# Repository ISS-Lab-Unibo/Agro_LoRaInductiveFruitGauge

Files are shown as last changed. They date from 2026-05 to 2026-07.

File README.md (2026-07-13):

# Agro_LoRaInductiveFruitGaug

A low-power wireless sensor node designed for high-resolution, non-destructive fruit growth monitoring and LoRa/LoRaWAN data transmission.
immagine

##Overview

The Agro LoRa Inductive Fruit Gauge is an autonomous sensor node developed for continuous and non-destructive fruit growth monitoring directly on the tree.

The system interfaces with up to eight inductive fruit gauges attached to the monitored fruits, periodically acquiring fruit diameter measurements and transmitting the collected data through a LoRa/LoRaWAN wireless communication interface.

The inductive sensing technology adopted by the fruit gauges provides a nominal diameter resolution of up to 71 µm over a 120 mm measurement range. Following the proposed non-linearity calibration procedure, the sensing system achieves a mean absolute diameter error of 111 µm and a maximum absolute diameter error below 247 µm.

The design and metrological characterization of the inductive fruit gauge are presented in:

> L. M. Peppi, A. Gallo, L. Manfrini, and L. De Marchi,
> “Inductive Sensor for Real-Time, Autonomous and Non-Destructive Fruit Size and Growth Monitoring,”
> *2025 IEEE International Workshop on Metrology for Agriculture and Forestry (MetroAgriFor)*, pp. 29–34, 2025.
> [IEEE Xplore](https://ieeexplore.ieee.org/document/11512426) | [DOI: 10.1109/MetroAgriFor66923.2025.11512426](https://doi.org/10.1109/MetroAgriFor66923.2025.11512426)

The high measurement resolution enables the detection of small fruit diameter variations associated with daily shrinkage and swelling cycles, making the system suitable for long-term fruit growth monitoring and plant water-status assessment in Precision Agriculture applications.

The repository contains all the hardware design files, embedded firmware, configuration software, and mechanical models required to reproduce and configure the proposed sensor node.

## Building the Sensor Node

Complete instructions for manufacturing, assembling, programming, and configuring the sensor node are provided in the dedicated building guide:

 **[Sensor Node Building Instructions](building_instructions.md)**

The guide describes the complete procedure required to reproduce the system, from PCB manufacturing and component assembly to firmware programming, fruit gauge assembly, and final node configuration.

## Repository Contents

The repository is organised into the following directories:

### [`3d models`](3d%20models)

Contains the mechanical design files required to manufacture the sensor node enclosure and the mechanical components of the fruit gauges.

The directory includes STL files for 3D printing and the corresponding editable CAD source files.

### [`Configuring software`](Configuring%20software)

Contains the software developed to configure and manage the sensor node.

The configuration software allows the main node parameters, sensor acquisition settings, and LoRa/LoRaWAN communication parameters to be configured before field deployment.

### [`Firmware`](Firmware)

Contains the embedded firmware of the sensor node.

The firmware implements fruit gauge acquisition, analog sensor acquisition, system power management, battery monitoring, and LoRa/LoRaWAN communication.

### [`Schematics and Gerbers`](Schematics%20and%20Gerbers)

Contains the electronic design and PCB manufacturing files.

The directory includes the electrical schematics and Gerber files required to manufacture the sensor node PCB.

### [`Images`](Images)

Contains photographs, diagrams, and graphical resources used throughout the repository documentation.

## Documentation

Each main directory contains dedicated `.md` documentation files describing the purpose of the provided files, their organisation, and the procedures required to use, manufacture, configure, or modify the corresponding system components.

Users are encouraged to refer to the documentation available in each directory before modifying the hardware, firmware, software, or mechanical components.

For the complete sensor node reproduction procedure, refer to the **[Sensor Node Building Instructions](building_instructions.md)**.

## How It Works

The sensor node periodically acquires measurements from the connected inductive fruit gauges. Each gauge estimates the fruit diameter by measuring the angular position between its two arms using a contactless inductive sensing technique.

The acquired SENT digital signals are decoded by the sensor node and converted into calibrated fruit diameter measurements. The collected data are subsequently processed and transmitted through the LoRa/LoRaWAN communication interface.

The low-power architecture of the node is designed to support autonomous and long-term field operation.

## System Composition

The complete system consists of:

* a low-power LoRa/LoRaWAN sensor node;
* up to eight high-resolution inductive fruit gauges;
* interfaces for additional analog sensors;
* an energy harvesting and battery power supply system;
* dedicated embedded firmware;
* sensor node configuration software;
* custom mechanical components and enclosures.

Detailed information about each subsystem is available in the corresponding repository directory.

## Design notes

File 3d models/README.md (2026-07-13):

# PLIERS PRODUCTION OVERVIEW and REQUIRED MATERIALS

This repository contains the design files, manufacturing files, and assembly references required for the gripper system and its integration with the pliers assembly.

## Folder Structure

### 1. `Grubber`
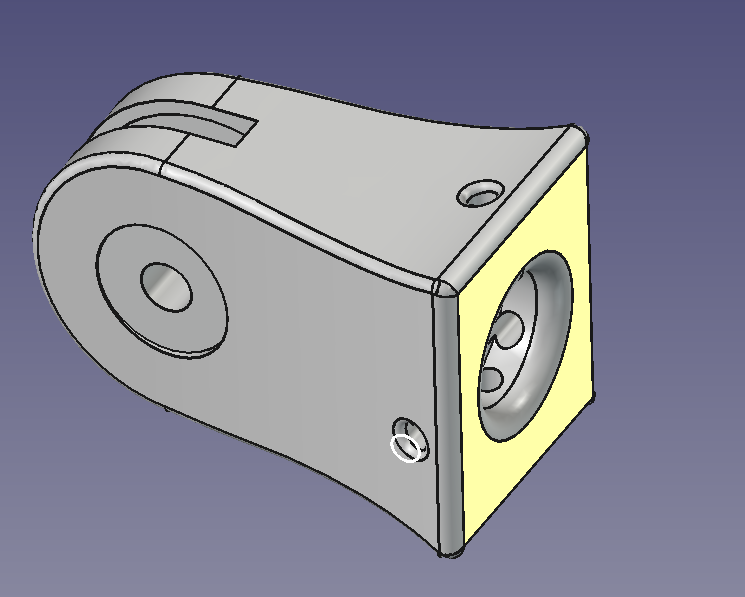
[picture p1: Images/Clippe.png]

This folder contains:

* FreeCAD CAD files of the grubbers that must be attached to the pliers.
* Printable `.stl` files corresponding to the grubber components.

These files are intended for manufacturing and assembly of the gripping elements.

---

### 2. `Pliers cad files and renderings`

This folder is provided **for reference purposes only**.

It contains:

* STEP files of the various pliers subassemblies and components.
* A complete rendering of the assembled pliers.
* The full pliers assembly in both STEP and FreeCAD formats.

These files are supplied to facilitate understanding of the overall assembly and integration of the grubbers.

---

### 3. `Teflon Disks`

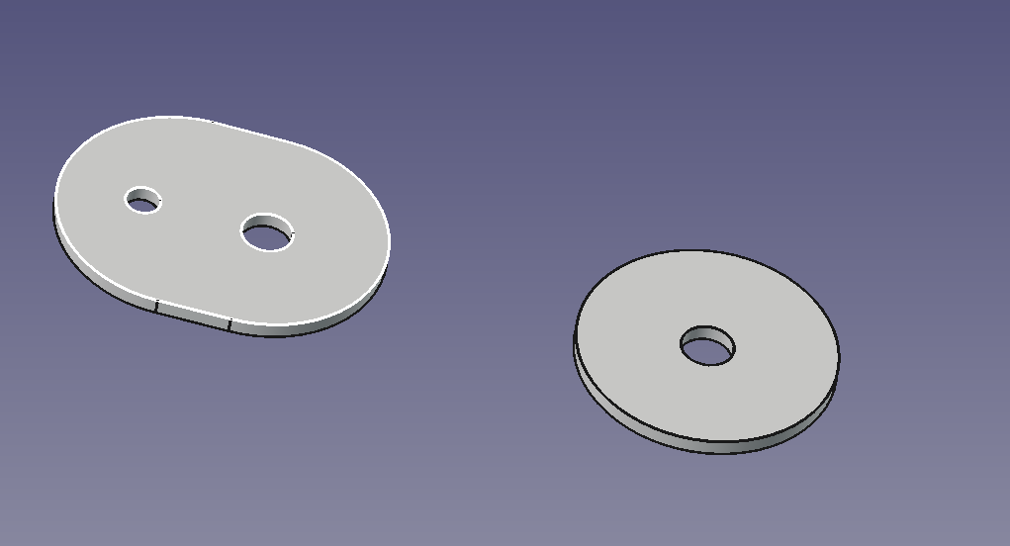
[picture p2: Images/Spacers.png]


This folder contains:

* `.stl` files of the spacers/disks that must be manufactured in PTFE (Teflon).

These components are required during the assembly of the pliers.

---

# Manufactured Parts List 

| Item | Part Name | Manufacturing Process (3D Printing / Machining) | Material | Quantity | File name|
| ---- | --- | --- | --- | --- | ----- |
|  1 | Grubbers 	| 3D printing | PETG | 2 |  clippa acciaio armonico-Body_v.02 |
|  2 |  Teflon spacer 1 | Machining |  Teflon 1mm thicknes | 2 |  Spessore_braccio.stl |
|  3 |  Teflon spacer 2 | Machining | Teflon 1mm thicknes |  2 |  Spessore_centrale.stl |

---

# Mechanical Hardware Bill of Materials (To Be Completed)

| Item | Description | Specification | Quantity | RS Code |
| ---- | --- | --- | --- | ----- |
|  1 | M2 bold | 1) To connect the grubbers to the plier's structure 2) to fix one arm of the plier |  3 |  560-271 |
| 2 | M2 screw 8mm |  To connect the grubbers to the plier's structure | 2 | 908-7637 |
| 3 |  RS 751-770, 0.63 mm Diam., ext Diam. 7mm, length 35mm, maximum length 101.5mm, k = 0.16N/mm, initial force = 12.2N | |  2 | |
| 4 |  M3 locknut | | 2 | |
| 5 |  M5 screw | | 2 | |
| 6 |  Self-tapping screw | | 2 | |
---

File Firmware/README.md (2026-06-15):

# Firmware

## STM32CubeIde_Project
this folder contains the STM32CubeIde Project, if you want to look at the source code.

Are you lazy? Do you want ony to flash the microcontrolloer? No problem: look at the..

## RAK3172_Ver_*<version>_<buil date>.hex file
Use it with STM32CubeProgrammer to flash the MCU. No building required.

## Chirpstack_decoder.js
If you use Chirpstack as LoRa server, use this Javascript to decode the received LoRa payload.

## lx3302a_config
File to be written into the LX3302A IC, with the MIcrochip LXM9518 Gen2 Programmer

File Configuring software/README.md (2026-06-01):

## Software for sensor node setup

### Python files
Source code of the software

### dist-windows-exe
No desire to mess around with Python code? I understand... that’s why there’s an executable file available (Windows only!) that doesn’t require any kind of runtime. Just download the "dist-windows-exe" folder (with the "ui" folder inside!) and execute the .exe file, and you’re all set.

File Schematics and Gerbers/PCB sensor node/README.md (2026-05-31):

## Design and production files for the pliers

### KiCad project
This folder contains the KiCad project files for the design of the pliers.

### Gerber production files
This folder contains a .ZIP file with all the Gerber files required for the manufacture of the pliers by external suppliers. It also includes the BOM and component placement (CPL) files.

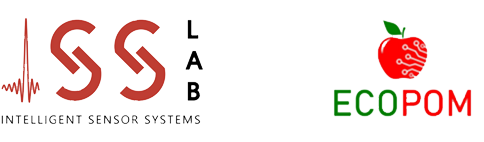
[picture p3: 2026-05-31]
Configuring software/python files/img/ISS-ECOPOM.png

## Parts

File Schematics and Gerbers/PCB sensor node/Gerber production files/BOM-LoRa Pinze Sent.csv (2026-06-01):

Comment | Designator | Footprint | LCSC | Quantity
0.47u | C2 | C_0603_1608Metric_Pad1.08x0.95mm_HandSolder | C1623 | 1
10 | R20,R21,R22,R23 | R_0402_1005Metric | C25077 | 4
100k | R13,R14,R15,R24,R25 | R_0402_1005Metric | C25741 | 5
100n | C1,C10,C11,C15,C20,C21,C22,C3,C34,C35,C36,C41,C42,C5,C7,C87,Cbyp1 | C_0402_1005Metric_Pad0.74x0.62mm_HandSolder | C1525 | 17
100p | C26 | C_0402_1005Metric_Pad0.74x0.62mm_HandSolder | C1546 | 1
10k | R10,R4,R5,R9 | R_0402_1005Metric | C25744 | 4
10n | C30,Cref1 | C_0402_1005Metric_Pad0.74x0.62mm_HandSolder | C15195 | 2
10p | C24,C37,C38,C44,C47,C51,C53,C56,C59,C62,C65,C68,C70,C72 | C_0402_1005Metric_Pad0.74x0.62mm_HandSolder | C32949 | 14
12k | R47,R49,R51,R53,R55,R57,R59,R61,R63,R65,R67,R69,R71,R73,R75,R77 | R_0402_1005Metric | C25752 | 16
1k | R79 | R_0402_1005Metric | C11702 | 1
1u | C12,C13,C23,C39,C4,C40,C43,C45,C46,C48,C49,C50,C52,C54,C55,C57,C58,C60,C61,C63,C64,C66,C67,C69,C71,C73,C8 | C_0402_1005Metric_Pad0.74x0.62mm_HandSolder | C52923 | 27
200k | R18,R19 | R_0402_1005Metric | C25764 | 2
220 | R1,R30 | R_0402_1005Metric_Pad0.72x0.64mm_HandSolder | C25091 | 2
22k | R48,R50,R52,R54,R56,R58,R60,R62,R64,R66,R68,R70,R72,R74,R76,R78 | R_0402_1005Metric | C25768 | 16
22u | C17 | C_0805_2012Metric_Pad1.18x1.45mm_HandSolder | C45783 | 1
2k2 | R6,R7 | R_0402_1005Metric | C25879 | 2
3,9M | Rok3 | R_0402_1005Metric_Pad0.72x0.64mm_HandSolder | C30329 | 1
3.3p | C28,C29 | C_0402_1005Metric_Pad0.74x0.62mm_HandSolder | C1565 | 2
33 | R28,R29 | R_0402_1005Metric | C25105 | 2
4,3M | Roc1 | R_0402_1005Metric_Pad0.72x0.64mm_HandSolder | C327242 | 1
4.7M | Rout2 | R_0402_1005Metric_Pad0.72x0.64mm_HandSolder | C49654986 | 1
4.7u | C16 | C_0402_1005Metric_Pad0.74x0.62mm_HandSolder | C23733 | 1
4u7 | C6,C9 | C_0402_1005Metric_Pad0.74x0.62mm_HandSolder | C23733 | 2
5,62M | Rov2 | R_0402_1005Metric_Pad0.72x0.64mm_HandSolder | C2929925 | 1
53398-0371 | J5,J6,J7,J8 | 533980371 | C17246903 | 4
53398-0471 | J10,J11,J12,J13,J14,J15,J16,J9 | 533980471 | C17617036 | 8
56k | R31,R32 | R_0402_1005Metric | C23206 | 2
6,2M | Roc2 | R_0402_1005Metric_Pad0.72x0.64mm_HandSolder | C159000 | 1
6,8M | Rok2 | R_0402_1005Metric_Pad0.72x0.64mm_HandSolder | C620473 | 1
7,5M | Rov1 | R_0402_1005Metric_Pad0.72x0.64mm_HandSolder | C137839 | 1
744031220 | L4 | WE-TPC_381692 | C5523436 | 1
74479889310 | L5 | INDC2521X120N | C191565 | 1
8,2M | Rout1 | R_0402_1005Metric_Pad0.72x0.64mm_HandSolder | C172186 | 1
910k | Rok1 | R_0402_1005Metric_Pad0.72x0.64mm_HandSolder | C324817 | 1
BAV199 | D1,D2,D21,D22,D23,D24,D25,D26,D27,D28,D29,D3,D30,D31,D32,D33,D34,D35,D36,D4 | SOT95P230X100-3N | C145516 | 20
BLM15HG102SN1D | FB1,FB2,FB3 | NFZ15SG152SN10B | C76889 | 3
BQ25570 | U2 | QFN-20-1EP_3.5x3.5mm_P0.5mm_EP2x2mm | C506250 | 1
C0805C475K9RACTU 4,7u | C31 | C0805 | C1779 | 1
CH340E | U3 | MSOP-10_3x3mm_P0.5mm | C99652 | 1
DFE201612E-2R2M=P2 | L2 | 1286ASH1R0MP2 | C337893 | 1
GT-USB-7055BB | J17 | GTUSB7055BB | C7450621 | 1
JMK212BJ226MG-T 22u | C33 | CAPC2013X135N | C87158 | 1
KT-0603R | LED1,LED2 | LEDC1608X70N | C2286 | 2
LMK212B7475KG-T | C32 | CAPC2012X135N | C92810 | 1
LQW15AN8N2J00D | L3 | LQW15CNR20J00B | C98066 | 1
MLZ2012N150LT000 | L1 | INDC2012X105N | C531290 | 1
NCP115ASN330T2G | IC11 | SOT95P275X110-5N | C603505 | 1
RAK3172-SiP | IC1 | RAK3172SiP | C19818882 | 1
Reset(Black) | B2 | TS046655BK160SMT | C5340119 | 1
SN74HCS151PWR | IC12,IC5 | SOP65P640X120-16N | C2877065 | 2
TCA9534PWR | IC6 | SOP65P640X120-16N | C783615 | 1
TMUX1204DGSR | IC7 | SOP50P490X110-10N | C2840022 | 1
TMUX1219DCKR | IC25,IC8,IC9 | SOT65P210X110-6N | C2867958 | 3
TPS22917DBVR | IC13,IC14,IC15,IC16,IC17,IC18,IC19,IC20,IC21,IC22,IC23,IC24 | SOT95P280X145-6N | C2681320 | 12
TPS613222ADBVR | IC2 | SOT95P280X145-5N | C2071163 | 1
U.FL-R-SMT-1_10_ | J4 | U.FL-R-SMT-1_10_ | C88374 | 1
USBLC6-2SC6 | IC10 | SOT95P280X145-6N | C2827654 | 1

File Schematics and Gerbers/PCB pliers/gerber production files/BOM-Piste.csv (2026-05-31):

Comment | Designator | Footprint | LCSC | Quantity
100n | C2,C6,C7 | C_0402_1005Metric_Pad0.74x0.62mm_HandSolder | C1525 | 3
10k | R4,R5 | R_0402_1005Metric_Pad0.72x0.64mm_HandSolder | C25744 | 2
1n | C1 | C_0402_1005Metric_Pad0.74x0.62mm_HandSolder | C1523 | 1
1u | C3 | C_0402_1005Metric_Pad0.74x0.62mm_HandSolder | C52923 | 1
56k | R6 | R_0402_1005Metric_Pad0.72x0.64mm_HandSolder | C25796 | 1
680p | C4,C5 | C_0402_1005Metric_Pad0.74x0.62mm_HandSolder | C1630 | 2
LX3302AQPW-TR | IC1 | SOP65P640X120-14N | C3237416 | 1
MCP6541T-I_OT | IC2 | SOT95P270X145-5N | C80839 | 1
LMT01DQX | U1 | Texas_DQX002A |  | 1

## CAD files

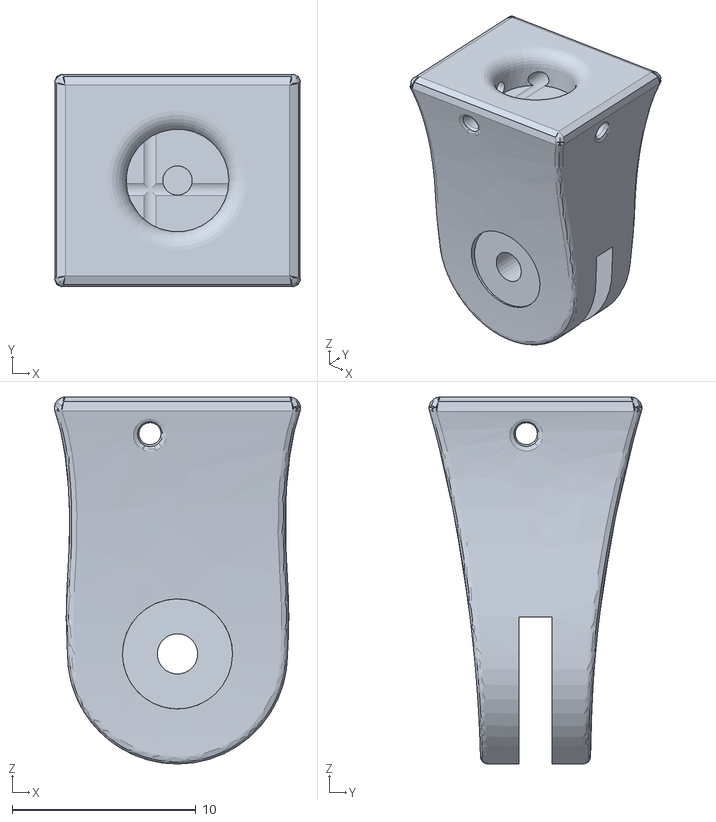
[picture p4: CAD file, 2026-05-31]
3d models/Grubber/clippa acciaio armonico-Body_v.02.stl
13.4 x 11.6 x 20.0

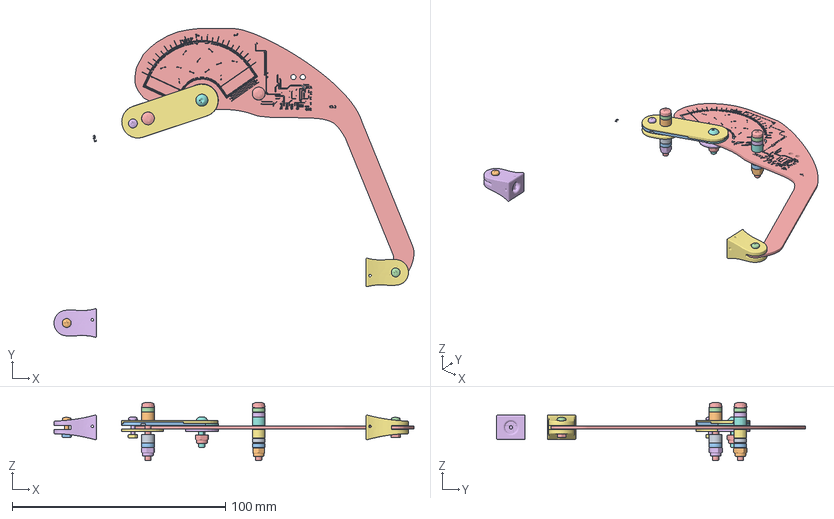
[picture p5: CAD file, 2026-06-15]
3d models/Pliers cad files and renderings/Rendering.FCStd
168.7 x 144.6 x 27.4 mm
TargetGrande_silkscreen
spacerGrande_silkscreen
spacerGrande_PCB
Braccio_silkscreen
AutobloccanteM3
BulloneM2
DadoM2
DadoM310mm
distanziale4mm
distanziale4mm001
distanziale2mm
distanziale2mm001
BN 3334 1538667 cross recessed pan head machine screw M3x25
AutobloccanteM001
SpacerGrande
B0528.1503X12
Piste_copper
Piste_via
Piste_silkscreen
Piste_silkscreen001
Piste_PCB
distanziale2mm002
distanziale4mm002
distanziale4mm003
distanziale2mm003
AutobloccanteM002
distanziale2mm004
distanziale2mm005
BN 3334 1538667 cross recessed pan head machine screw M3x001
Rondellona
SpacerBraccio001
Rondellona2
SpacerBraccio002
BulloneM001
DadoM002
BulloneM002
DadoM003
clippa acciaio armonico-Body
clippa acciaio armonico-Body001

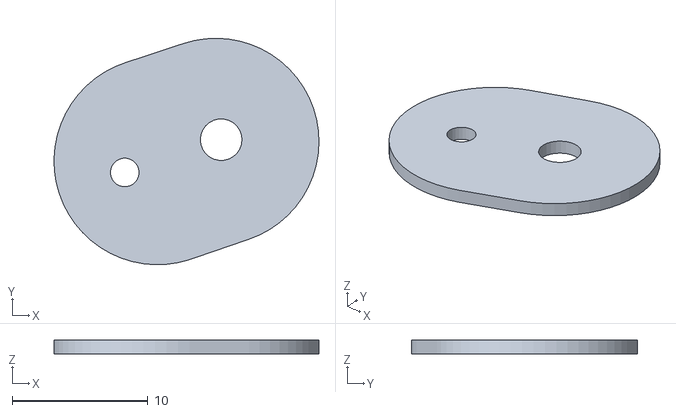
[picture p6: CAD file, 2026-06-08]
3d models/Teflon disks/Spessore_braccio.stl
19.5 x 16.7 x 1.00

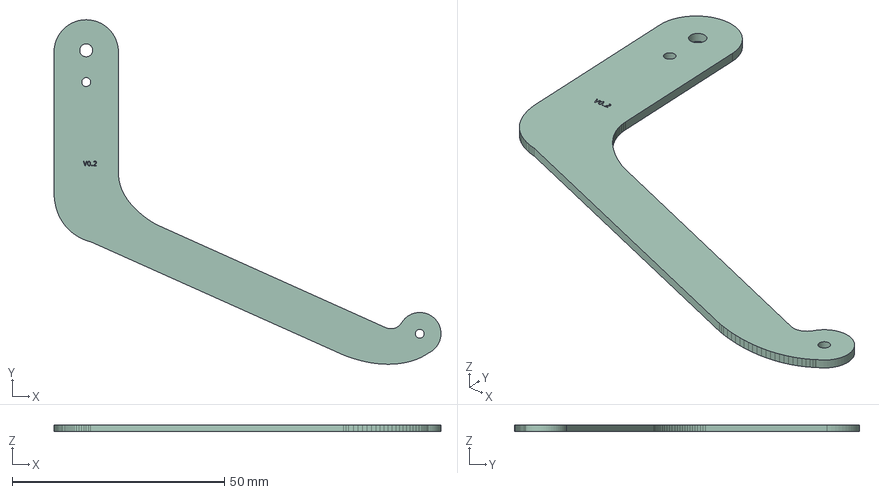
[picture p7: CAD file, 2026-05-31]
3d models/Pliers cad files and renderings/Braccio.step
91.2 x 81.2 x 1.58 mm
Braccio_silkscreen
Braccio_PCB

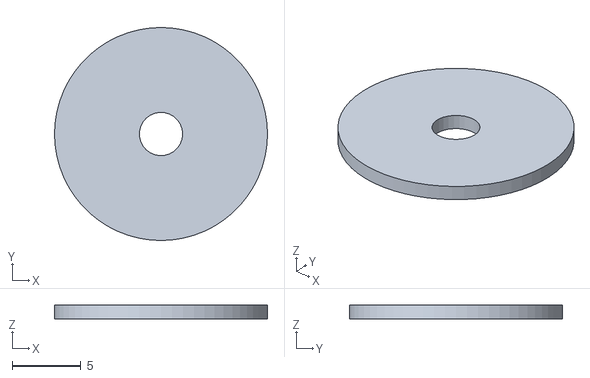
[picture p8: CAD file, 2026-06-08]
3d models/Teflon disks/Spessore_centrale.stl
15.5 x 15.5 x 1

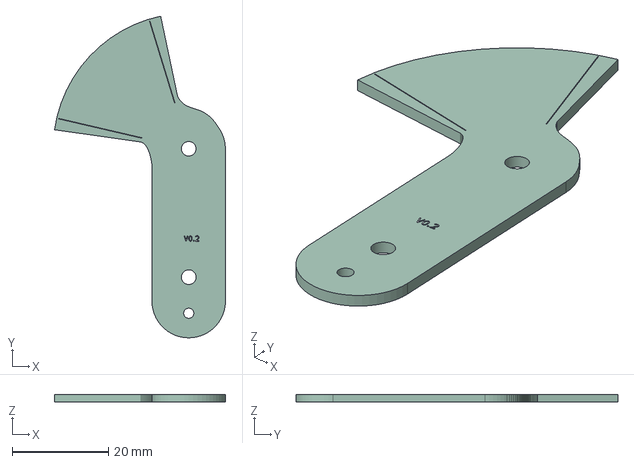
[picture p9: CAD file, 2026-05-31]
3d models/Pliers cad files and renderings/Target.step
35.5 x 66.7 x 1.58 mm
TargetGrande_silkscreen
TargetGrande_PCB

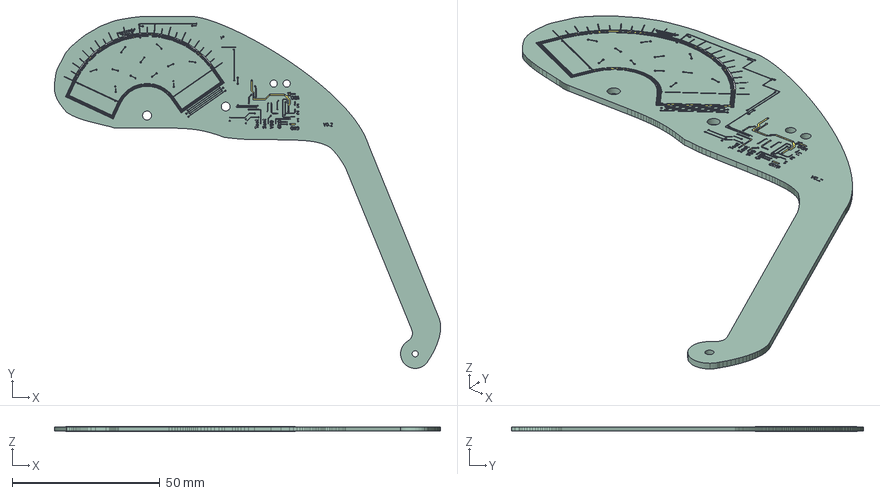
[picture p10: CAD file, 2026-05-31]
3d models/Pliers cad files and renderings/Piste.step
130.8 x 119.2 x 1.66 mm
Piste_copper
Piste_via
Piste_silkscreen x 2
Piste_PCB

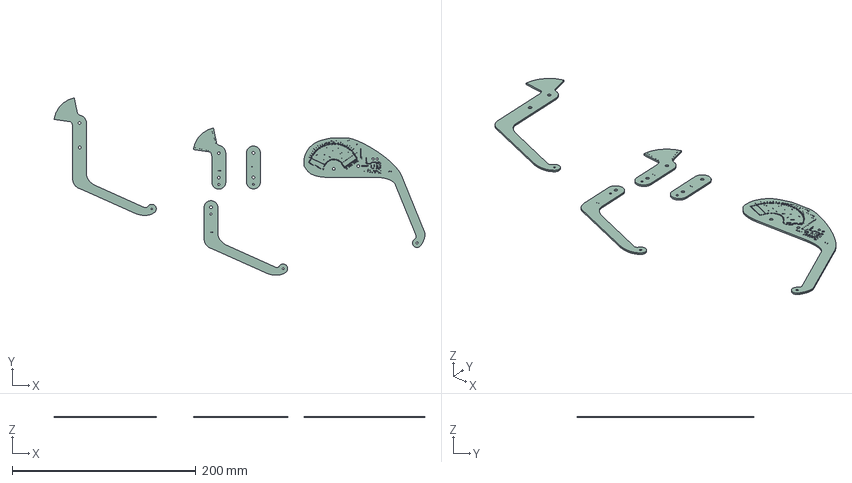
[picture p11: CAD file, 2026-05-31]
3d models/Pliers cad files and renderings/All_outline.step
404.1 x 193.3 x 1.66 mm
BraccioPisteMCU_stampa_copper
BraccioPisteMCU_stampa_via
BraccioPisteMCU_stampa_silkscreen x 2
BraccioPisteMCU_stampa_PCB_1
BraccioPisteMCU_stampa_PCB_2
BraccioPisteMCU_stampa_PCB_3
BraccioPisteMCU_stampa_PCB_4
BraccioPisteMCU_stampa_PCB_5

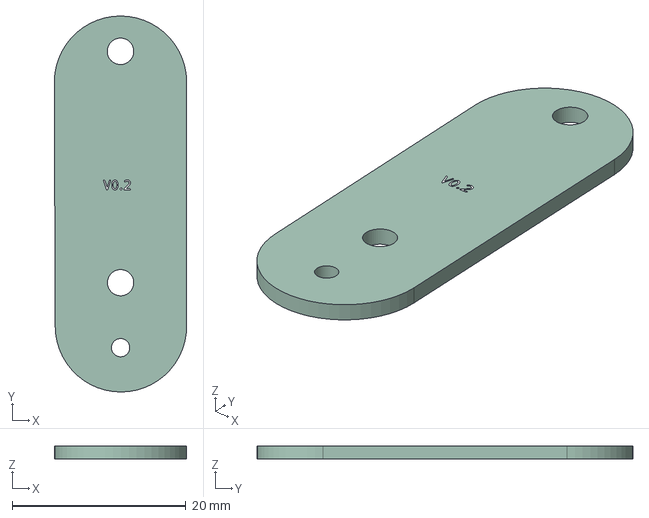
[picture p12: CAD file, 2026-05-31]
3d models/Pliers cad files and renderings/Spacer.step
15.2 x 43.3 x 1.58 mm
spacer_silkscreen
spacer_PCB

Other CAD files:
3d models/Grubber/clippa acciaio armonico_v.02.FCStd

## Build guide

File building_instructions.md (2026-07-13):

# Sensor Node Building Instructions

This document describes the main steps required to manufacture, program, and mechanically assemble the Agro LoRa Inductive Fruit Gauge sensor node and the associated inductive fruit gauges.

The procedure is organised into four main stages:

1. Required materials and tools
2. Sensor node PCB programming
3. Inductive fruit gauge programming
4. Mechanical assembly of the fruit gauges

---

# 1. Required Materials and Tools

Before starting the assembly procedure, all the electronic, mechanical, and programming components listed in the following table should be available.

| Category | Item | Description / Part Number | Quantity |
| --- | --- | --- | --- |
| PCB | Assembled sensor node PCB | PCB manufactured from the Gerber files available in [`Schematics and Gerbers/PCB sensor node`](Schematics%20and%20Gerbers/PCB%20sensor%20node) | 1 |
| PCB | Inductive fruit gauge PCB | PCB manufactured from the Gerber files available in [`Schematics and Gerbers/PCB pliers`](Schematics%20and%20Gerbers/PCB%20pliers). 1X GERBER-Braccio, 1X GERBER-Piste, 1X GERBER-spacer, 1x GERBER-TargetGrande. | 1 set per fruit gauge |
| 3D printed part | Fruit gripping elements | `clippa acciaio armonico-Body_v.02.stl`, available in [`3d models/Grubber`](3d%20models/Grubber) | 2 per fruit gauge |
| Mechanical material | PTFE sheet | 1 mm thick PTFE (Teflon) sheet. The sheet must be machined according to the geometries provided in the [`Teflon disks`](3d%20models/Teflon%20disks) directory | 2 set per fruit gauge |
| Mechanical hardware | M2 nut | M2 nut used for the fruit gauge mechanical assembly. RS Code 908-7637 | 3 per fruit gauge |
| Mechanical hardware | M2 screw | M2 × 8 mm screw used to connect the gripping elements to the fruit gauge structure + . RS code  560-271 | 3 per fruit gauge |
| Mechanical hardware | M3 locknut | M3 locknut used for the fruit gauge mechanical assembly. RS Code 521-917 | 3 per fruit gauge |
| Mechanical hardware | M3 screw | M3 × 25 mm screw. RS code  560-271 | 3 per fruit gauge |
| Mechanical hardware | Self-tapping screw | Required to fix harmonic steel to grippers. RS code  287-4014 | 2 per fruit gauge |
| Mechanical hardware | Spring | RS 751-770, 0.63 mm Diam., ext Diam. 7mm, length 35mm, maximum length 101.5mm, k = 0.16N/mm, initial force = 12.2N | 2 per fruit gauge |
| Mechanical hardware | harmonic steel wire |  Diam harmonic steel wire | 4 per fruit gauge |
| Mechanical hardware | **TO BE COMPLETED** | **Additional central joint hardware / bearing specifications to be added** | **TBD** |
| Enclosure | **ENCLOSURE PART NUMBER TO BE ADDED** | Weather-resistant enclosure for the sensor node electronics | 1 |
| Battery | Battery | | 1 per sensor node |
| Connector | Fruit gauge connector | Connector used to connect each inductive fruit gauge to the sensor node | 1 per fruit gauge |
| Cable | UNITRONIC® LiYY | LAPP 0028304 cable used to connect the inductive fruit gauges to the sensor node | As required |
| Programmer | LXM9518 | Microchip programmer for the LX3302A inductive position sensor interface IC | 1 |
| MCU programmer | ST-LINK or SEGGER programmer | SWD-compatible programmer for programming the sensor node MCU | 1 |
| Software | STM32CubeProgrammer | ST software used to program the sensor node MCU | — |
| Software | IPCE | Microchip Integrated Programming and Calibration Environment used with the LXM9518 programmer | — |

The UNITRONIC® LiYY LAPP 0028304 cable is used for the electrical connection between each fruit gauge and the sensor node. Its PVC-based cable construction is suitable for the proposed outdoor installation and is adopted to improve the robustness of the sensor interconnection against environmental exposure, including sunlight and the associated UV radiation.

> **Note:** The exact sensor node enclosure part number must be added before finalising this document.
---

# 2. PCB Manufacturing

The system requires different PCB designs:

* the main sensor node PCB;
* the inductive fruit gauge PCB.

The corresponding manufacturing files are provided in the [`Schematics and Gerbers`](Schematics%20and%20Gerbers) directory.

## 2.1 Sensor Node PCB

The sensor node PCB manufacturing files are available in:

[`Schematics and Gerbers/PCB sensor node`](Schematics%20and%20Gerbers/PCB%20sensor%20node)

The `Gerber production files` directory contains the files required for PCB manufacturing and assembly

The provided production package includes the Gerber files and the associated BOM and component placement information required by an external PCB assembly service. Remember the assembly for the GERBER-LoRa Pinze Sent PCB. Bill of Materials and placement files are available in the same folder.

## 2.2 Inductive Fruit Gauge PCB

The fruit gauge PCB manufacturing files are available in:

[`Schematics and Gerbers/PCB pliers`](Schematics%20and%20Gerbers/PCB%20pliers): 
1X GERBER-Braccio, 1X GERBER-Piste, 1X GERBER-spacer, 1x GERBER-TargetGrande

The corresponding Gerber production files must be used to manufacture the PCB forming the main structural and sensing elements of the inductive fruit gauge.

The PCB integrates the inductive sensing coils and the LX3302A-based acquisition electronics. Remember the assembly for the GERBER-Piste PCB. Bill of Materials and placement files are available in the same folder.

---

# 3. Sensor Node MCU Programming

The sensor node MCU must be programmed before the final assembly of the system.

The recommended programming procedure uses STM32CubeProgrammer and an SWD-compatible programmer, such as an ST-LINK or a SEGGER programming probe.

## 3.1 Required Software

Download and install STM32CubeProgrammer from the official STMicroelectronics website.

The precompiled firmware binary provided in the [`Firmware`](Firmware) directory is the recommended firmware image for reproducing the sensor node.

The complete firmware source code is also available in the repository. Advanced users may download the source code, configure the development environment, and compile the firmware independently.

However, **building the firmware from source is not recommended for standard sensor node reproduction**, since compiler versions, library dependencies, and project configuration may affect the resulting firmware behaviour.

For this reason, the provided precompiled firmware image should normally be used.

## 3.2 Connecting the Programmer

Connect the ST-LINK or SEGGER programmer to the sensor node programming interface.

The sensor node programming connector pinout is reported in the following table. **Pin 1 is identified on the PCB by a white dot printed next to the connector.**

| Pin | Signal | Description |
| --- | --- | --- |
| 1 | `VDD_TARGET` | Target voltage sensing input. Used by the programming probe to measure the target voltage. This connection is optional and can normally be left disconnected when the sensor node is powered separately. |
| 2 | `SWCLK` | Serial Wire Debug clock line. |
| 3 | `GND` | Ground reference. |
| 4 | `SWDIO` | Serial Wire Debug bidirectional data line. |
| 5 | `NRST` | MCU hardware reset line. |
| 6 | `NC` | Not connected. |

> **Note:** Pin 1 (`VDD_TARGET`) is marked on the sensor node PCB by a **white dot**, which can be used as a reference to determine the programming connector orientation.

### Programming connection

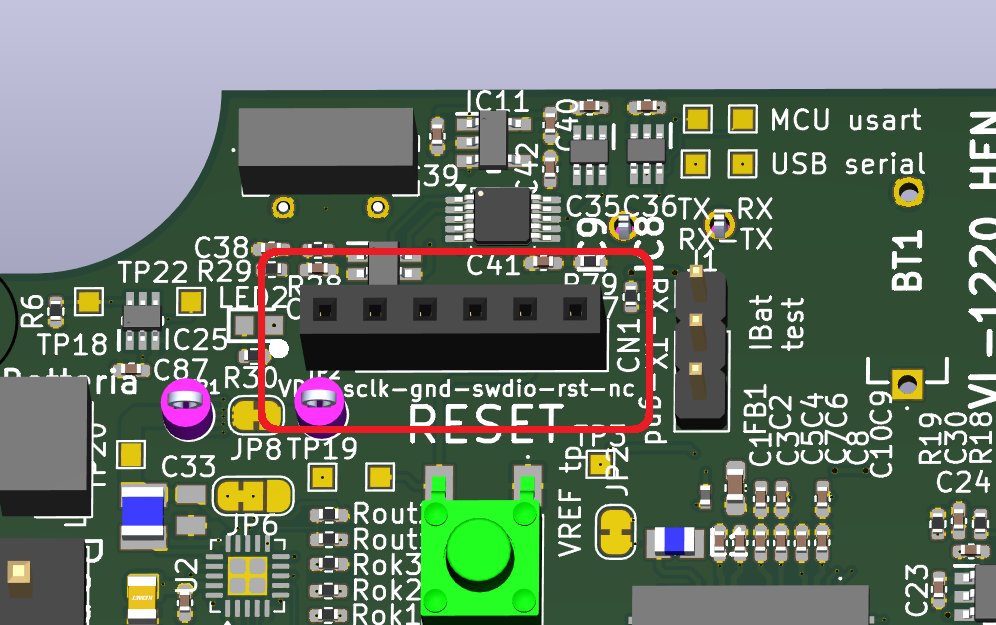
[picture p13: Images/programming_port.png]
Logo di esempio


*Figure X. Connection of the programming probe to the sensor node PCB.*

## 3.3 Programming with STM32CubeProgrammer

The following procedure can be used to program the sensor node:

1. Connect the programming probe to the sensor node PCB.
2. Connect the programmer to the computer.
3. Open STM32CubeProgrammer.
4. Select `ST-LINK` as the programming interface when using an ST-LINK probe.
5. Configure the SWD connection.
6. Press **Connect**.
7. Verify that the target MCU is correctly detected.
8. Open the firmware programming section.
9. Select the precompiled firmware file provided in the repository.
10. Verify the firmware start address according to the supplied firmware image.
11. Start the programming procedure.
12. Wait for the programming and verification process to complete.
13. Disconnect STM32CubeProgrammer.
14. Remove the programming probe from the sensor node.

### STM32CubeProgrammer — Step 1

<!-- INSERT IMAGE: STM32CubeProgrammer connection configuration -->

STM32CubeProgrammer connection

*Figure X. STM32CubeProgrammer connection configuration.*

### STM32CubeProgrammer — Step 2

<!-- INSERT IMAGE: Firmware file selection -->

STM32CubeProgrammer firmware selection

*Figure X. Selection of the precompiled sensor node firmware.*

### STM32CubeProgrammer — Step 3

<!-- INSERT IMAGE: Programming and verification -->

STM32CubeProgrammer programming

*Figure X. Firmware programming and verification.*

After programming, disconnect the programming probe and power-cycle the sensor node.

---

# 4. LX3302A Programming

Each inductive fruit gauge integrates a Microchip LX3302A inductive position sensor interface IC.

Before the fruit gauge can be used, the LX3302A must be programmed with the appropriate sensor configuration.

Programming is performed using the Microchip LXM9518 programmer and the Integrated Programming and Calibration Environment (IPCE).

The LXM9518 programmer is described on the Microchip website:

[LXM9518 Programmer](https://www.microchip.com/en-us/development-tool/lxm9518)

## 4.1 Required Equipment

The following components are required:

* one LXM9518 programmer;
* the Microchip IPCE software;
* the inductive fruit gauge PCB;
* the appropriate programming cable or adapter.

## 4.2 Connecting the Fruit Gauge

During programming, the programming connector must be manually held against the programming contacts available on the fruit gauge PCB.

The connector must remain correctly positioned and in electrical contact with the PCB for the entire programming procedure.

The required connector position is shown in the following figures.

### Programming connector position

<!-- INSERT IMAGE: Programming connector held against the fruit gauge -->

LX3302A programming connector

*Figure X. Programming connector manually held against the fruit gauge programming interface.*

### Detail of the programming contacts

<!-- INSERT IMAGE: Detail of programming pads -->

LX3302A programming pads

*Figure X. Detail of the LX3302A programming contacts.*

> **Important:** The programming connector must be kept firmly in position by hand throughout the programming procedure. An intermittent electrical contact may interrupt communication with the LX3302A.

A dedicated pogo-pin programming fixture is currently under development. This fixture will simplify the programming procedure and provide a more repeatable electrical connection to the fruit gauge programming pads.

## 4.3 Programming with IPCE

Connect the LXM9518 programmer to the computer and start the Microchip IPCE software.

The recommended programming procedure is:

1. Connect the LXM9518 programmer to the computer.
2. Open IPCE.
3. Position the programming connector on the fruit gauge programming contacts.
4. Keep the connector firmly pressed against the PCB.
5. Verify that the LX3302A is detected by IPCE.
6. Load the LX3302A configuration provided with this repository.
7. Verify the programmed sensor parameters.
8. Start the EEPROM programming procedure.
9. Wait until the programming process has completed.
10. Verify the programmed configuration.
11. Remove the programming connector from the fruit gauge.

### IPCE — Device connection

<!-- INSERT IMAGE: IPCE device detection -->

IPCE device connection

*Figure X. LX3302A detection using the IPCE software.*

### IPCE — Configuration loading

<!-- INSERT IMAGE: IPCE configuration loading -->

IPCE configuration loading

*Figure X. Loading the LX3302A configuration.*

### IPCE — EEPROM programming

<!-- INSERT IMAGE: LX3302A EEPROM programming -->

IPCE programming

*Figure X. Programming the LX3302A internal configuration memory.*

The LXM9518 and IPCE are specifically intended for configuration and calibration of Microchip inductive position sensor ICs. The LX3302A stores its digital calibration and configuration parameters in non-volatile EEPROM.

---

# 5. Fruit Gauge Mechanical Assembly

After the PCB has been manufactured and the LX3302A programmed, the mechanical components of the fruit gauge can be assembled.

The mechanical design files are available in the [`3d models`](3d%20models) directory.

## 5.1 Manufacturing the PTFE Spacers

The fruit gauge uses PTFE spacers to reduce friction between the moving PCB elements and allow smooth relative rotation of the two arms.

A **1 mm thick PTFE sheet** must be machined according to the geometries provided in the [`Teflon disks`](3d%20models/Teflon%20disks) directory.

The following spacer geometries are provided:

* `Spessore_braccio.stl/.svg`;
* `Spessore_centrale.stl/.svg`.

The STL or SVG files define the required external geometry of the PTFE components and can be used as a dimensional reference for machining or cutting the 1 mm PTFE sheet.

Two units of each spacer geometry are required for the complete fruit gauge assembly.

### PTFE spacer geometry

PTFE spacer geometry

*Figure X. PTFE spacer geometries manufactured from a 1 mm thick PTFE sheet.*

## 5.2 Manufacturing the Fruit Gripping Elements

Two fruit gripping elements must be manufactured for each fruit gauge.

The printable STL file is available in the [`Grubber`](3d%20models/Grubber) directory:

`clippa acciaio armonico-Body_v.02.stl`

The corresponding editable FreeCAD source file is also provided.

The gripping elements should be 3D printed in PETG.

CLIPPE geometry

Two identical components are required for each fruit gauge.

Each fruit gripping element must be equipped with two spring steel wires. The two wires must pass through the dedicated holes provided inside each gripper and be secured in position using a self-tapping screw.

After installation, the spring steel wires must be bent to form a suitable gripping profile, allowing them to gently engage with the fruit surface and keep the fruit gauge correctly positioned during the monitoring period.

If required, the portions of the spring steel wires that come into contact with the fruit can be covered with heat-shrink tubing. This can provide a softer contact surface and reduce direct contact between the metal wires and the fruit skin.

<!-- INSERT IMAGE: Spring steel wire installation and bending -->

Spring steel wire installation

*Figure X. Installation, fastening, and bending of the spring steel wires inside the fruit gripping element.*

## 5.3 Mechanical Assembly

The different components must be assembled according to the exploded view shown below.

### Fruit gauge exploded view

<!-- INSERT IMAGE: Complete exploded view -->

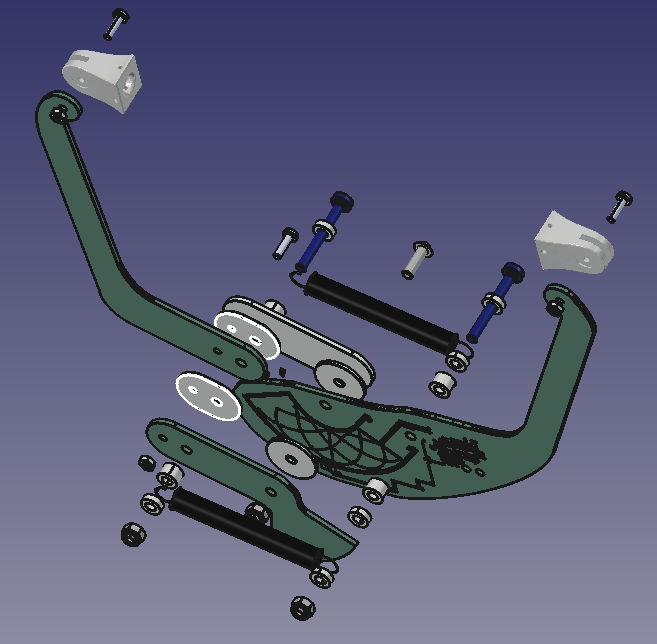
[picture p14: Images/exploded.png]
Fruit gauge exploded view


*Figure X. Exploded view of the inductive fruit gauge assembly.*

The recommended assembly sequence is as follows:

1. Prepare the two fruit gauge PCB arms.
2. Position the PTFE spacers according to the exploded view.
3. Align the central rotation interfaces of the two PCB arms.
4. Install the central mechanical joint components.
5. Assemble the two PCB arms while ensuring free relative rotation.
6. Install the two PETG fruit gripping elements.
7. Fix each gripping element using the M2 × 8 mm screws and M2 nuts.
8. Verify the alignment of the two fruit gripping elements.
9. Manually open and close the fruit gauge.
10. Verify that the two arms rotate smoothly and without significant mechanical interference.

The PTFE components must remain correctly positioned between the moving surfaces during assembly.

After tightening the mechanical fasteners, verify that the fruit gauge can move freely throughout its operating range.

Excessive tightening of the central joint may increase friction and negatively affect the detection of small fruit diameter variations.

---

# 6. Final Assembly

Once the fruit gauges and the sensor node have been programmed and mechanically assembled, the system can be interconnected.

Connect each inductive fruit gauge to the sensor node using the UNITRONIC® LiYY LAPP 0028304 cable and the selected connectors.

Verify the cable wiring and connector pinout before connecting the fruit gauge to the sensor node.

### Fruit gauge cable connection

<!-- INSERT IMAGE: Cable connection between fruit gauge and sensor node -->

Fruit gauge cable connection

*Figure X. Connection between an inductive fruit gauge and the sensor node.*

Install the sensor node PCB inside the selected **ENCLOSURE PART NUMBER TO BE ADDED** enclosure.

After completing the assembly, verify:

* sensor node power-up;
* communication with each connected fruit gauge;
* valid SENT data acquisition;
* LoRa/LoRaWAN configuration;
* wireless data transmission.

The sensor node can then be configured using the dedicated software provided in the [`Configuring software`](Configuring%20software) directory.

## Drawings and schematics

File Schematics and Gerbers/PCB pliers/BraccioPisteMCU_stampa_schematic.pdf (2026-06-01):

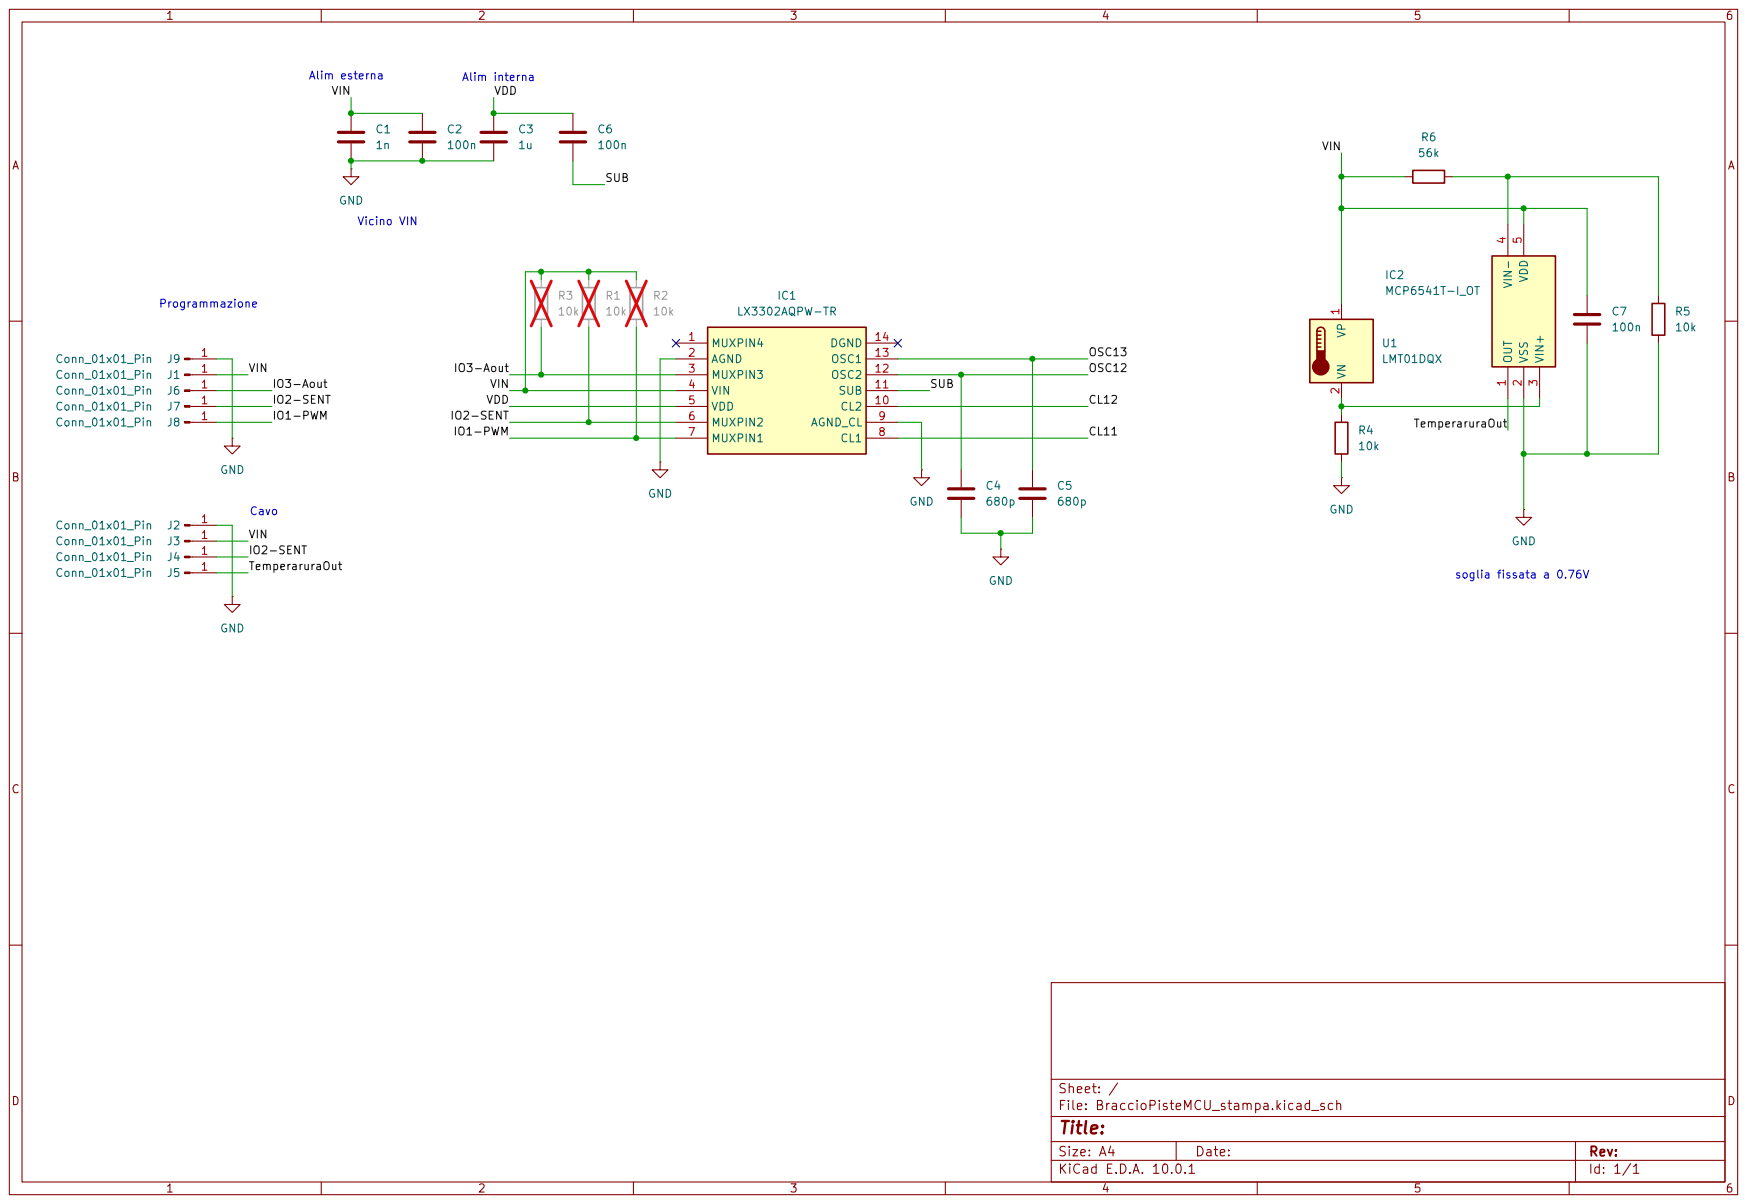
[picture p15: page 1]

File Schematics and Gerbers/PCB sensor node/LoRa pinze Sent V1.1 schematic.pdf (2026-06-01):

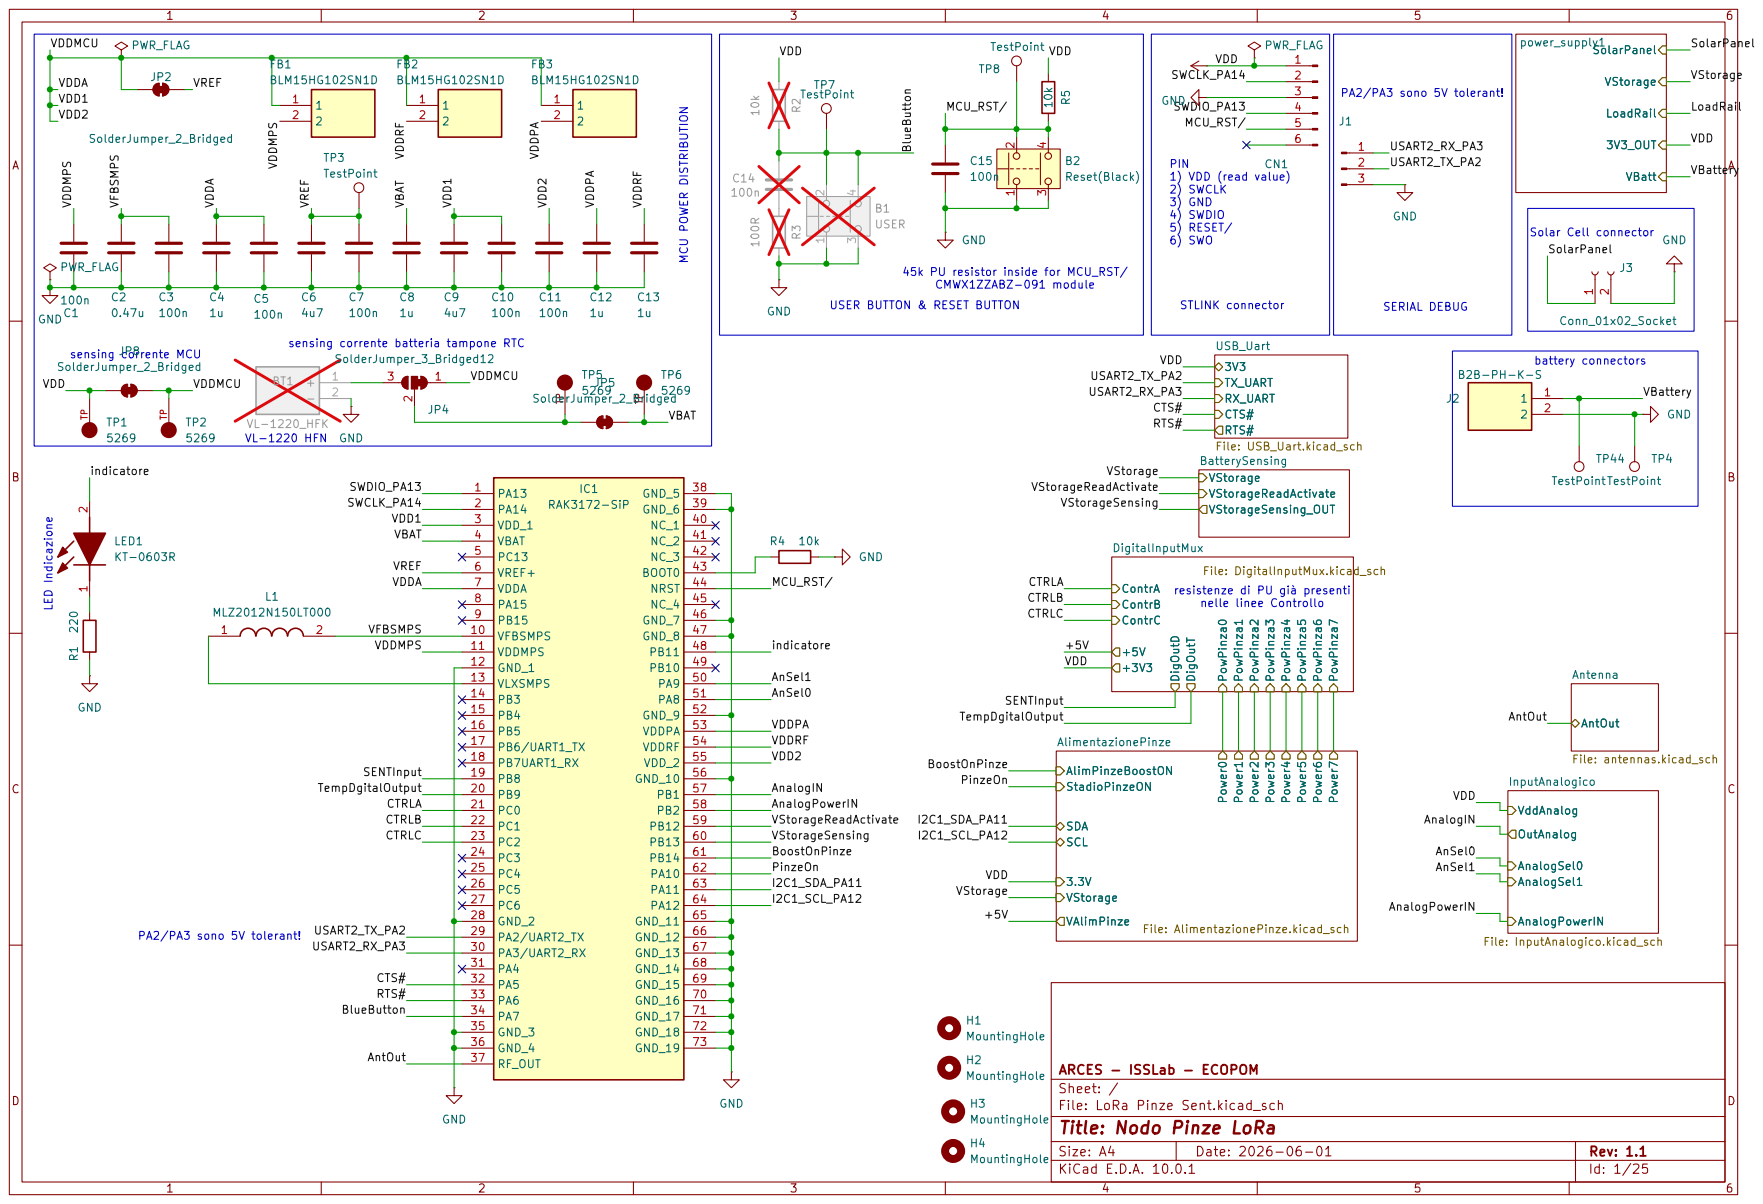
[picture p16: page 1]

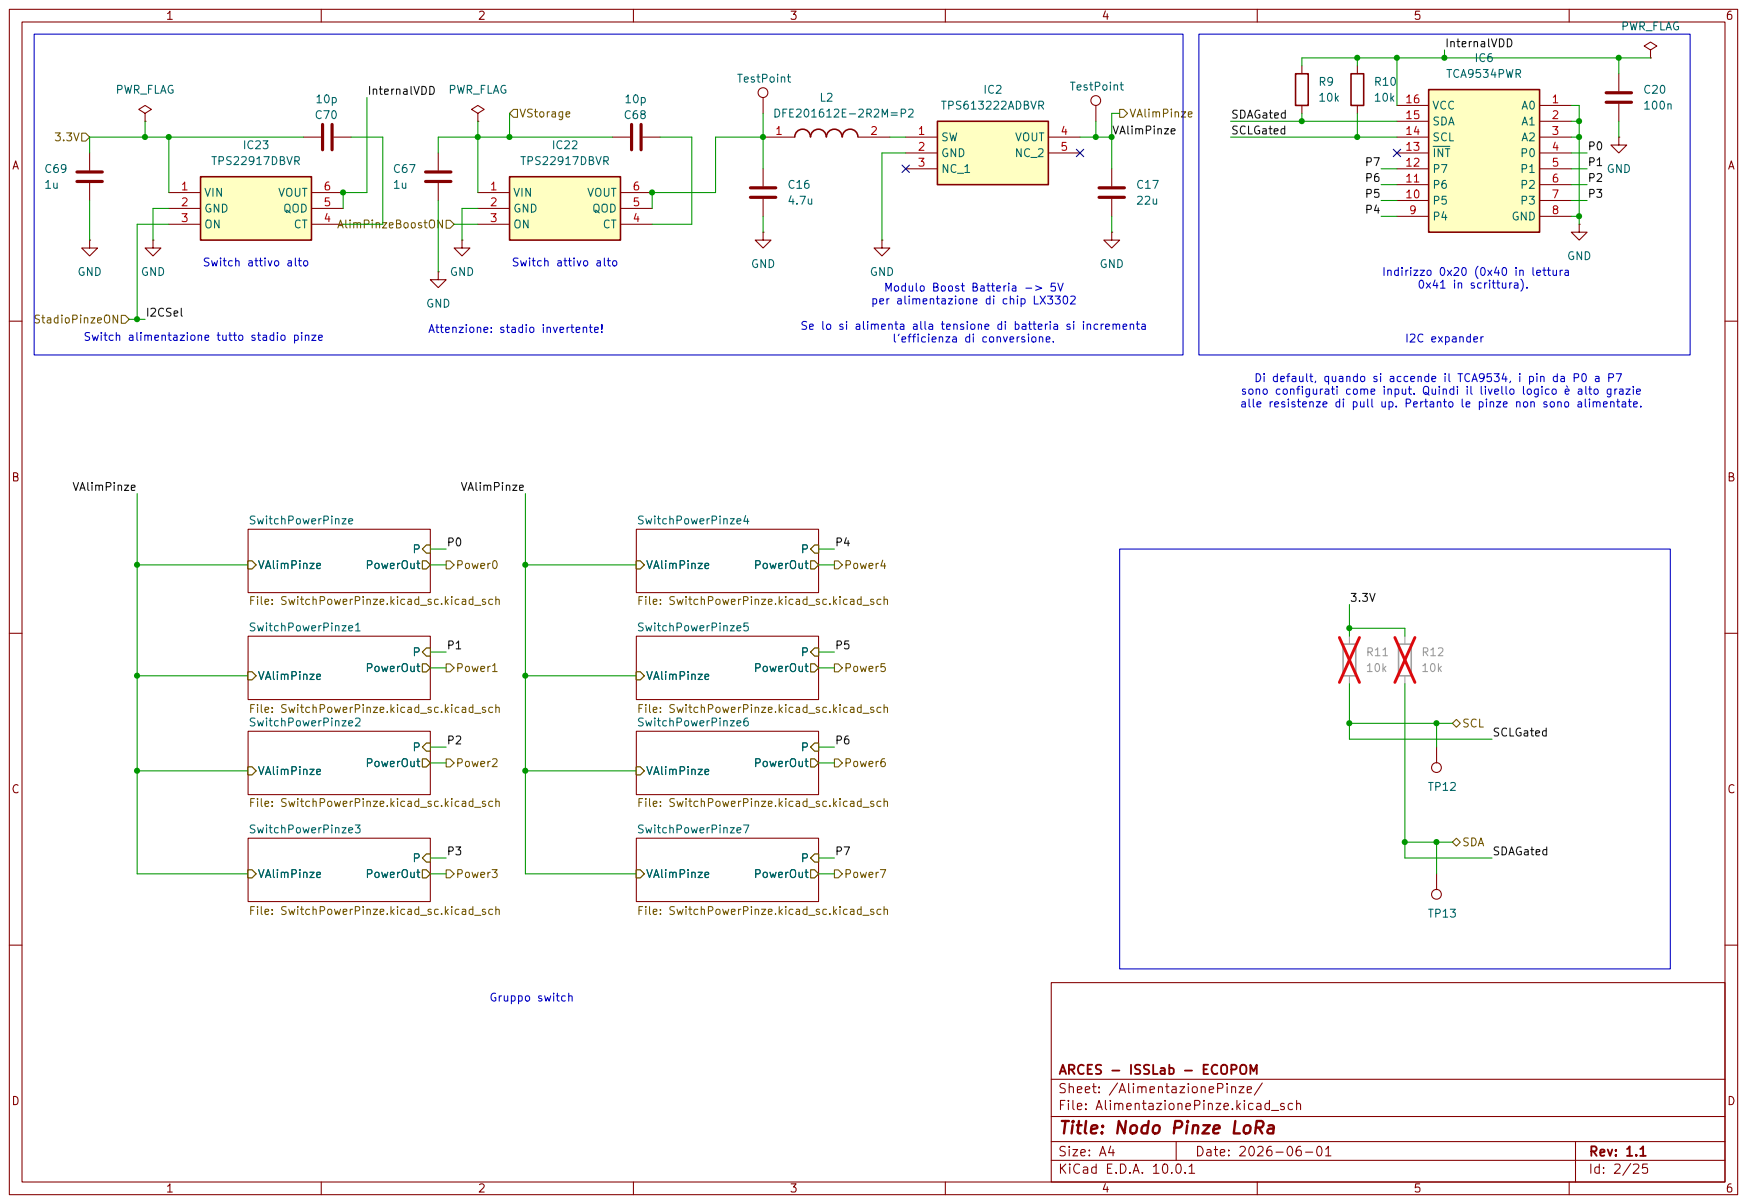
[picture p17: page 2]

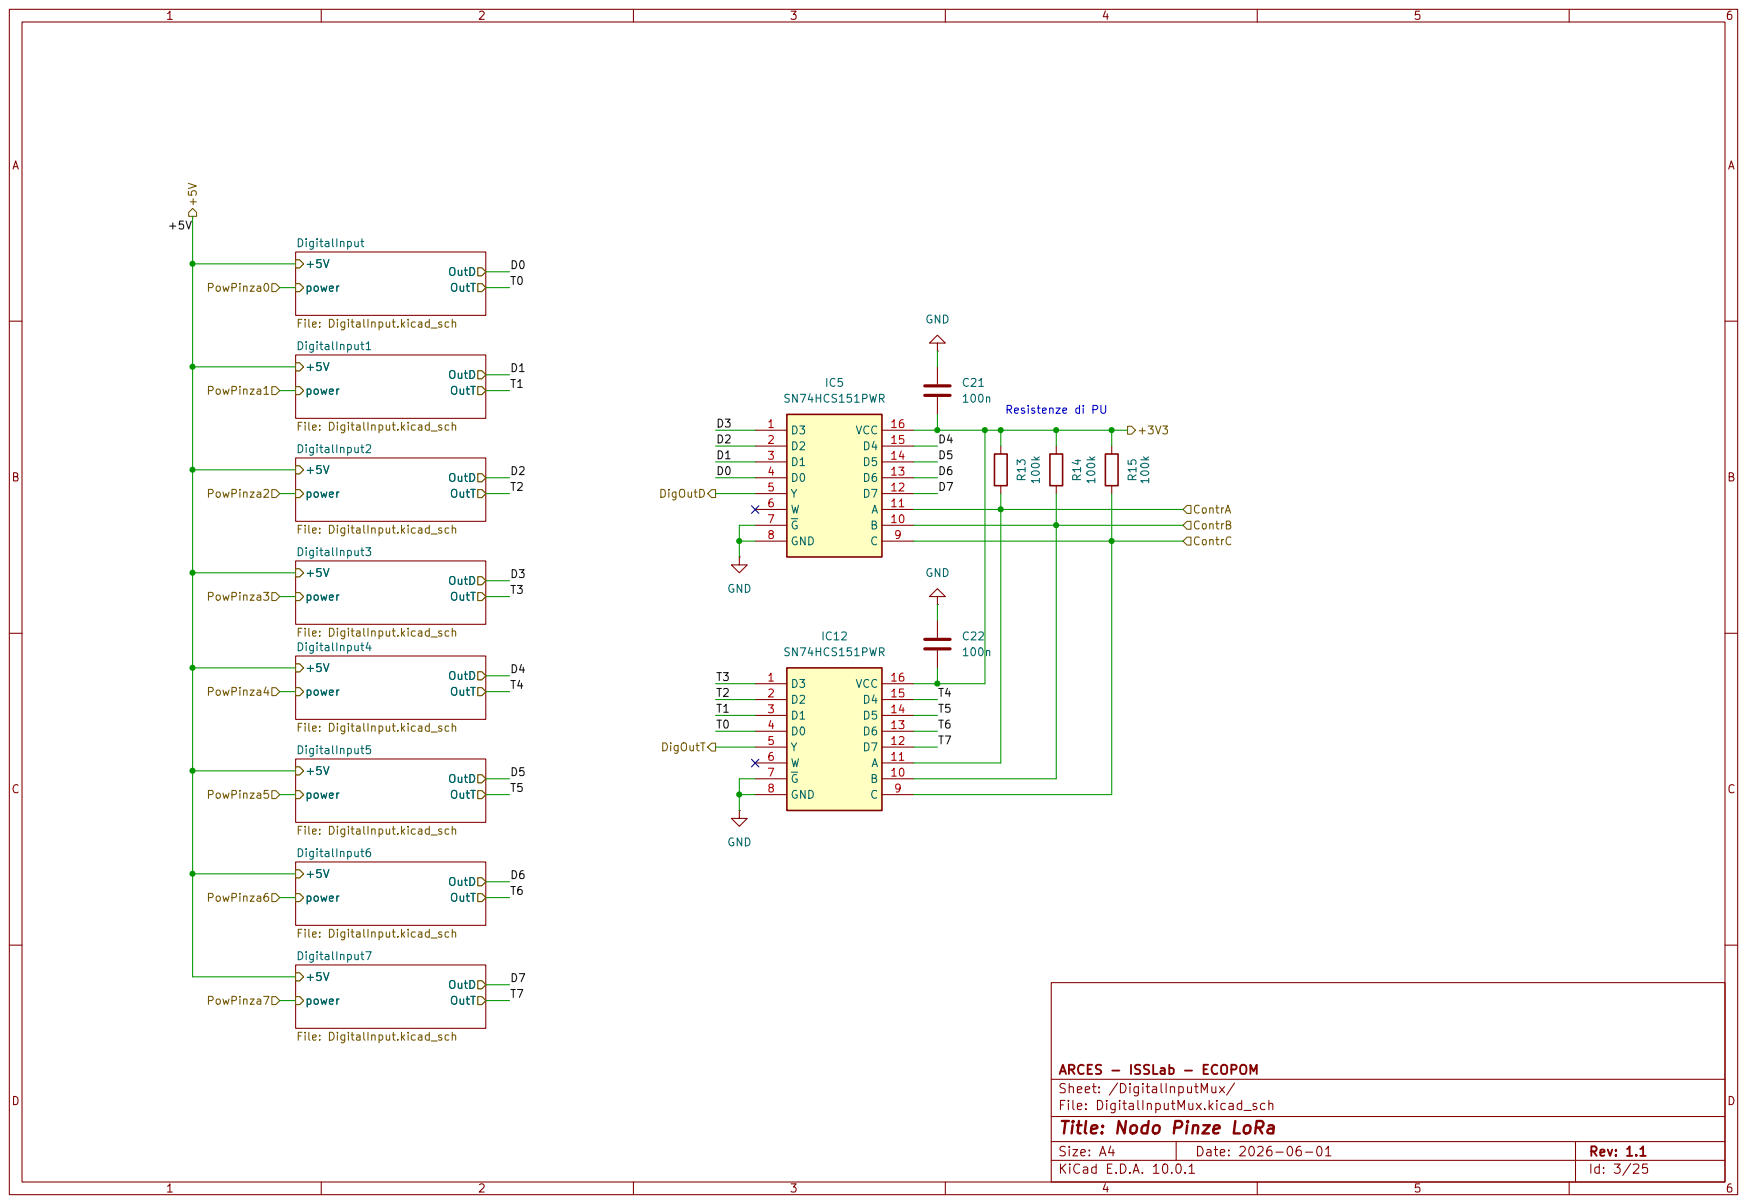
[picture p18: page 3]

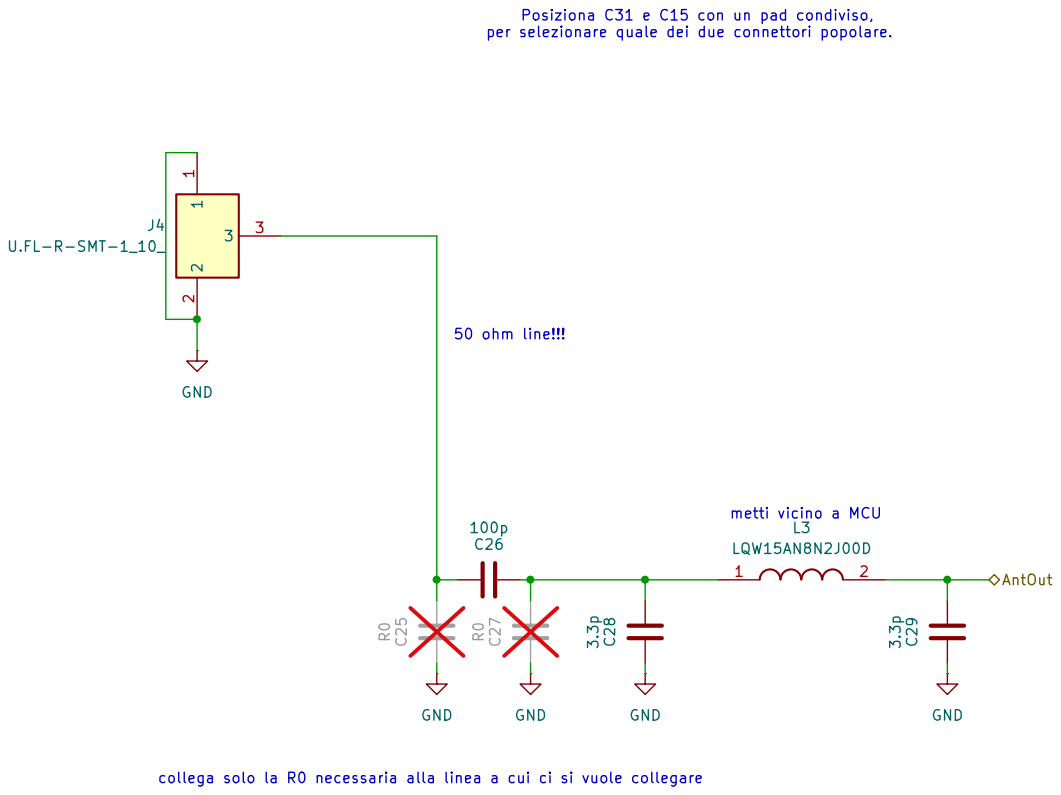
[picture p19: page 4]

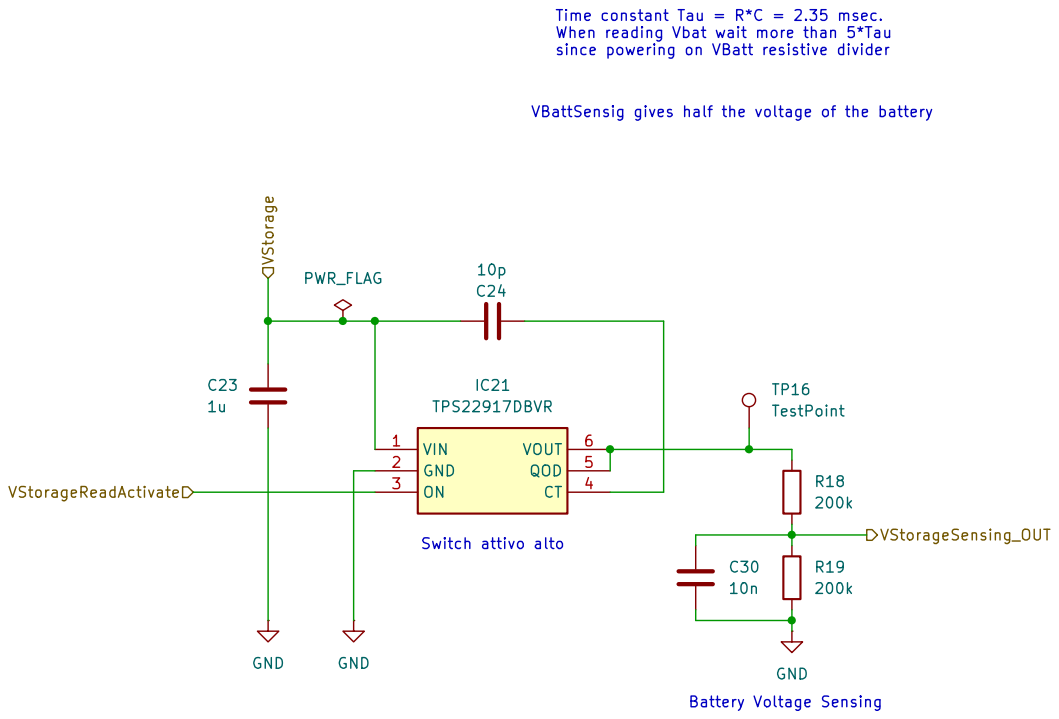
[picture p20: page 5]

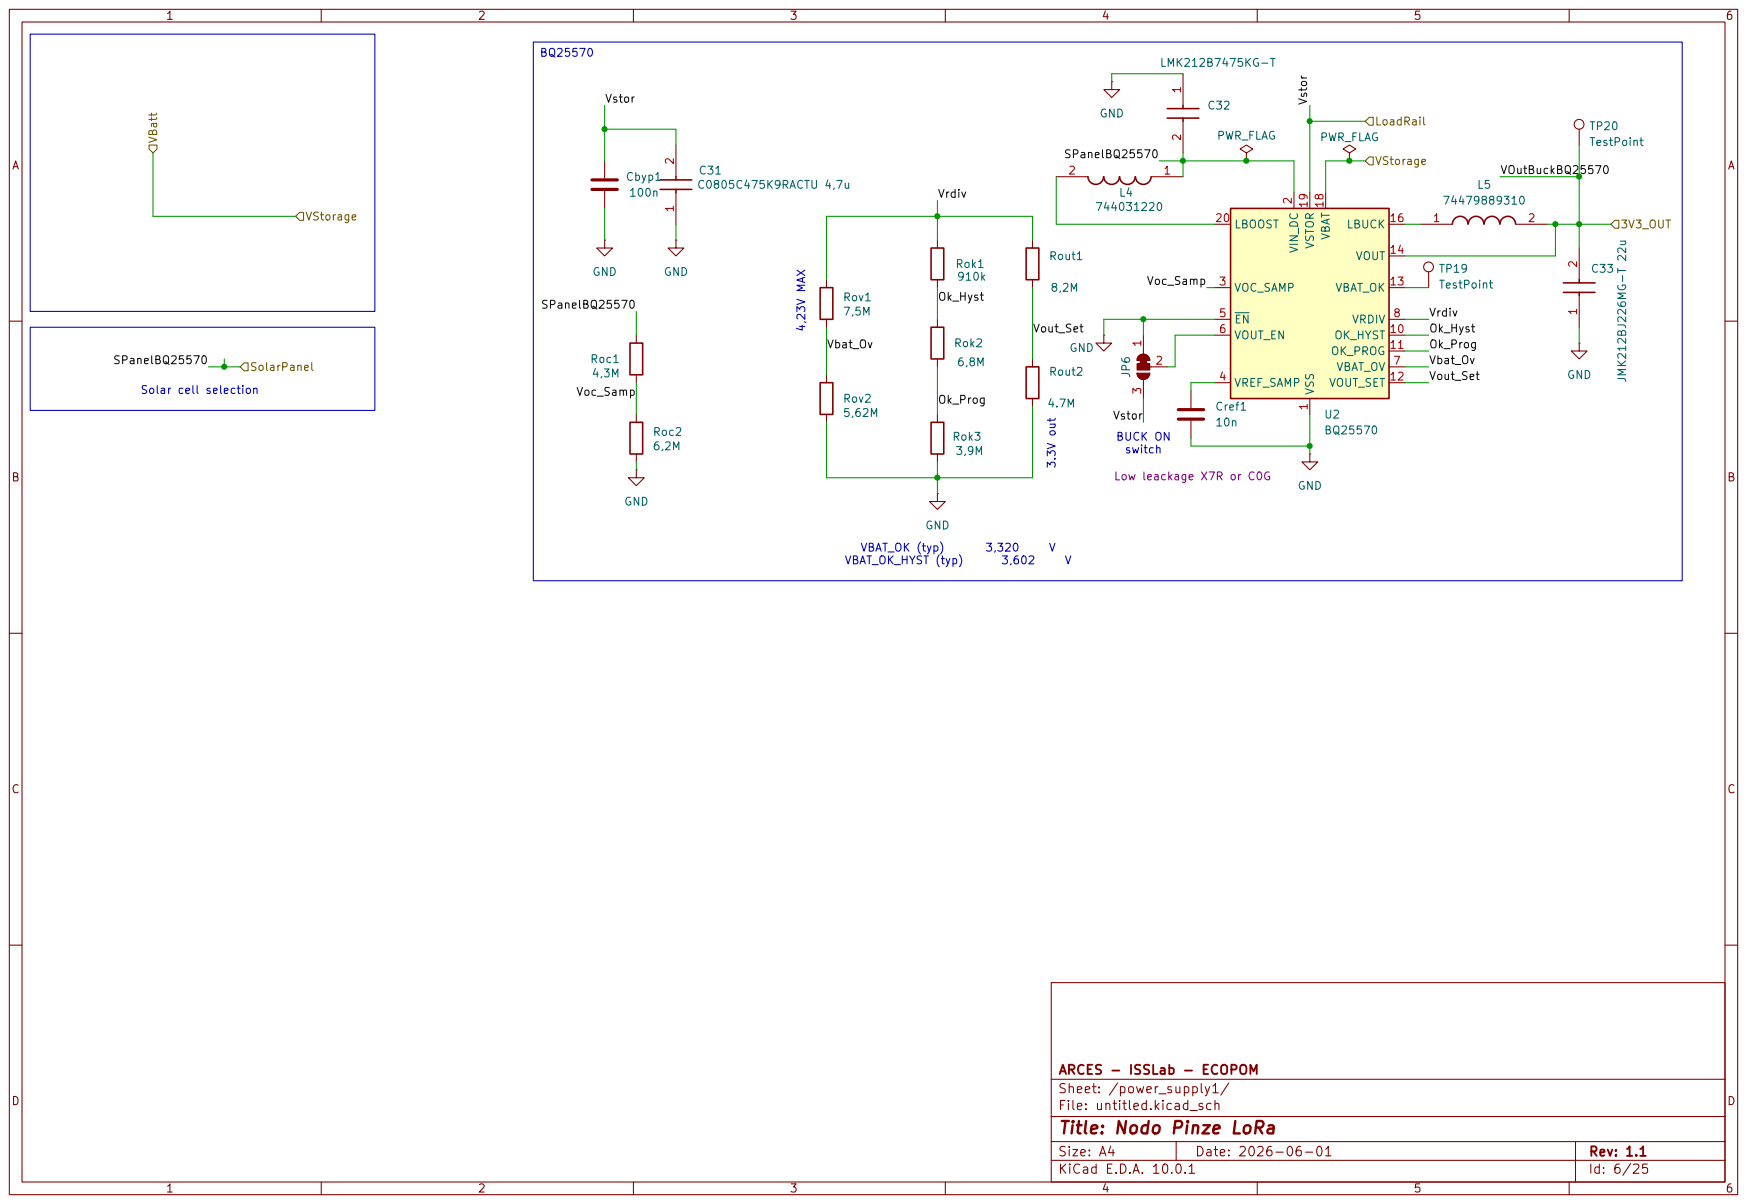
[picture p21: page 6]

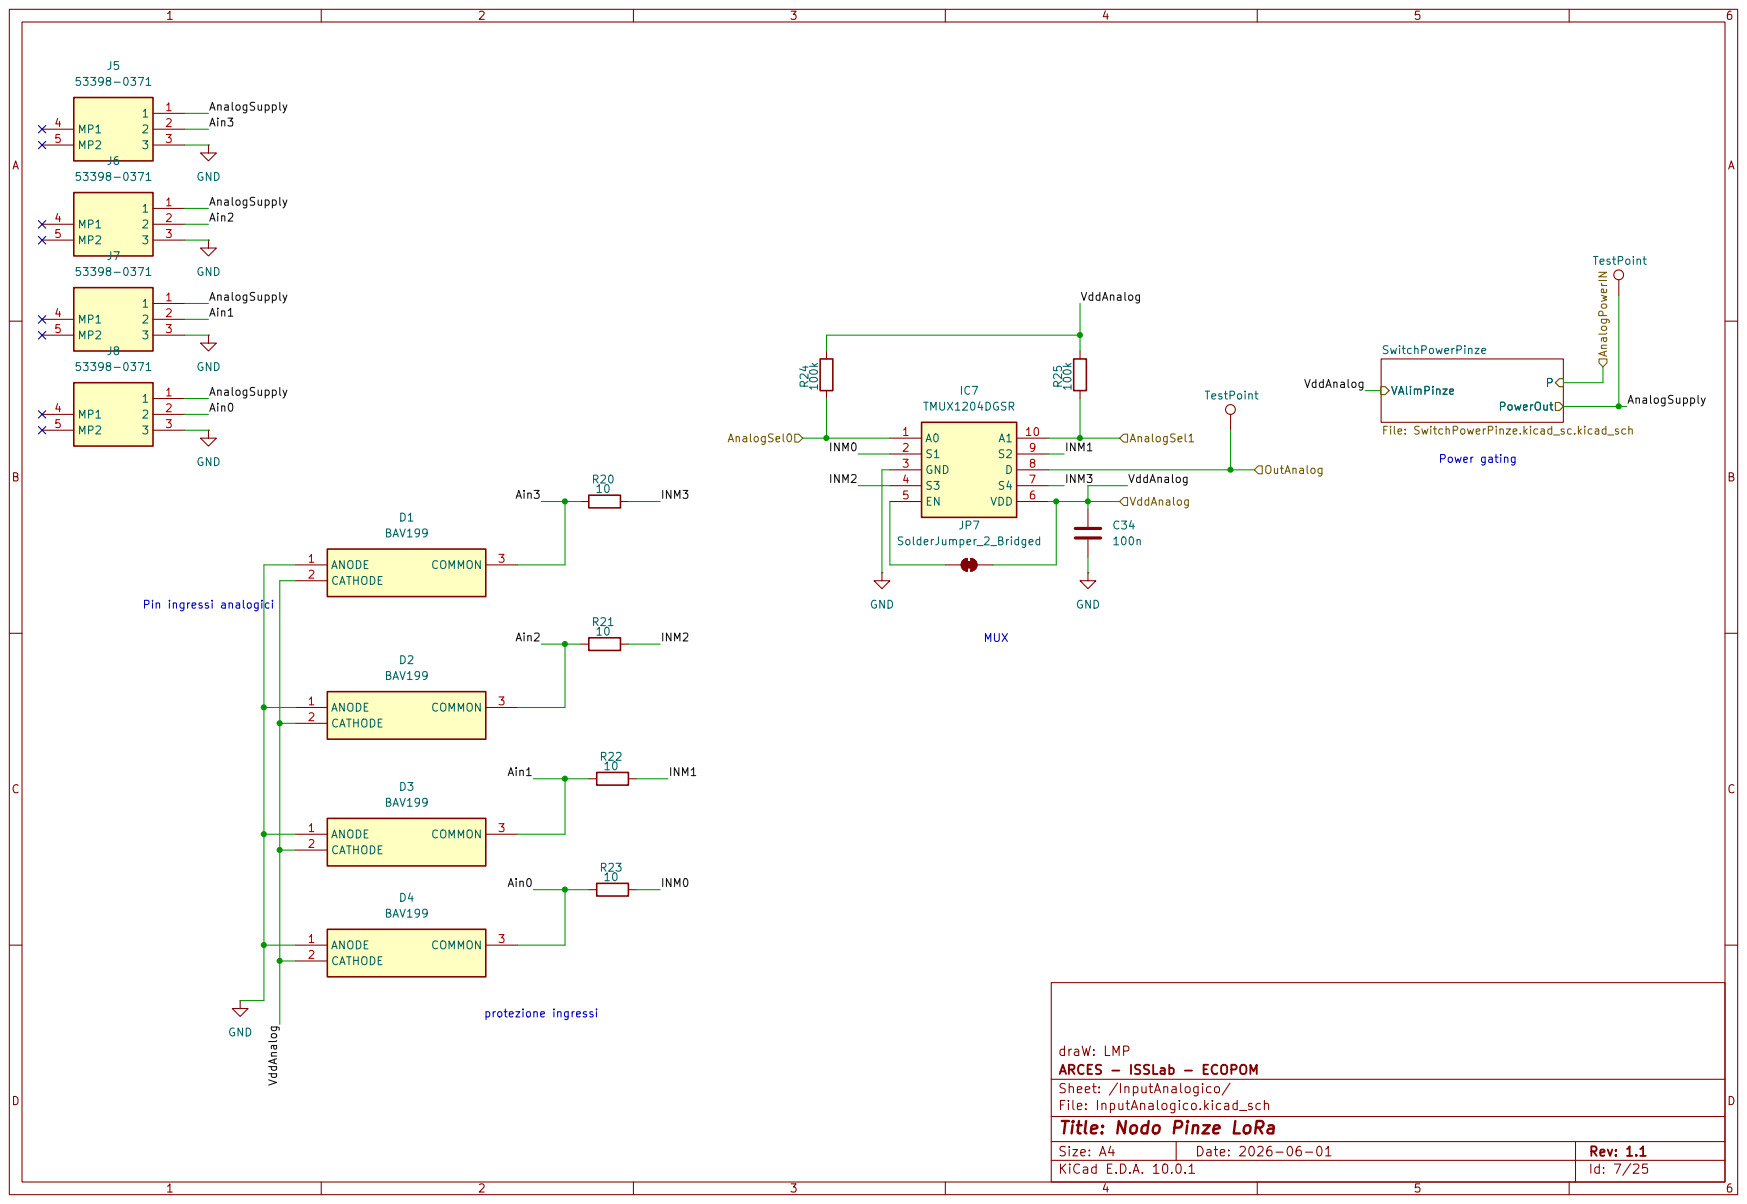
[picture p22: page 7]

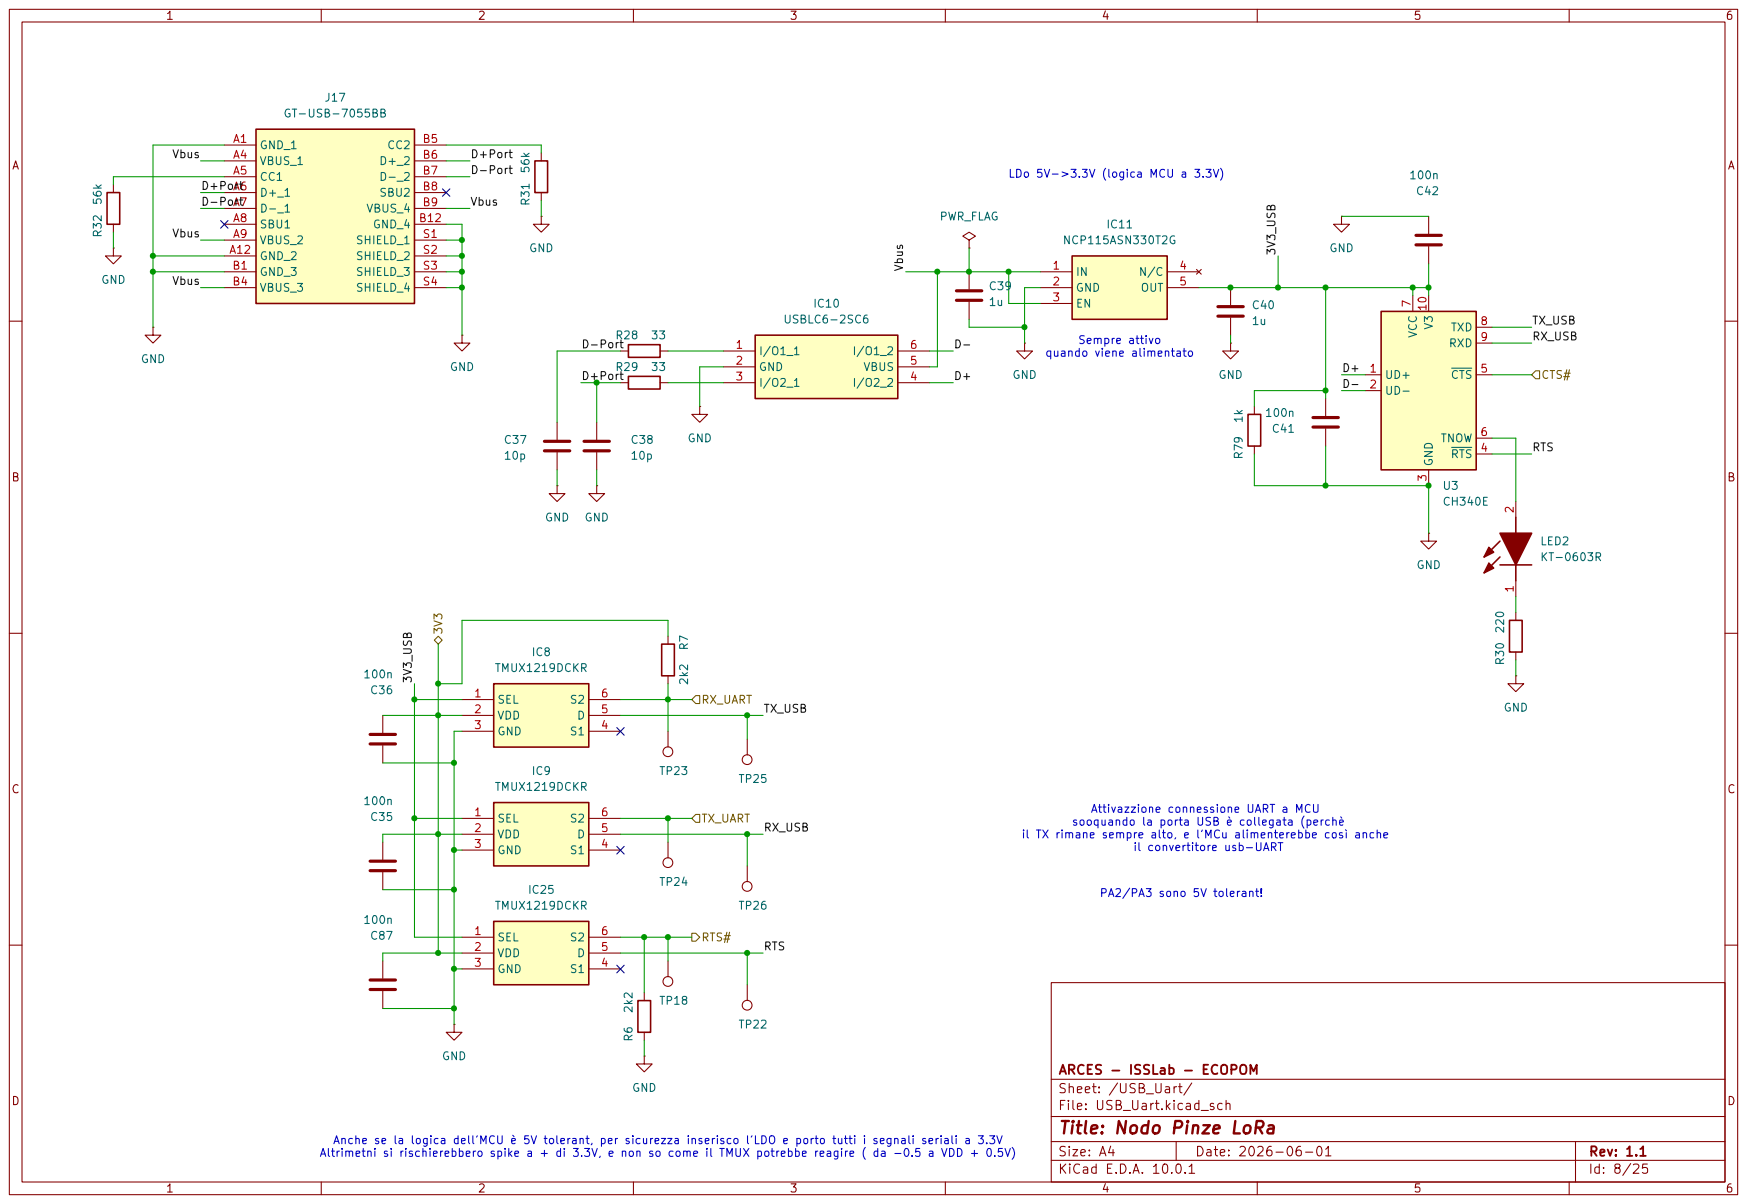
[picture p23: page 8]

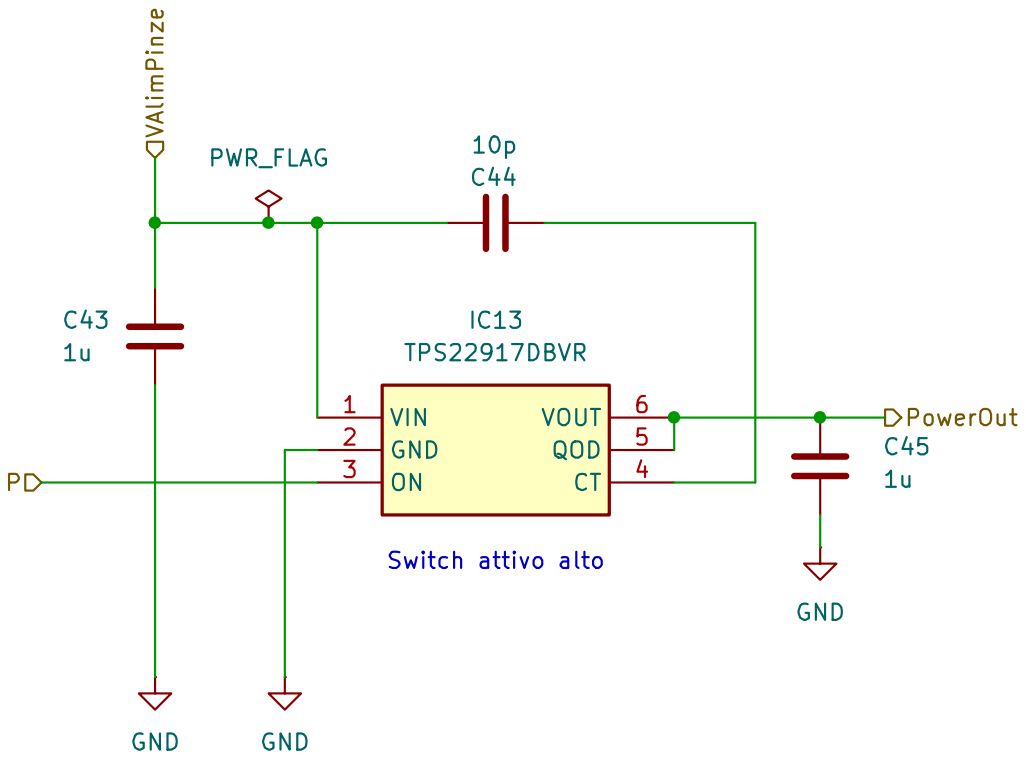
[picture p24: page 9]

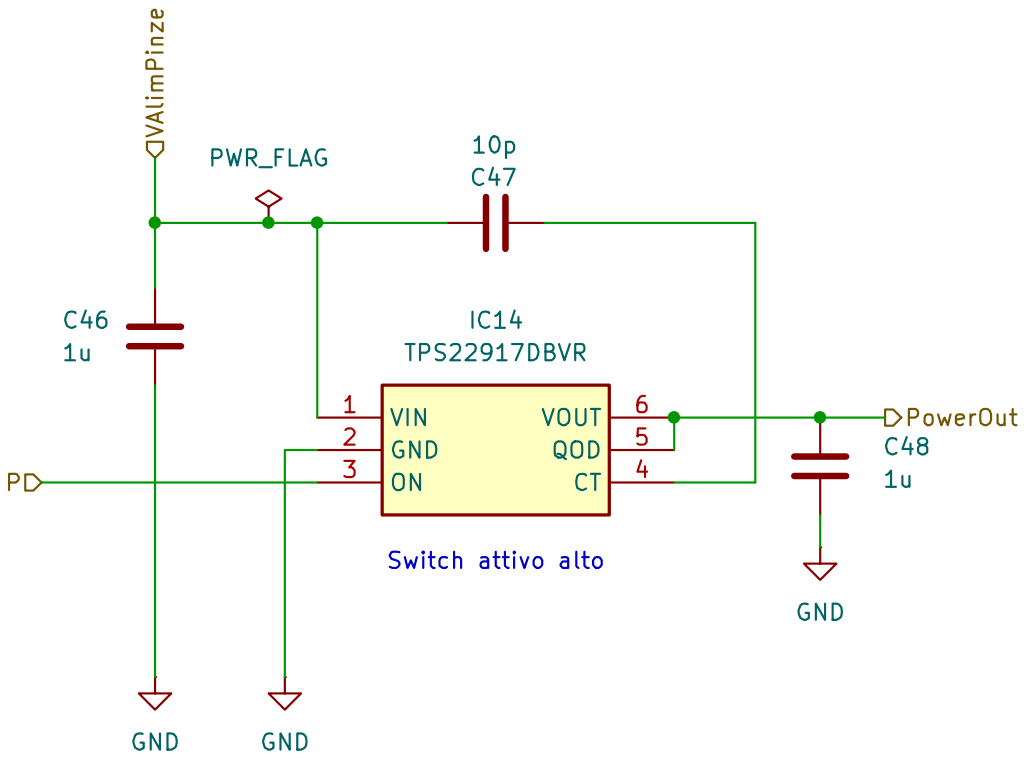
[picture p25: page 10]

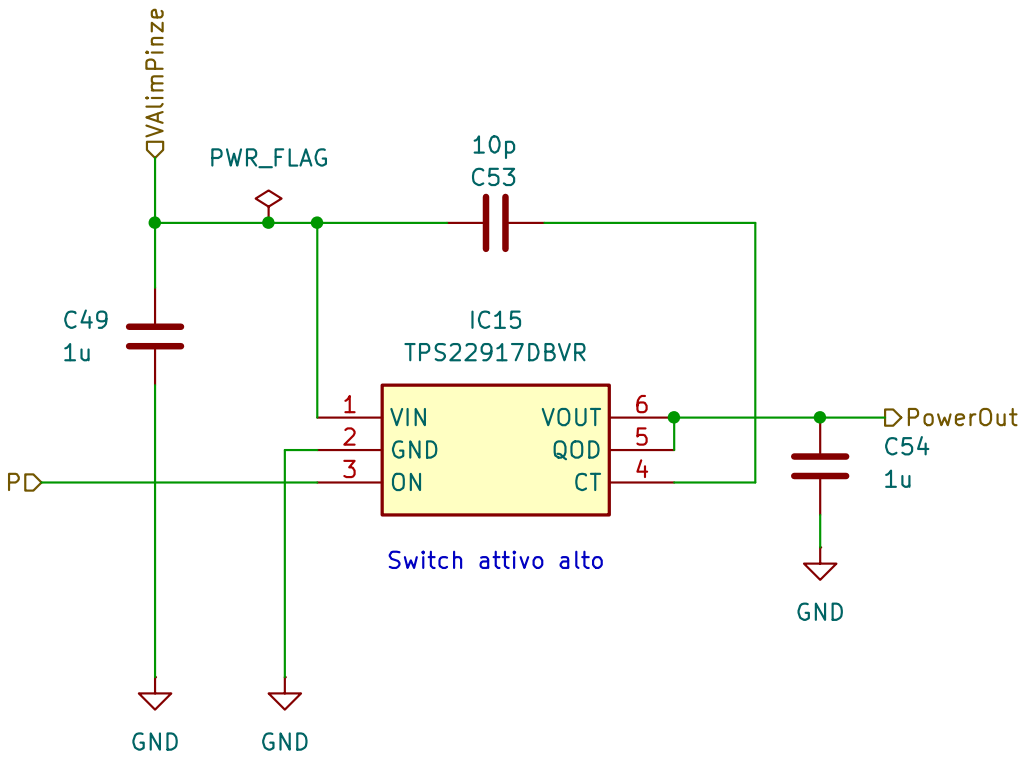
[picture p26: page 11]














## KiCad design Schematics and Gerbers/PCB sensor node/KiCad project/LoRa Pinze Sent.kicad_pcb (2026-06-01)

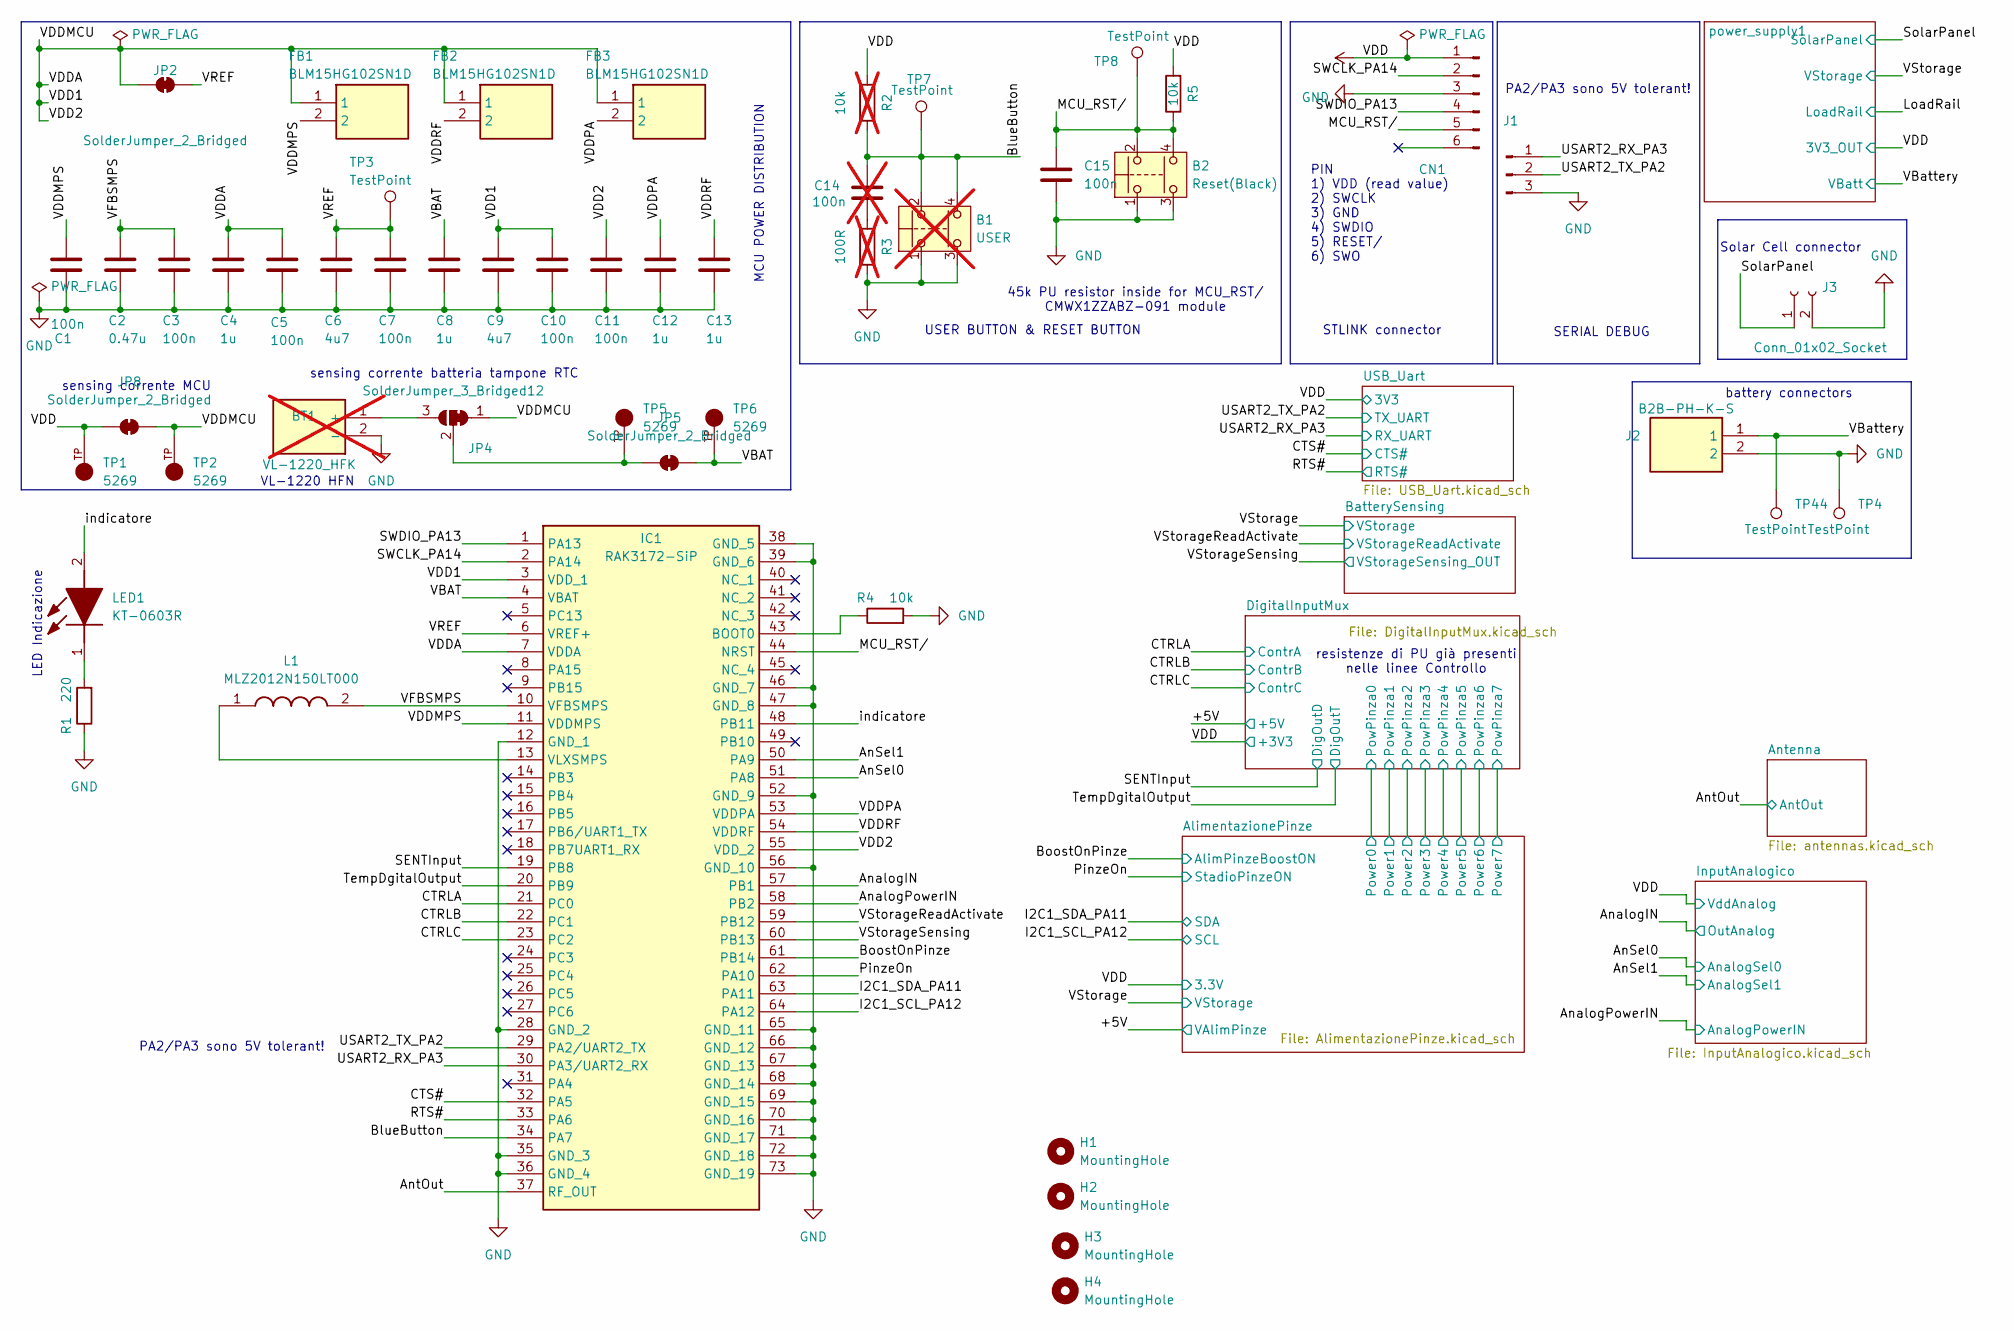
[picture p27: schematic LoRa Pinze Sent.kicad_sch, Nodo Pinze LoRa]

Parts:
B1: USER; TS046655BK160SMT; LCSC C5340119; not fitted
B2: Reset(Black); TS046655BK160SMT; LCSC C5340119
BT1: VL-1220_HFK; VL1220HFK; Manufacturer_Part_Number VL-1220/HFK; not fitted
C1, C3, C5, C7, C10, C11, C15: 100n; C_0402_1005Metric_Pad0.74x0.62mm_HandSolder; LCSC C1525
C2: 0.47u; C_0603_1608Metric_Pad1.08x0.95mm_HandSolder; LCSC C1623
C4, C8, C12, C13: 1u; C_0402_1005Metric_Pad0.74x0.62mm_HandSolder; LCSC C52923
C6, C9: 4u7; C_0402_1005Metric_Pad0.74x0.62mm_HandSolder; LCSC C23733
C14: 100n; C_0402_1005Metric_Pad0.74x0.62mm_HandSolder; LCSC C1525; not fitted
CN1: Conn_01x06_Pin; PinSocket_1x06_P2.54mm_Vertical
FB1, FB2, FB3: BLM15HG102SN1D; NFZ15SG152SN10B; Manufacturer_Part_Number BLM15HG102SN1D; Mouser Part Number 81-BLM15HG102SN1D
H1, H2, H3, H4: MountingHole; MountingHole_3.2mm_M3
IC1: RAK3172-SiP; RAK3172SiP; Manufacturer_Part_Number RAK3172-SiP; LCSC C19818882
J1: Conn_01x03_Pin; PinHeader_1x03_P2.54mm_Vertical
J2: B2B-PH-K-S; SHDR2W50P0X200_1X2_590X450X600P; Manufacturer_Part_Number B2B-PH-K-S
J3: Conn_01x02_Socket; Samtec_HPM-02-05-x-S_Straight_1x02_Pitch5.08mm
JP2, JP5, JP8: SolderJumper_2_Bridged; SolderJumper-2_P1.3mm_Bridged_RoundedPad1.0x1.5mm
JP4: SolderJumper_3_Bridged12; SolderJumper-3_P1.3mm_Bridged12_RoundedPad1.0x1.5mm
L1: MLZ2012N150LT000; INDC2012X105N; Manufacturer_Part_Number MLZ2012N150LT000; Mouser Part Number 810-MLZ2012N150LT000
LED1: KT-0603R; LEDC1608X70N; Manufacturer_Part_Number KT-0603R; LCSC C2286
R1: 220; R_0402_1005Metric_Pad0.72x0.64mm_HandSolder; LCSC C25091
R2: 10k; R_0402_1005Metric; LCSC C25744; not fitted
R3: 100R; R_0402_1005Metric; LCSC C25076; not fitted
R4, R5: 10k; R_0402_1005Metric; LCSC C25744
TP1, TP2, TP5, TP6: 5269; KEYSTONE_5269; PARTREV H
TP3, TP4, TP7, TP8, TP44: TestPoint; TestPoint_Pad_1.0x1.0mm

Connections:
/AnSel0: IC1.51 (PA8); also elsewhere on the board
/AnSel1: IC1.50 (PA9); also elsewhere on the board
/AnalogIN: IC1.57 (PB1); also elsewhere on the board
/AnalogPowerIN: IC1.58 (PB2); also elsewhere on the board
/AntOut: IC1.37 (RF_OUT); also elsewhere on the board
/BlueButton: B1.2, B1.4, C14.1, IC1.34 (PA7), R2.1, TP7.1 (1_1)
/BoostOnPinze: IC1.61 (PB14); also elsewhere on the board
/CTRLA: IC1.21 (PC0); also elsewhere on the board
/CTRLB: IC1.22 (PC1); also elsewhere on the board
/CTRLC: IC1.23 (PC2); also elsewhere on the board
/CTS#: IC1.32 (PA5); also elsewhere on the board
/I2C1_SCL_PA12: IC1.64 (PA12); also elsewhere on the board
/I2C1_SDA_PA11: IC1.63 (PA11); also elsewhere on the board
/MCU_RST/: B2.2, B2.4, C15.1, CN1.5, IC1.44 (NRST), R5.1, TP8.1 (1_1)
/PinzeOn: IC1.62 (PA10); also elsewhere on the board
/RTS#: IC1.33 (PA6); also elsewhere on the board
/SENTInput: IC1.19 (PB8); also elsewhere on the board
/SWCLK_PA14: CN1.2, IC1.2 (PA14)
/SWDIO_PA13: CN1.4, IC1.1 (PA13)
/SolarPanel: J3.1; also elsewhere on the board
/TempDgitalOutput: IC1.20 (PB9); also elsewhere on the board
/USART2_RX_PA3: IC1.30 (PA3/UART2_RX), J1.1; also elsewhere on the board
/USART2_TX_PA2: IC1.29 (PA2/UART2_TX), J1.2; also elsewhere on the board
/VBAT: C8.1, IC1.4 (VBAT), JP5.1 (A), TP6.TP
/VBattery: J2.1, TP44.1 (1_1); also elsewhere on the board
/VDD1: C4.1, C5.1, C9.1, C10.1, C11.1, FB1.1, FB2.1, FB3.1, IC1.3 (VDD_1), IC1.7 (VDDA), IC1.55 (VDD_2), JP2.1 (A), JP4.1 (A), JP8.1 (A), TP2.TP
/VDDMPS: C1.1, FB1.2, IC1.11 (VDDMPS)
/VDDPA: C12.1, FB3.2, IC1.53 (VDDPA)
/VDDRF: C13.1, FB2.2, IC1.54 (VDDRF)
/VFBSMPS: C2.1, C3.1, IC1.10 (VFBSMPS), L1.2
/VREF: C6.1, C7.1, IC1.6 (VREF+), JP2.2 (B), TP3.1 (1_1)
/VStorageReadActivate: IC1.59 (PB12); also elsewhere on the board
/VStorageSensing: IC1.60 (PB13); also elsewhere on the board
/indicatore: IC1.48 (PB11), LED1.2 (A)
GND: B1.1, B1.3, B2.1, B2.3, BT1.2 (-), C1.2, C2.2, C3.2, C4.2, C5.2, C6.2, C7.2, C8.2, C9.2, C10.2, C11.2, C12.2, C13.2, C15.2, CN1.3, IC1.12 (GND_1), IC1.28 (GND_2), IC1.35 (GND_3), IC1.36 (GND_4), IC1.38 (GND_5), IC1.39 (GND_6), IC1.46 (GND_7), IC1.47 (GND_8), IC1.52 (GND_9), IC1.56 (GND_10), IC1.65 (GND_11), IC1.66 (GND_12), IC1.67 (GND_13), IC1.68 (GND_14), IC1.69 (GND_15), IC1.70 (GND_16), IC1.71 (GND_17), IC1.72 (GND_18), IC1.73 (GND_19), J1.3, J2.2, J3.2, R1.1, R3.1, R4.2, TP4.1 (1_1); also elsewhere on the board
unnamed: BT1.1 (+), JP4.3 (B)
unnamed: C14.2, R3.2
unnamed: IC1.43 (BOOT0), R4.1
unnamed: IC1.13 (VLXSMPS), L1.1
unnamed: JP4.2 (C), JP5.2 (B), TP5.TP
unnamed: LED1.1 (K), R1.2
VDD_MCU_LRA: CN1.1, JP8.2 (B), R2.2, R5.2, TP1.TP; also elsewhere on the board

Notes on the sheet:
Solar Cell connector
PA2/PA3 sono 5V tolerant!
45k PU resistor inside for MCU_RST/ CMWX1ZZABZ-091 module
sensing corrente batteria tampone RTC
SERIAL DEBUG
battery connectors
resistenze di PU già presenti nelle linee Controllo
STLINK connector
PIN 1) VDD (read value) 2) SWCLK 3) GND 4) SWDIO 5) RESET/ 6) SWO
VL-1220 HFN
sensing corrente MCU
MCU POWER DISTRIBUTION
LED Indicazione
USER BUTTON & RESET BUTTON

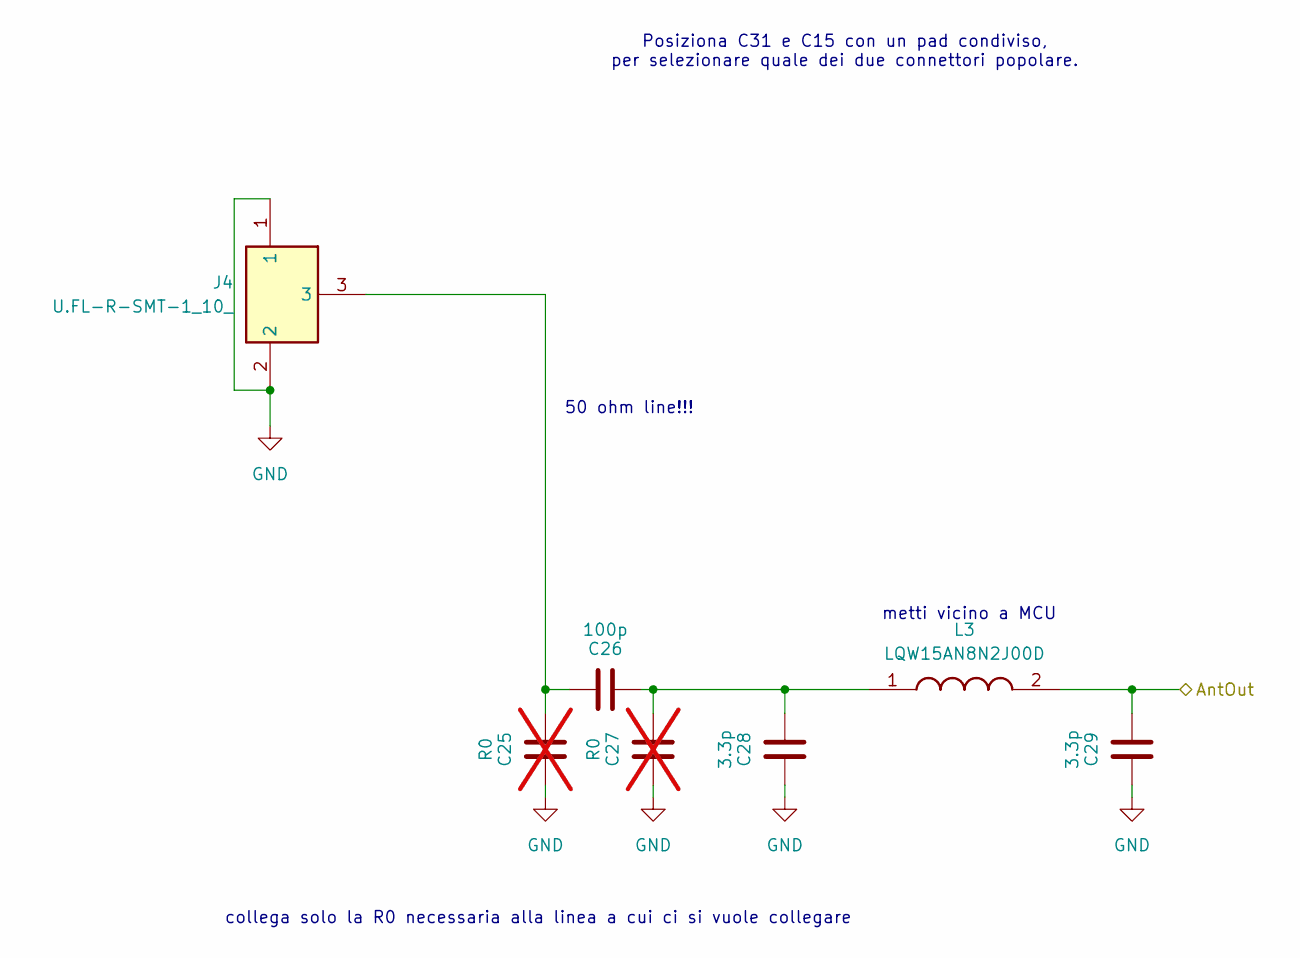
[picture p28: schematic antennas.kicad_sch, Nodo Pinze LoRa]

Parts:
C25, C27: R0; C_0402_1005Metric_Pad0.74x0.62mm_HandSolder; not fitted
C26: 100p; C_0402_1005Metric_Pad0.74x0.62mm_HandSolder; LCSC C1546
C28, C29: 3.3p; C_0402_1005Metric_Pad0.74x0.62mm_HandSolder; LCSC C1565
J4: U.FL-R-SMT-1_10_; Manufacturer_Part_Number U.FL-R-SMT-1(10); Mouser Part Number 798-U.FL-R-SMT-110
L3: LQW15AN8N2J00D; LQW15CNR20J00B; Manufacturer_Part_Number LQW15AN8N2J00D; Mouser Part Number 81-LQW15AN8N2J00D

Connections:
/AntOut: C29.2, L3.2; also elsewhere on the board
GND: C25.1, C27.1, C28.1, C29.1, J4.1, J4.2; also elsewhere on the board
unnamed: C25.2, C26.1, J4.3
unnamed: C26.2, C27.2, C28.2, L3.1

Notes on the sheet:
metti vicino a MCU
50 ohm line!!!
collega solo la R0 necessaria alla linea a cui ci si vuole collegare
Posiziona C31 e C15 con un pad condiviso, per selezionare quale dei due connettori popolare.

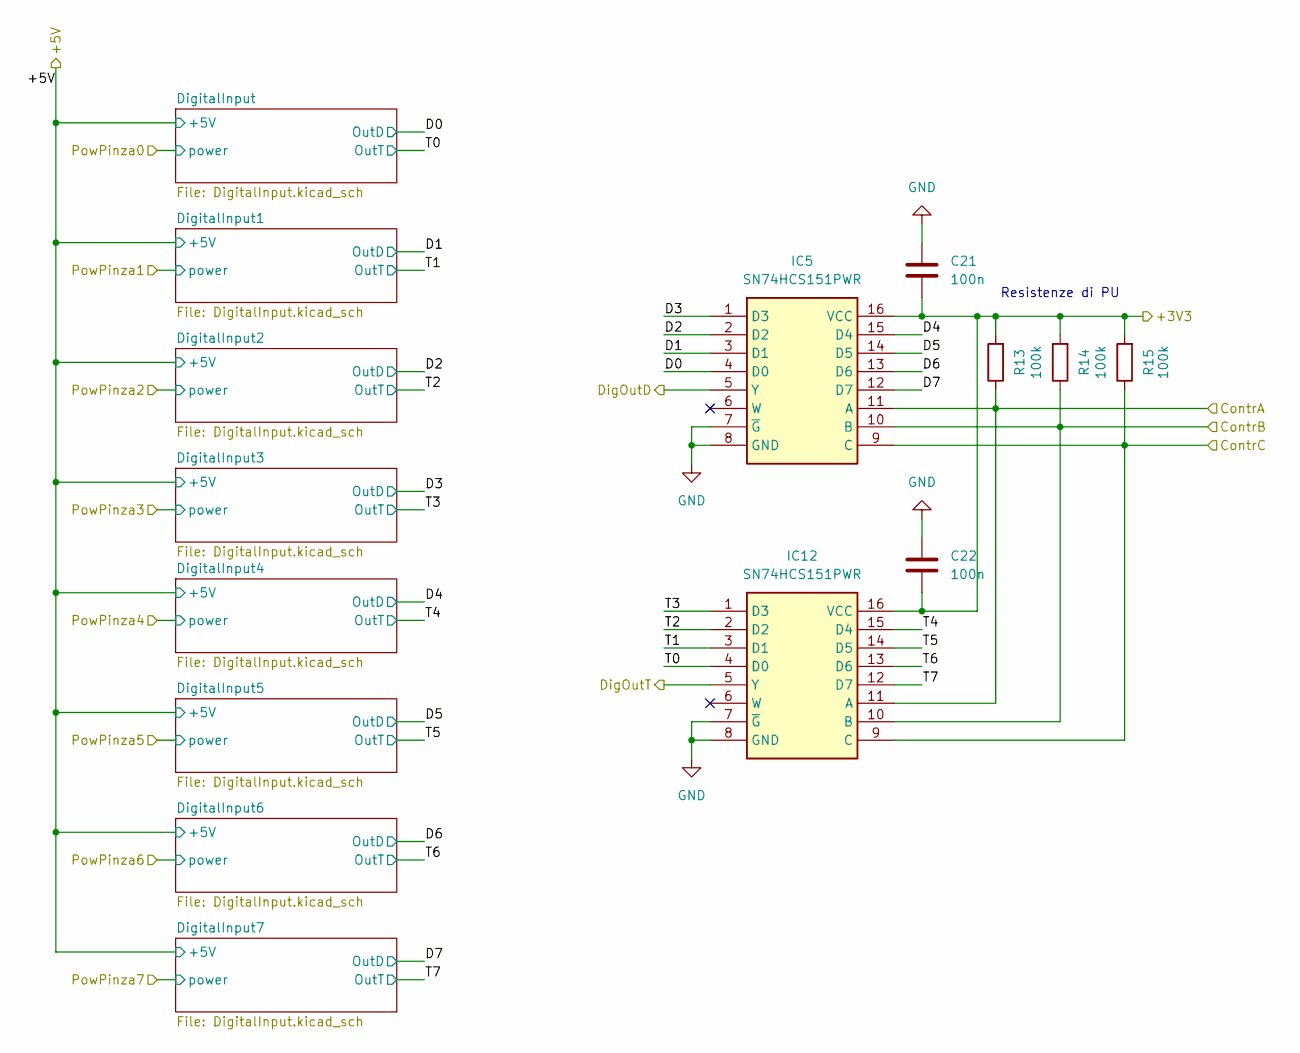
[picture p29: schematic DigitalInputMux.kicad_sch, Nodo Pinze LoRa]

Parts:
C21, C22: 100n; C_0402_1005Metric_Pad0.74x0.62mm_HandSolder; LCSC C1525
IC5, IC12: SN74HCS151PWR; SOP65P640X120-16N; Manufacturer_Part_Number SN74HCS151PWR; Mouser Part Number 595-SN74HCS151PWR
R13, R14, R15: 100k; R_0402_1005Metric; LCSC C25741

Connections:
/CTRLA: IC5.11 (A), IC12.11 (A), R13.1; also elsewhere on the board
/CTRLB: IC5.10 (B), IC12.10 (B), R14.1; also elsewhere on the board
/CTRLC: IC5.9 (C), IC12.9 (C), R15.1; also elsewhere on the board
/DigitalInputMux/D0: IC5.4 (D0); also elsewhere on the board
/DigitalInputMux/D1: IC5.3 (D1); also elsewhere on the board
/DigitalInputMux/D2: IC5.2 (D2); also elsewhere on the board
/DigitalInputMux/D3: IC5.1 (D3); also elsewhere on the board
/DigitalInputMux/D4: IC5.15 (D4); also elsewhere on the board
/DigitalInputMux/D5: IC5.14 (D5); also elsewhere on the board
/DigitalInputMux/D6: IC5.13 (D6); also elsewhere on the board
/DigitalInputMux/D7: IC5.12 (D7); also elsewhere on the board
/DigitalInputMux/T0: IC12.4 (D0); also elsewhere on the board
/DigitalInputMux/T1: IC12.3 (D1); also elsewhere on the board
/DigitalInputMux/T2: IC12.2 (D2); also elsewhere on the board
/DigitalInputMux/T3: IC12.1 (D3); also elsewhere on the board
/DigitalInputMux/T4: IC12.15 (D4); also elsewhere on the board
/DigitalInputMux/T5: IC12.14 (D5); also elsewhere on the board
/DigitalInputMux/T6: IC12.13 (D6); also elsewhere on the board
/DigitalInputMux/T7: IC12.12 (D7); also elsewhere on the board
/SENTInput: IC5.5 (Y); also elsewhere on the board
/TempDgitalOutput: IC12.5 (Y); also elsewhere on the board
GND: C21.1, C22.1, IC5.7 (~G), IC5.8 (GND), IC12.7 (~G), IC12.8 (GND); also elsewhere on the board
VDD_MCU_LRA: C21.2, C22.2, IC5.16 (VCC), IC12.16 (VCC), R13.2, R14.2, R15.2; also elsewhere on the board

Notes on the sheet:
Resistenze di PU

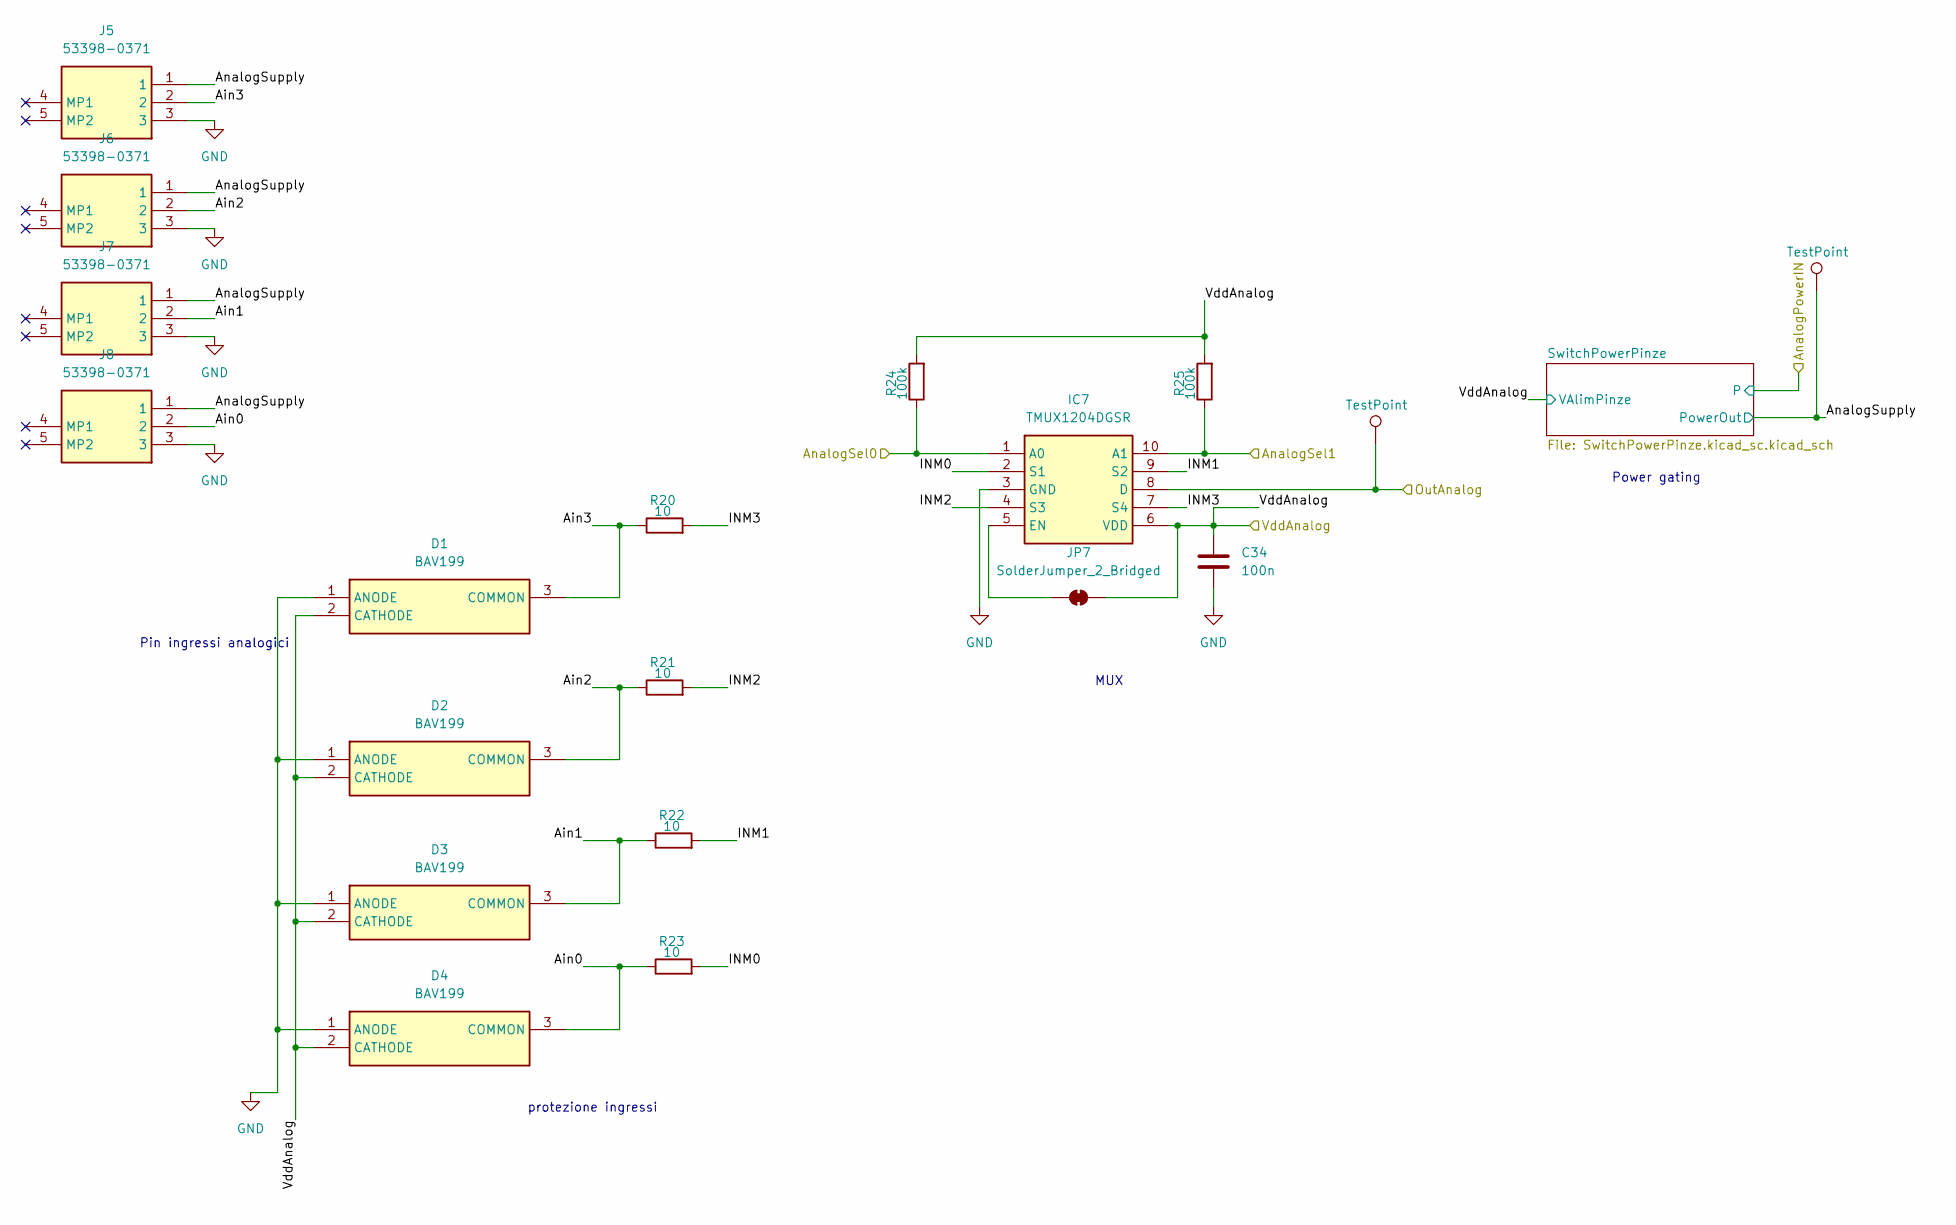
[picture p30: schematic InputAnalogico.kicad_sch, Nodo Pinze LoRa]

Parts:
C34: 100n; C_0402_1005Metric_Pad0.74x0.62mm_HandSolder; LCSC C1525
D1, D2, D3, D4: BAV199; SOT95P230X100-3N; Manufacturer_Part_Number BAV199; Mouser Part Number N/A
IC7: TMUX1204DGSR; SOP50P490X110-10N; Manufacturer_Part_Number TMUX1204DGSR; Mouser Part Number 595-TMUX1204DGSR
J5, J6, J7, J8: 53398-0371; 533980371; Manufacturer_Part_Number 53398-0371; Mouser Part Number 538-53398-0371
JP7: SolderJumper_2_Bridged; SolderJumper-2_P1.3mm_Bridged_RoundedPad1.0x1.5mm
R20, R21, R22, R23: 10; R_0402_1005Metric; LCSC C25077
R24, R25: 100k; R_0402_1005Metric; LCSC C25741
TP17, TP21: TestPoint; TestPoint_Pad_1.0x1.0mm

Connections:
/AnSel0: IC7.1 (A0), R24.1; also elsewhere on the board
/AnSel1: IC7.10 (A1), R25.1; also elsewhere on the board
/AnalogIN: IC7.8 (D), TP21.1 (1_1); also elsewhere on the board
/InputAnalogico/Ain0: D4.3 (COMMON), J8.2, R23.1
/InputAnalogico/Ain1: D3.3 (COMMON), J7.2, R22.1
/InputAnalogico/Ain2: D2.3 (COMMON), J6.2, R21.1
/InputAnalogico/Ain3: D1.3 (COMMON), J5.2, R20.1
/InputAnalogico/AnalogSupply: J5.1, J6.1, J7.1, J8.1, TP17.1 (1_1); also elsewhere on the board
/InputAnalogico/INM0: IC7.2 (S1), R23.2
/InputAnalogico/INM1: IC7.9 (S2), R22.2
/InputAnalogico/INM2: IC7.4 (S3), R21.2
/InputAnalogico/INM3: IC7.7 (S4), R20.2
GND: C34.2, D1.1 (ANODE), D2.1 (ANODE), D3.1 (ANODE), D4.1 (ANODE), IC7.3 (GND), J5.3, J6.3, J7.3, J8.3; also elsewhere on the board
unnamed: IC7.5 (EN), JP7.2 (B)
VDD_MCU_LRA: C34.1, D1.2 (CATHODE), D2.2 (CATHODE), D3.2 (CATHODE), D4.2 (CATHODE), IC7.6 (VDD), JP7.1 (A), R24.2, R25.2; also elsewhere on the board

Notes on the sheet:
Power gating
protezione ingressi
Pin ingressi analogici
MUX

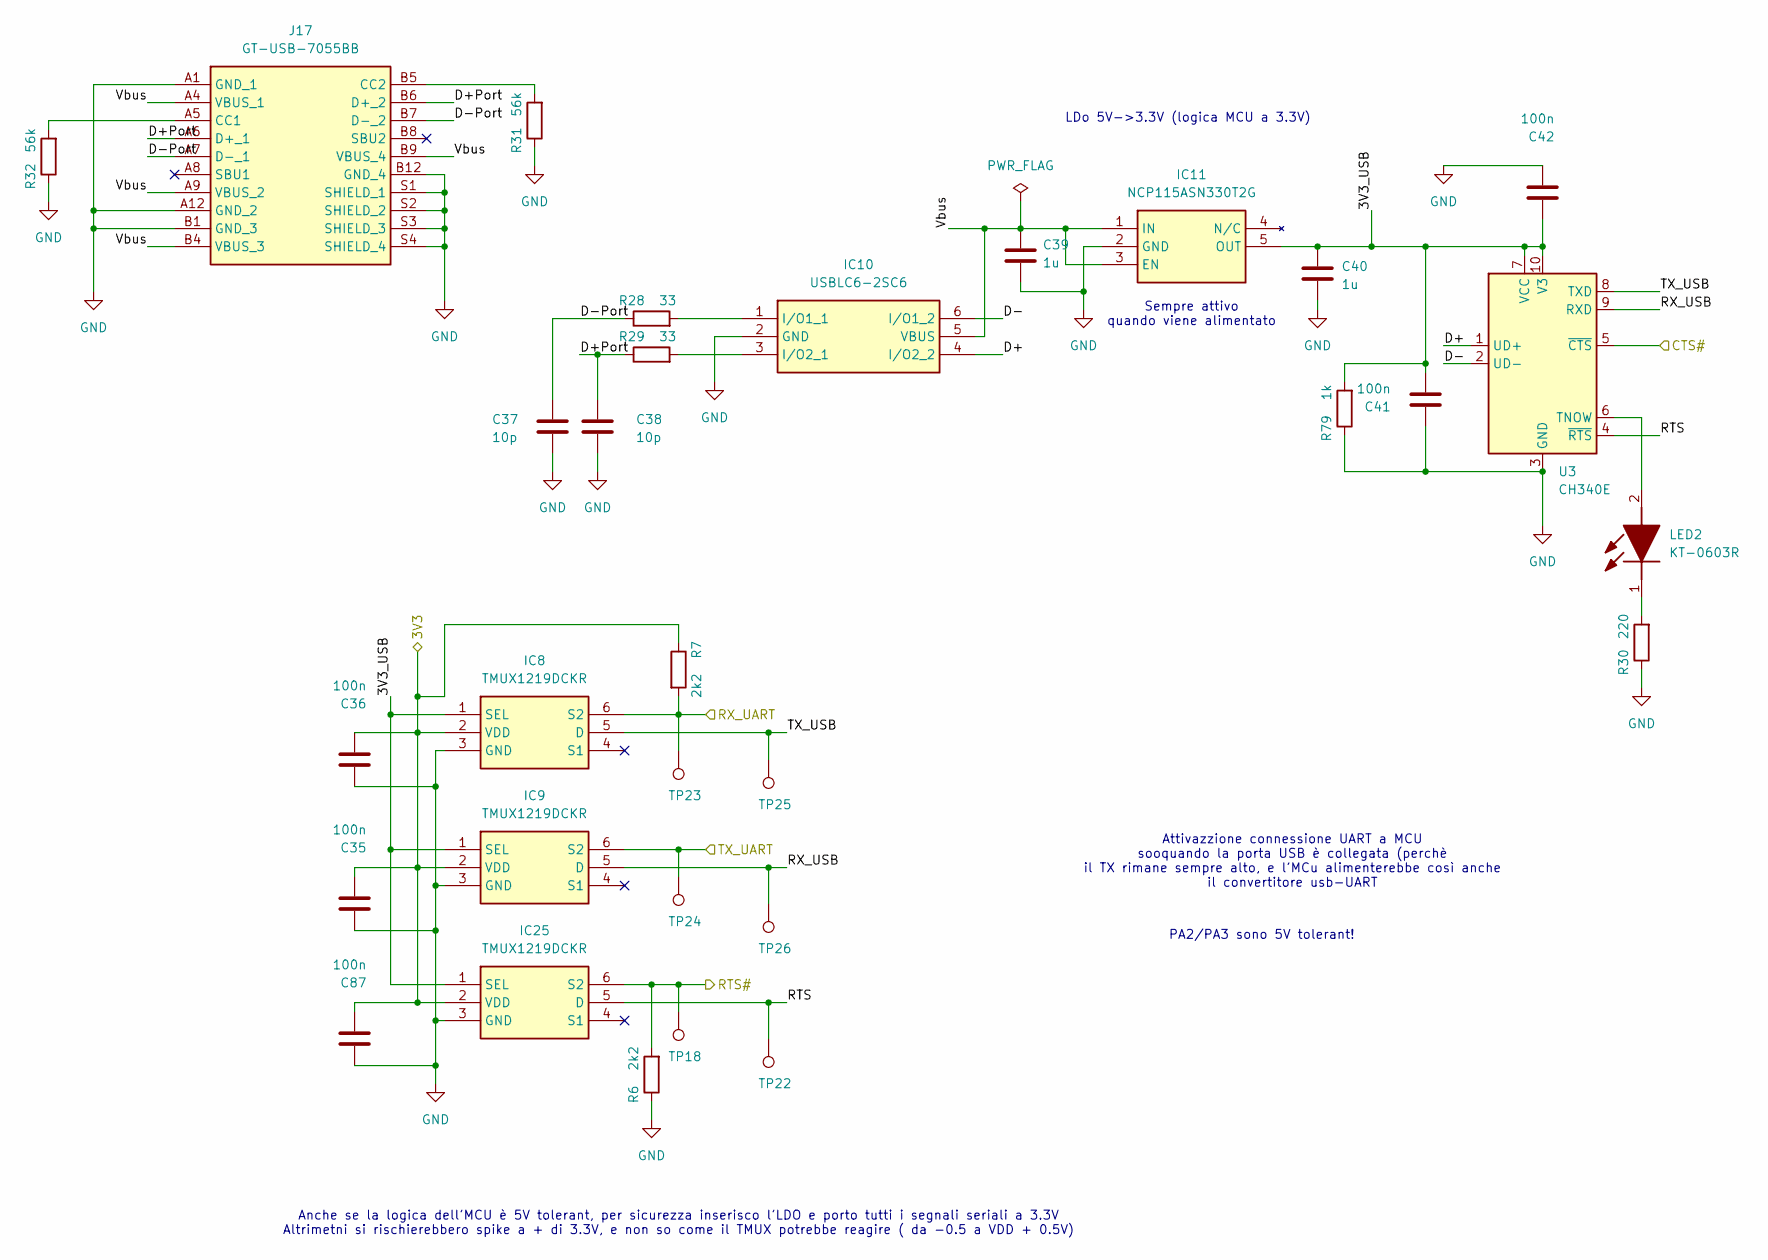
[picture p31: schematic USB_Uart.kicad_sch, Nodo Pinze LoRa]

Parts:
C35, C36, C41, C42, C87: 100n; C_0402_1005Metric_Pad0.74x0.62mm_HandSolder; LCSC C1525
C37, C38: 10p; C_0402_1005Metric_Pad0.74x0.62mm_HandSolder; LCSC C32949
C39, C40: 1u; C_0402_1005Metric_Pad0.74x0.62mm_HandSolder; LCSC C52923
IC8, IC9, IC25: TMUX1219DCKR; SOT65P210X110-6N; Manufacturer_Part_Number TMUX1219DCKR; Mouser Part Number 595-TMUX1219DCKR
IC10: USBLC6-2SC6; SOT95P280X145-6N; Manufacturer_Part_Number USBLC6-2SC6; Mouser Part Number 511-USBLC6-2SC6
IC11: NCP115ASN330T2G; SOT95P275X110-5N; Manufacturer_Part_Number NCP115ASN330T2G; Mouser Part Number 863-NCP115ASN330T2G
J17: GT-USB-7055BB; GTUSB7055BB; Manufacturer_Part_Number GT-USB-7055BB; LCSC C7450621
LED2: KT-0603R; LEDC1608X70N; Manufacturer_Part_Number KT-0603R; LCSC C2286
R6, R7: 2k2; R_0402_1005Metric; LCSC C25879
R28, R29: 33; R_0402_1005Metric; LCSC C25105
R30: 220; R_0402_1005Metric; LCSC C25091
R31, R32: 56k; R_0402_1005Metric; LCSC C23206
R79: 1k; R_0402_1005Metric; LCSC C11702
TP18, TP22, TP23, TP24, TP25, TP26: TestPoint; TestPoint_Pad_1.0x1.0mm
U3: CH340E; MSOP-10_3x3mm_P0.5mm; LCSC C99652

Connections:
/CTS#: U3.5 (~CTS); also elsewhere on the board
/RTS#: IC25.6 (S2), R6.2, TP18.1 (1_1); also elsewhere on the board
/USART2_RX_PA3: IC8.6 (S2), R7.2, TP23.1 (1_1); also elsewhere on the board
/USART2_TX_PA2: IC9.6 (S2), TP24.1 (1_1); also elsewhere on the board
/USB_Uart/3V3_USB: C40.1, C41.2, C42.1, IC8.1 (SEL), IC9.1 (SEL), IC11.5 (OUT), IC25.1 (SEL), R79.2, U3.7 (VCC), U3.10 (V3)
/USB_Uart/D+: IC10.4 (I/O2_2), U3.1 (UD+)
/USB_Uart/D+Port: C38.1, J17.A6 (D+_1), J17.B6 (D+_2), R29.1
/USB_Uart/D-: IC10.6 (I/O1_2), U3.2 (UD-)
/USB_Uart/D-Port: C37.1, J17.A7 (D-_1), J17.B7 (D-_2), R28.1
/USB_Uart/RTS: IC25.5 (D), TP22.1 (1_1), U3.4 (~RTS)
/USB_Uart/RX_USB: IC9.5 (D), TP26.1 (1_1), U3.9 (RXD)
/USB_Uart/TX_USB: IC8.5 (D), TP25.1 (1_1), U3.8 (TXD)
/USB_Uart/Vbus: C39.1, IC10.5 (VBUS), IC11.1 (IN), IC11.3 (EN), J17.A4 (VBUS_1), J17.A9 (VBUS_2), J17.B4 (VBUS_3), J17.B9 (VBUS_4)
GND: C35.1, C36.1, C37.2, C38.2, C39.2, C40.2, C41.1, C42.2, C87.1, IC8.3 (GND), IC9.3 (GND), IC10.2 (GND), IC11.2 (GND), IC25.3 (GND), J17.A1 (GND_1), J17.A12 (GND_2), J17.B1 (GND_3), J17.B12 (GND_4), J17.S1 (SHIELD_1), J17.S2 (SHIELD_2), J17.S3 (SHIELD_3), J17.S4 (SHIELD_4), R6.1, R30.1, R31.1, R32.1, R79.1, U3.3 (GND); also elsewhere on the board
unnamed: IC10.1 (I/O1_1), R28.2
unnamed: IC10.3 (I/O2_1), R29.2
unnamed: J17.A5 (CC1), R32.2
unnamed: J17.B5 (CC2), R31.2
unnamed: LED2.2 (A), U3.6 (TNOW)
unnamed: LED2.1 (K), R30.2
VDD_MCU_LRA: C35.2, C36.2, C87.2, IC8.2 (VDD), IC9.2 (VDD), IC25.2 (VDD), R7.1; also elsewhere on the board

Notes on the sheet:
PA2/PA3 sono 5V tolerant!
Attivazzione connessione UART a MCU sooquando la porta USB è collegata (perchè il TX rimane sempre alto, e l'MCu alimenterebbe così anche il convertitore usb-UART
Sempre attivo quando viene alimentato
LDo 5V->3.3V (logica MCU a 3.3V)
Anche se la logica dell'MCU è 5V tolerant, per sicurezza inserisco l'LDO e porto tutti i segnali seriali a 3.3V Altrimetni si rischierebbero spike a + di 3.3V, e non so come il TMUX potrebbe reagire ( da -0.5 a VDD + 0.5V)

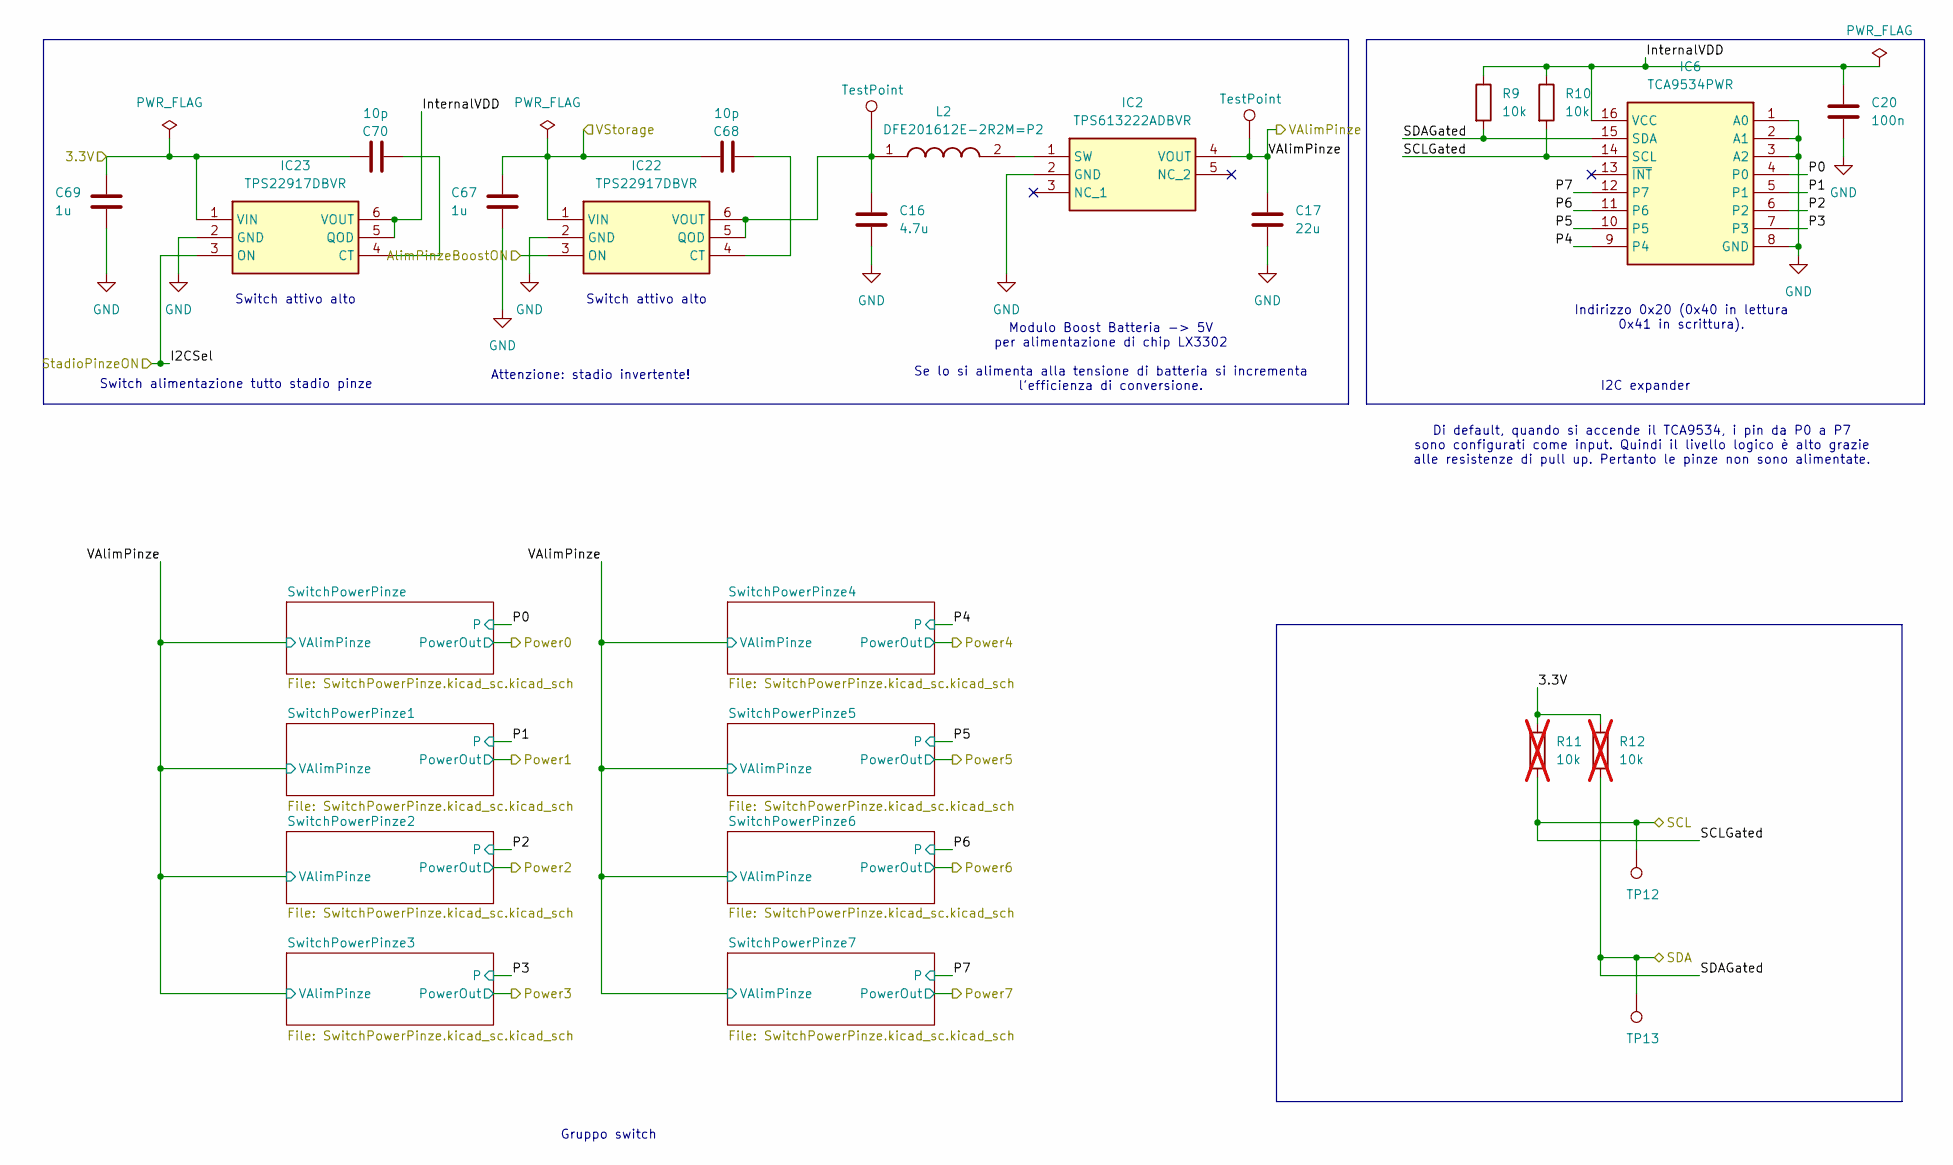
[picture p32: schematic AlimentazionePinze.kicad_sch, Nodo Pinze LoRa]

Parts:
C16: 4.7u; C_0402_1005Metric_Pad0.74x0.62mm_HandSolder; LCSC C23733
C17: 22u; C_0805_2012Metric_Pad1.18x1.45mm_HandSolder; LCSC C45783
C20: 100n; C_0402_1005Metric_Pad0.74x0.62mm_HandSolder; LCSC C1525
C67, C69: 1u; C_0402_1005Metric_Pad0.74x0.62mm_HandSolder; LCSC C52923
C68, C70: 10p; C_0402_1005Metric_Pad0.74x0.62mm_HandSolder; LCSC C32949
IC2: TPS613222ADBVR; SOT95P280X145-5N; Manufacturer_Part_Number TPS613222ADBVR; Mouser Part Number 595-TPS613222ADBVR
IC6: TCA9534PWR; SOP65P640X120-16N; Manufacturer_Part_Number TCA9534PWR; Mouser Part Number 595-TCA9534PWR
IC22, IC23: TPS22917DBVR; SOT95P280X145-6N; Manufacturer_Part_Number TPS22917DBVR; Mouser Part Number 595-TPS22917DBVR
L2: DFE201612E-2R2M=P2; 1286ASH1R0MP2; Manufacturer_Part_Number DFE201612E-2R2M=P2; Mouser Part Number 81-DFE201612E-2R2MP2
R9, R10: 10k; R_0402_1005Metric; LCSC C25744
R11, R12: 10k; R_0402_1005Metric; LCSC C25744; not fitted
TP10, TP11, TP12, TP13: TestPoint; TestPoint_Pad_1.0x1.0mm

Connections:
/+5V: C17.1, IC2.4 (VOUT), TP11.1 (1_1); also elsewhere on the board
/AlimentazionePinze/InternalVDD: C20.1, IC6.16 (VCC), IC23.5 (QOD), IC23.6 (VOUT), R9.1, R10.1
/AlimentazionePinze/P0: IC6.4 (P0); also elsewhere on the board
/AlimentazionePinze/P1: IC6.5 (P1); also elsewhere on the board
/AlimentazionePinze/P2: IC6.6 (P2); also elsewhere on the board
/AlimentazionePinze/P3: IC6.7 (P3); also elsewhere on the board
/AlimentazionePinze/P4: IC6.9 (P4); also elsewhere on the board
/AlimentazionePinze/P5: IC6.10 (P5); also elsewhere on the board
/AlimentazionePinze/P6: IC6.11 (P6); also elsewhere on the board
/AlimentazionePinze/P7: IC6.12 (P7); also elsewhere on the board
/BoostOnPinze: IC22.3 (ON); also elsewhere on the board
/I2C1_SCL_PA12: IC6.14 (SCL), R10.2, R11.2, TP12.1 (1_1); also elsewhere on the board
/I2C1_SDA_PA11: IC6.15 (SDA), R9.2, R12.2, TP13.1 (1_1); also elsewhere on the board
/PinzeOn: IC23.3 (ON); also elsewhere on the board
/VBattery: C67.1, C68.1, IC22.1 (VIN); also elsewhere on the board
GND: C16.2, C17.2, C20.2, C67.2, C69.2, IC2.2 (GND), IC6.1 (A0), IC6.2 (A1), IC6.3 (A2), IC6.8 (GND), IC22.2 (GND), IC23.2 (GND); also elsewhere on the board
unnamed: IC2.1 (SW), L2.2
unnamed: C68.2, IC22.4 (CT)
unnamed: C16.1, IC22.5 (QOD), IC22.6 (VOUT), L2.1, TP10.1 (1_1)
unnamed: C70.2, IC23.4 (CT)
VDD_MCU_LRA: C69.1, C70.1, IC23.1 (VIN), R11.1, R12.1; also elsewhere on the board

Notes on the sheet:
Attenzione: stadio invertente!
Modulo Boost Batteria -> 5V per alimentazione di chip LX3302 Se lo si alimenta alla tensione di batteria si incrementa l'efficienza di conversione.
Gruppo switch
Di default, quando si accende il TCA9534, i pin da P0 a P7 sono configurati come input. Quindi il livello logico è alto grazie alle resistenze di pull up. Pertanto le pinze non sono alimentate.
Switch attivo alto
I2C expander
Indirizzo 0x20 (0x40 in lettura 0x41 in scrittura).
Switch alimentazione tutto stadio pinze

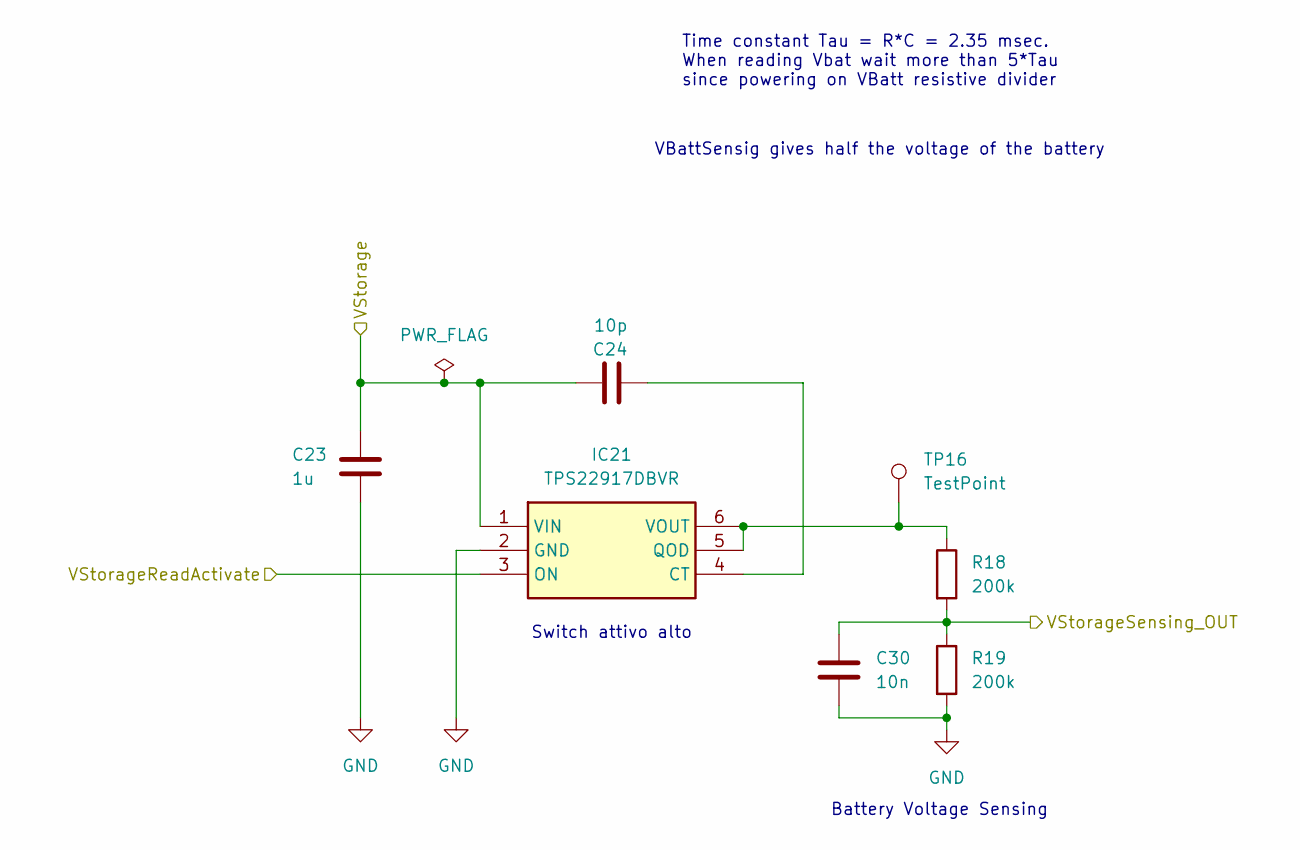
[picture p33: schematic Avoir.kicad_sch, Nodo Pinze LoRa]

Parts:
C23: 1u; C_0402_1005Metric_Pad0.74x0.62mm_HandSolder; LCSC C52923
C24: 10p; C_0402_1005Metric_Pad0.74x0.62mm_HandSolder; LCSC C32949
C30: 10n; C_0402_1005Metric_Pad0.74x0.62mm_HandSolder; LCSC C15195
IC21: TPS22917DBVR; SOT95P280X145-6N; Manufacturer_Part_Number TPS22917DBVR; Mouser Part Number 595-TPS22917DBVR
R18, R19: 200k; R_0402_1005Metric; LCSC C25764
TP16: TestPoint; TestPoint_Pad_1.0x1.0mm

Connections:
/VBattery: C23.1, C24.1, IC21.1 (VIN); also elsewhere on the board
/VStorageReadActivate: IC21.3 (ON); also elsewhere on the board
/VStorageSensing: C30.1, R18.2, R19.1; also elsewhere on the board
GND: C23.2, C30.2, IC21.2 (GND), R19.2; also elsewhere on the board
unnamed: C24.2, IC21.4 (CT)
unnamed: IC21.5 (QOD), IC21.6 (VOUT), R18.1, TP16.1 (1_1)

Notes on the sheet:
Time constant Tau = R*C = 2.35 msec. When reading Vbat wait more than 5*Tau since powering on VBatt resistive divider
VBattSensig gives half the voltage of the battery
Switch attivo alto
Battery Voltage Sensing

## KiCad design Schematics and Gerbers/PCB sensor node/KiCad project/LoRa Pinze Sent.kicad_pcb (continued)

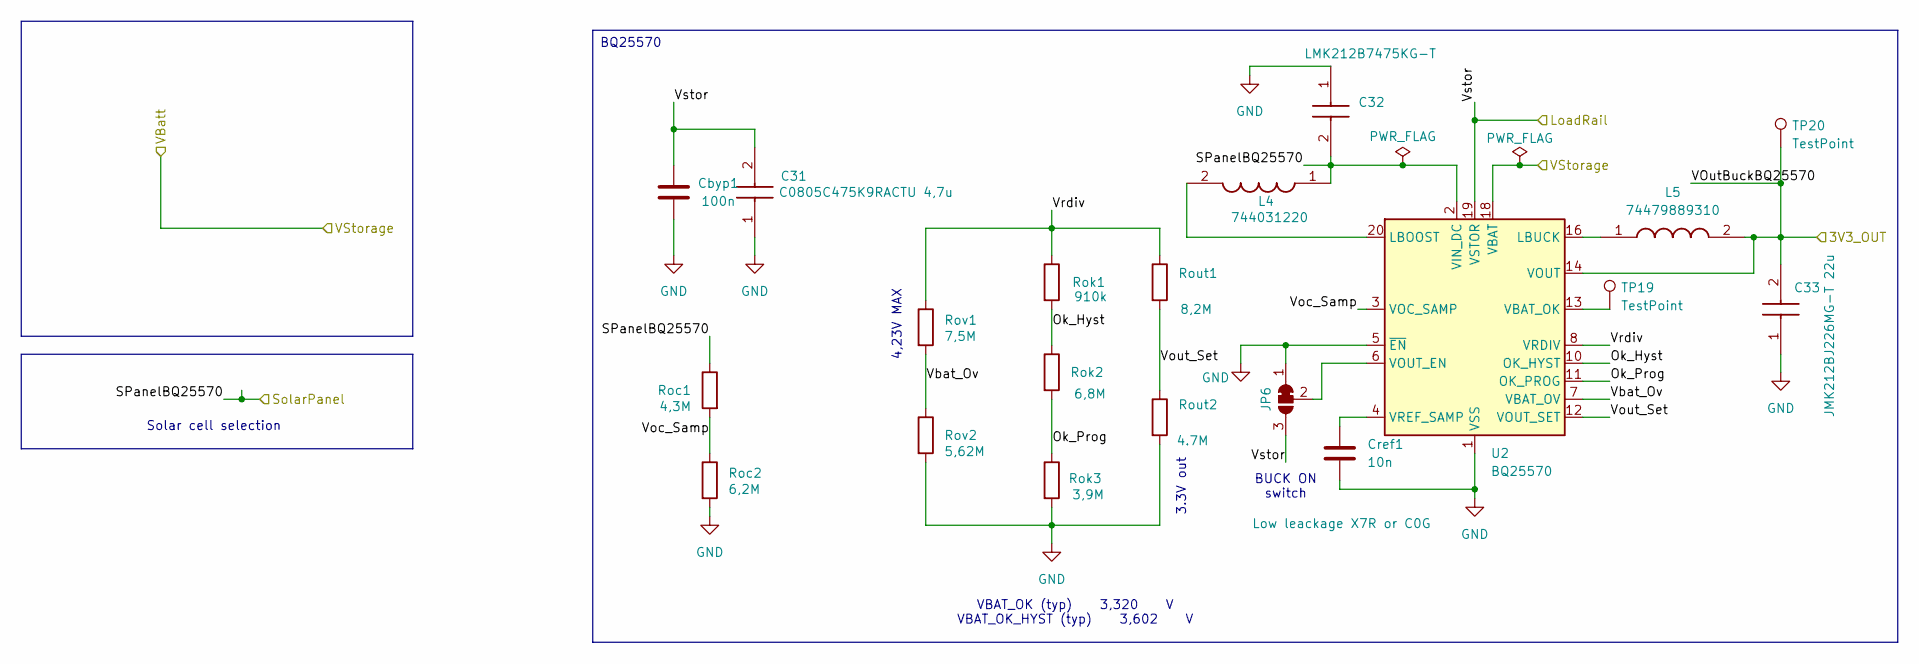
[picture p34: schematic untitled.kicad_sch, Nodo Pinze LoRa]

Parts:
C31: C0805C475K9RACTU 4,7u; C0805; Manufacturer_Part_Number C0805C475K9RACTU; Mouser Part Number 80-C0805C475K9R
C32: LMK212B7475KG-T; CAPC2012X135N; Manufacturer_Part_Number LMK212B7475KG-T; Mouser Part Number 963-LMK212B7475KG-T
C33: JMK212BJ226MG-T 22u; CAPC2013X135N; Manufacturer_Part_Number JMK212BJ226MG-T; Mouser Part Number 963-JMK212BJ226MG-T
Cbyp1: 100n; C_0402_1005Metric_Pad0.74x0.62mm_HandSolder; LCSC C1525
Cref1: 10n; C_0402_1005Metric_Pad0.74x0.62mm_HandSolder; LCSC C15195
JP6: SolderJumper_3_Bridged12; SolderJumper-3_P1.3mm_Bridged12_RoundedPad1.0x1.5mm_NumberL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
L4: 744031220; WE-TPC_381692; Manufacturer_Part_Number 744031220; Mouser Part Number 710-744031220
L5: 74479889310; INDC2521X120N; Manufacturer_Part_Number 74479889310; LCSC C191565
Roc1: 4,3M; R_0402_1005Metric_Pad0.72x0.64mm_HandSolder; LCSC C327242
Roc2: 6,2M; R_0402_1005Metric_Pad0.72x0.64mm_HandSolder; LCSC C159000
Rok1: 910k; R_0402_1005Metric_Pad0.72x0.64mm_HandSolder; LCSC C324817
Rok2: 6,8M; R_0402_1005Metric_Pad0.72x0.64mm_HandSolder; LCSC C620473
Rok3: 3,9M; R_0402_1005Metric_Pad0.72x0.64mm_HandSolder; LCSC C30329
Rout1: 8,2M; R_0402_1005Metric_Pad0.72x0.64mm_HandSolder; LCSC C172186
Rout2: 4.7M; R_0402_1005Metric_Pad0.72x0.64mm_HandSolder; LCSC C49654986
Rov1: 7,5M; R_0402_1005Metric_Pad0.72x0.64mm_HandSolder; LCSC C137839
Rov2: 5,62M; R_0402_1005Metric_Pad0.72x0.64mm_HandSolder; LCSC C2929925
TP19, TP20: TestPoint; TestPoint_Pad_1.0x1.0mm
U2: BQ25570; QFN-20-1EP_3.5x3.5mm_P0.5mm_EP2x2mm; LCSC C506250

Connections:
/LoadRail: C31.2, Cbyp1.2, JP6.3 (B), U2.19 (VSTOR)
/SolarPanel: C32.2, L4.1, Roc1.1, U2.2 (VIN_DC); also elsewhere on the board
/VBattery: U2.18 (VBAT); also elsewhere on the board
/power_supply1/Ok_Hyst: Rok1.2, Rok2.1, U2.10 (OK_HYST)
/power_supply1/Ok_Prog: Rok2.2, Rok3.1, U2.11 (OK_PROG)
/power_supply1/Vbat_Ov: Rov1.2, Rov2.1, U2.7 (VBAT_OV)
/power_supply1/Voc_Samp: Roc1.2, Roc2.1, U2.3 (VOC_SAMP)
/power_supply1/Vout_Set: Rout1.2, Rout2.1, U2.12 (VOUT_SET)
/power_supply1/Vrdiv: Rok1.1, Rout1.1, Rov1.1, U2.8 (VRDIV)
GND: C31.1, C32.1, C33.1, Cbyp1.1, Cref1.1, JP6.1 (A), Roc2.2, Rok3.2, Rout2.2, Rov2.2, U2.1 (VSS), U2.5 (~EN), U2.9 (VSS), U2.15 (VSS), U2.17 (VSS), U2.21 (VSS); also elsewhere on the board
unnamed: JP6.2 (C), U2.6 (VOUT_EN)
unnamed: L4.2, U2.20 (LBOOST)
unnamed: L5.1, U2.16 (LBUCK)
unnamed: TP19.1 (1_1), U2.13 (VBAT_OK)
unnamed: Cref1.2, U2.4 (VREF_SAMP)
VDD_MCU_LRA: C33.2, L5.2, TP20.1 (1_1), U2.14 (VOUT); also elsewhere on the board

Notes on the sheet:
BUCK ON switch
3.3V out
4,23V MAX
Solar cell selection
VBAT_OK (typ) 3,320 V VBAT_OK_HYST (typ) 3,602 V
BQ25570

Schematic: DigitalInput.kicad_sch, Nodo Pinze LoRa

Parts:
D21, D29: BAV199; SOT95P230X100-3N; Manufacturer_Part_Number BAV199; Mouser Part Number N/A
J9: 53398-0471; 533980471; Manufacturer_Part_Number 53398-0471; Mouser Part Number 538-53398-0471
R47, R49: 12k; R_0402_1005Metric; LCSC C25752
R48, R50: 22k; R_0402_1005Metric; LCSC C25768

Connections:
/+5V: D21.2 (CATHODE), D29.2 (CATHODE); also elsewhere on the board
/AlimentazionePinze/Power0: J9.4; also elsewhere on the board
/DigitalInputMux/D0: R47.1, R48.2; also elsewhere on the board
/DigitalInputMux/DigitalInput/IND: D21.3 (COMMON), J9.3, R47.2
/DigitalInputMux/DigitalInput/INT: D29.3 (COMMON), J9.2, R49.2
/DigitalInputMux/T0: R49.1, R50.2; also elsewhere on the board
GND: D21.1 (ANODE), D29.1 (ANODE), J9.1, R48.1, R50.1; also elsewhere on the board

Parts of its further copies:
D22, D23, D24, D25, D26, D27, D28, D30, D31, D32, D33, D34, D35, D36: BAV199; SOT95P230X100-3N; Manufacturer_Part_Number BAV199; Mouser Part Number N/A
J10, J11, J12, J13, J14, J15, J16: 53398-0471; 533980471; Manufacturer_Part_Number 53398-0471; Mouser Part Number 538-53398-0471
R51, R53, R55, R57, R59, R61, R63, R65, R67, R69, R71, R73, R75, R77: 12k; R_0402_1005Metric; LCSC C25752
R52, R54, R56, R58, R60, R62, R64, R66, R68, R70, R72, R74, R76, R78: 22k; R_0402_1005Metric; LCSC C25768

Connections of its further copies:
/+5V: D22.2 (CATHODE), D23.2 (CATHODE), D24.2 (CATHODE), D25.2 (CATHODE), D26.2 (CATHODE), D27.2 (CATHODE), D28.2 (CATHODE), D30.2 (CATHODE), D31.2 (CATHODE), D32.2 (CATHODE), D33.2 (CATHODE), D34.2 (CATHODE), D35.2 (CATHODE), D36.2 (CATHODE); also elsewhere on the board
/AlimentazionePinze/Power1: J10.4; also elsewhere on the board
/AlimentazionePinze/Power2: J11.4; also elsewhere on the board
/AlimentazionePinze/Power3: J12.4; also elsewhere on the board
/AlimentazionePinze/Power4: J13.4; also elsewhere on the board
/AlimentazionePinze/Power5: J14.4; also elsewhere on the board
/AlimentazionePinze/Power6: J15.4; also elsewhere on the board
/AlimentazionePinze/Power7: J16.4; also elsewhere on the board
/DigitalInputMux/D1: R51.1, R52.2; also elsewhere on the board
/DigitalInputMux/D2: R55.1, R56.2; also elsewhere on the board
/DigitalInputMux/D3: R59.1, R60.2; also elsewhere on the board
/DigitalInputMux/D4: R63.1, R64.2; also elsewhere on the board
/DigitalInputMux/D5: R67.1, R68.2; also elsewhere on the board
/DigitalInputMux/D6: R71.1, R72.2; also elsewhere on the board
/DigitalInputMux/D7: R75.1, R76.2; also elsewhere on the board
/DigitalInputMux/DigitalInput1/IND: D22.3 (COMMON), J10.3, R51.2
/DigitalInputMux/DigitalInput1/INT: D30.3 (COMMON), J10.2, R53.2
/DigitalInputMux/DigitalInput2/IND: D23.3 (COMMON), J11.3, R55.2
/DigitalInputMux/DigitalInput2/INT: D31.3 (COMMON), J11.2, R57.2
/DigitalInputMux/DigitalInput3/IND: D24.3 (COMMON), J12.3, R59.2
/DigitalInputMux/DigitalInput3/INT: D32.3 (COMMON), J12.2, R61.2
/DigitalInputMux/DigitalInput4/IND: D25.3 (COMMON), J13.3, R63.2
/DigitalInputMux/DigitalInput4/INT: D33.3 (COMMON), J13.2, R65.2
/DigitalInputMux/DigitalInput5/IND: D26.3 (COMMON), J14.3, R67.2
/DigitalInputMux/DigitalInput5/INT: D34.3 (COMMON), J14.2, R69.2
/DigitalInputMux/DigitalInput6/IND: D27.3 (COMMON), J15.3, R71.2
/DigitalInputMux/DigitalInput6/INT: D35.3 (COMMON), J15.2, R73.2
/DigitalInputMux/DigitalInput7/IND: D28.3 (COMMON), J16.3, R75.2
/DigitalInputMux/DigitalInput7/INT: D36.3 (COMMON), J16.2, R77.2
/DigitalInputMux/T1: R53.1, R54.2; also elsewhere on the board
/DigitalInputMux/T2: R57.1, R58.2; also elsewhere on the board
/DigitalInputMux/T3: R61.1, R62.2; also elsewhere on the board
/DigitalInputMux/T4: R65.1, R66.2; also elsewhere on the board
/DigitalInputMux/T5: R69.1, R70.2; also elsewhere on the board
/DigitalInputMux/T6: R73.1, R74.2; also elsewhere on the board
/DigitalInputMux/T7: R77.1, R78.2; also elsewhere on the board
GND: D22.1 (ANODE), D23.1 (ANODE), D24.1 (ANODE), D25.1 (ANODE), D26.1 (ANODE), D27.1 (ANODE), D28.1 (ANODE), D30.1 (ANODE), D31.1 (ANODE), D32.1 (ANODE), D33.1 (ANODE), D34.1 (ANODE), D35.1 (ANODE), D36.1 (ANODE), J10.1, J11.1, J12.1, J13.1, J14.1, J15.1, J16.1, R52.1, R54.1, R56.1, R58.1, R60.1, R62.1, R64.1, R66.1, R68.1, R70.1, R72.1, R74.1, R76.1, R78.1; also elsewhere on the board

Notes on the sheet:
Partitore resisttivo: entrano 5V, escono 3.23V

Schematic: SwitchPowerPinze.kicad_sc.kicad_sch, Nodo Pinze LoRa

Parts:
C43, C45: 1u; C_0402_1005Metric_Pad0.74x0.62mm_HandSolder; LCSC C52923
C44: 10p; C_0402_1005Metric_Pad0.74x0.62mm_HandSolder; LCSC C32949
IC13: TPS22917DBVR; SOT95P280X145-6N; Manufacturer_Part_Number TPS22917DBVR; Mouser Part Number 595-TPS22917DBVR

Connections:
/+5V: C43.1, C44.1, IC13.1 (VIN); also elsewhere on the board
/AlimentazionePinze/P0: IC13.3 (ON); also elsewhere on the board
/AlimentazionePinze/Power0: C45.1, IC13.5 (QOD), IC13.6 (VOUT); also elsewhere on the board
GND: C43.2, C45.2, IC13.2 (GND); also elsewhere on the board
unnamed: C44.2, IC13.4 (CT)

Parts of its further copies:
C46, C48, C49, C50, C52, C54, C55, C57, C58, C60, C61, C63, C64, C66, C71, C73: 1u; C_0402_1005Metric_Pad0.74x0.62mm_HandSolder; LCSC C52923
C47, C51, C53, C56, C59, C62, C65, C72: 10p; C_0402_1005Metric_Pad0.74x0.62mm_HandSolder; LCSC C32949
IC14, IC15, IC16, IC17, IC18, IC19, IC20, IC24: TPS22917DBVR; SOT95P280X145-6N; Manufacturer_Part_Number TPS22917DBVR; Mouser Part Number 595-TPS22917DBVR

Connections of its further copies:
/+5V: C46.1, C47.1, C49.1, C50.1, C51.1, C53.1, C55.1, C56.1, C58.1, C59.1, C61.1, C62.1, C64.1, C65.1, IC14.1 (VIN), IC15.1 (VIN), IC16.1 (VIN), IC17.1 (VIN), IC18.1 (VIN), IC19.1 (VIN), IC20.1 (VIN); also elsewhere on the board
/AlimentazionePinze/P1: IC14.3 (ON); also elsewhere on the board
/AlimentazionePinze/P2: IC15.3 (ON); also elsewhere on the board
/AlimentazionePinze/P3: IC16.3 (ON); also elsewhere on the board
/AlimentazionePinze/P4: IC17.3 (ON); also elsewhere on the board
/AlimentazionePinze/P5: IC18.3 (ON); also elsewhere on the board
/AlimentazionePinze/P6: IC19.3 (ON); also elsewhere on the board
/AlimentazionePinze/P7: IC20.3 (ON); also elsewhere on the board
/AlimentazionePinze/Power1: C48.1, IC14.5 (QOD), IC14.6 (VOUT); also elsewhere on the board
/AlimentazionePinze/Power2: C54.1, IC15.5 (QOD), IC15.6 (VOUT); also elsewhere on the board
/AlimentazionePinze/Power3: C57.1, IC16.5 (QOD), IC16.6 (VOUT); also elsewhere on the board
/AlimentazionePinze/Power4: C60.1, IC17.5 (QOD), IC17.6 (VOUT); also elsewhere on the board
/AlimentazionePinze/Power5: C63.1, IC18.5 (QOD), IC18.6 (VOUT); also elsewhere on the board
/AlimentazionePinze/Power6: C66.1, IC19.5 (QOD), IC19.6 (VOUT); also elsewhere on the board
/AlimentazionePinze/Power7: C52.1, IC20.5 (QOD), IC20.6 (VOUT); also elsewhere on the board
/AnalogPowerIN: IC24.3 (ON); also elsewhere on the board
/InputAnalogico/AnalogSupply: C73.1, IC24.5 (QOD), IC24.6 (VOUT); also elsewhere on the board
GND: C46.2, C48.2, C49.2, C50.2, C52.2, C54.2, C55.2, C57.2, C58.2, C60.2, C61.2, C63.2, C64.2, C66.2, C71.2, C73.2, IC14.2 (GND), IC15.2 (GND), IC16.2 (GND), IC17.2 (GND), IC18.2 (GND), IC19.2 (GND), IC20.2 (GND), IC24.2 (GND); also elsewhere on the board
unnamed: C47.2, IC14.4 (CT)
unnamed: C53.2, IC15.4 (CT)
unnamed: C56.2, IC16.4 (CT)
unnamed: C59.2, IC17.4 (CT)
unnamed: C62.2, IC18.4 (CT)
unnamed: C65.2, IC19.4 (CT)
unnamed: C51.2, IC20.4 (CT)
unnamed: C72.2, IC24.4 (CT)
VDD_MCU_LRA: C71.1, C72.1, IC24.1 (VIN); also elsewhere on the board

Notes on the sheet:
Switch attivo alto

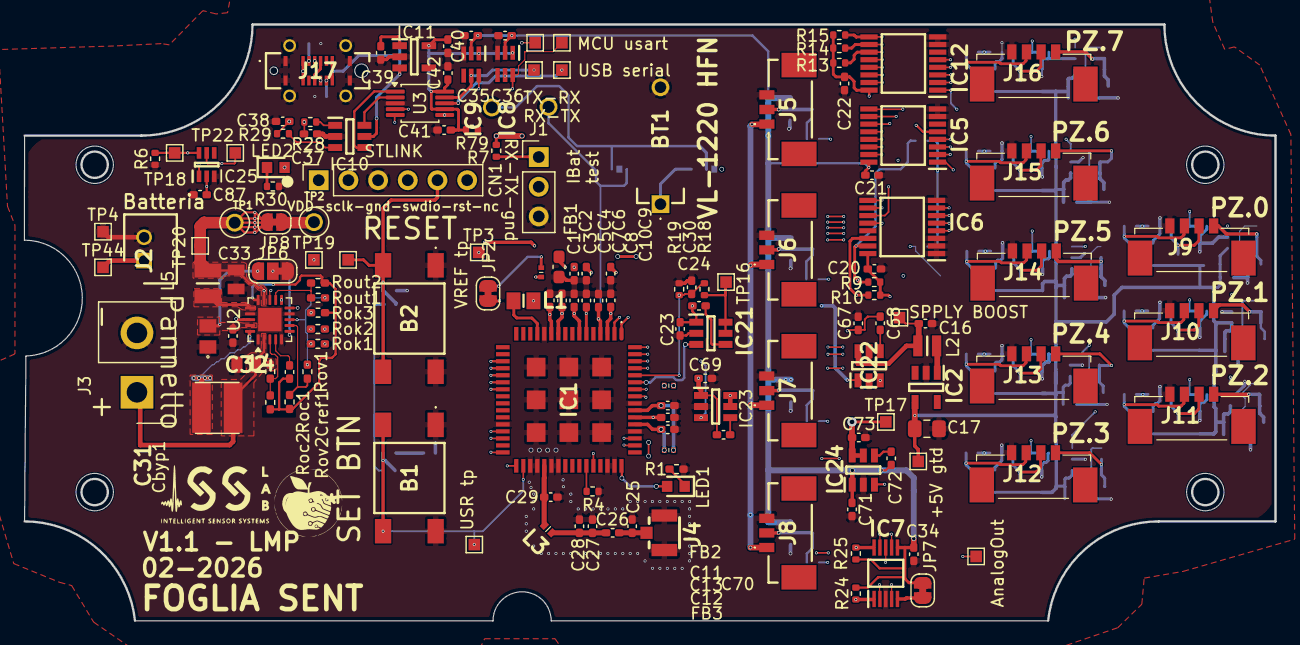
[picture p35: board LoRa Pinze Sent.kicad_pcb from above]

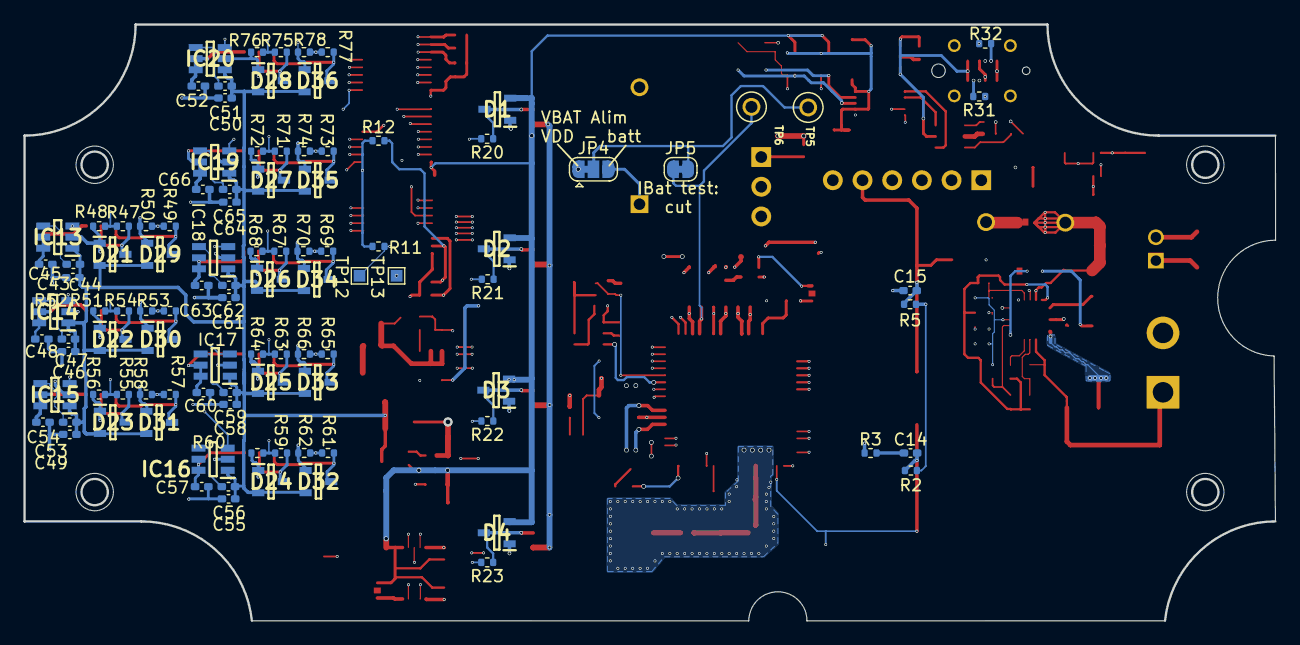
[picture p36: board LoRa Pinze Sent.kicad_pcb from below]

Board: 6 copper layers, 107.0 x 51.0 mm, 253 parts (103 on the bottom side), 146 nets.

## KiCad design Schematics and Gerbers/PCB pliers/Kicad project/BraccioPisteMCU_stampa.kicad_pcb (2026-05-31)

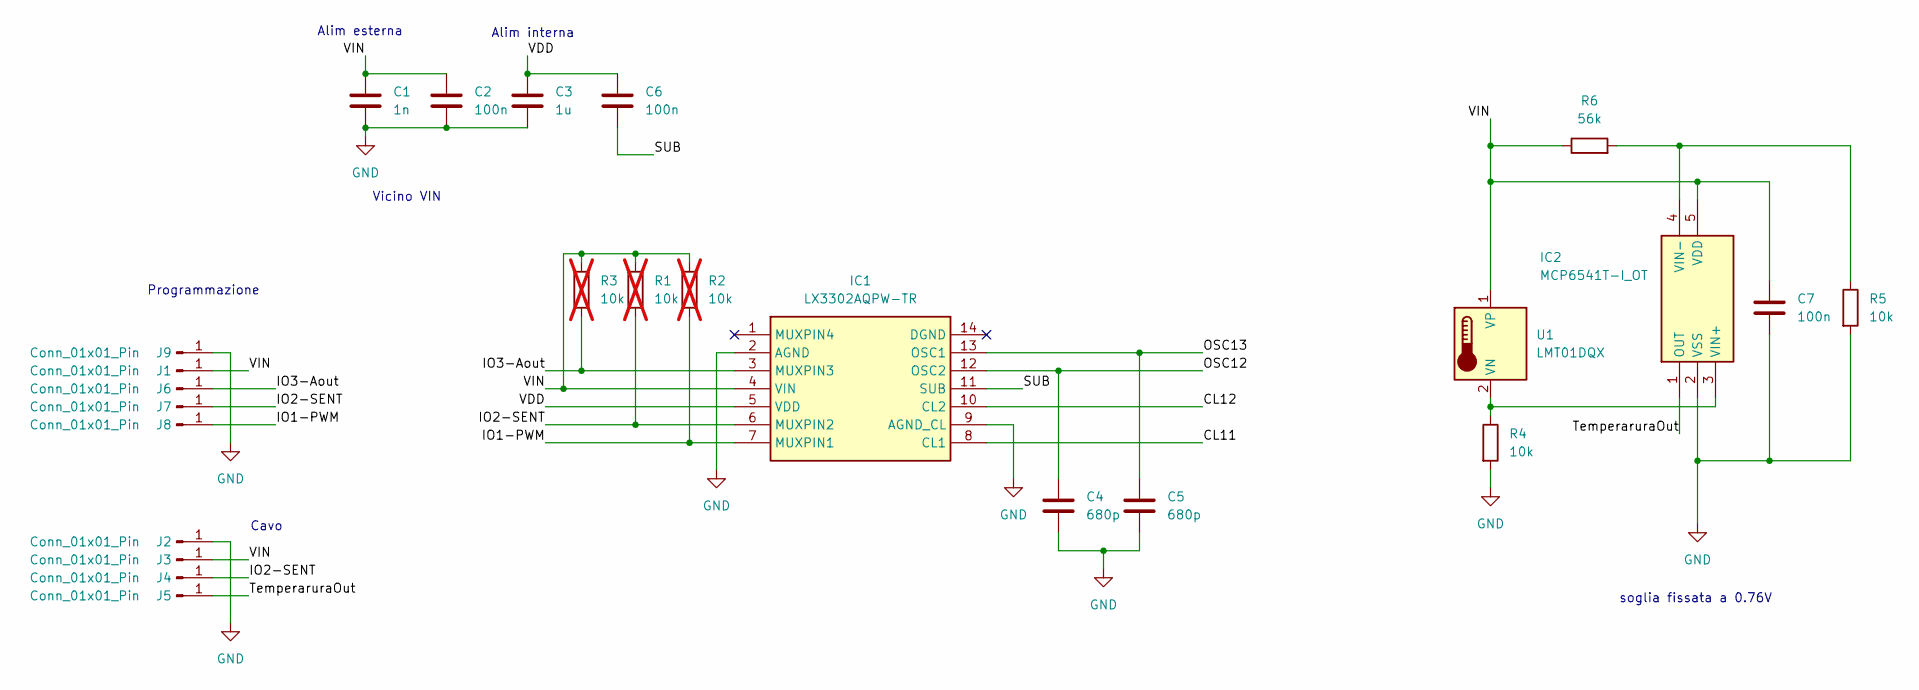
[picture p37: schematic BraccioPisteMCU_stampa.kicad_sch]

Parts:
C1: 1n; C_0402_1005Metric_Pad0.74x0.62mm_HandSolder
C2, C6, C7: 100n; C_0402_1005Metric_Pad0.74x0.62mm_HandSolder
C3: 1u; C_0402_1005Metric_Pad0.74x0.62mm_HandSolder
C4, C5: 680p; C_0402_1005Metric_Pad0.74x0.62mm_HandSolder
IC1: LX3302AQPW-TR; SOP65P640X120-14N; Manufacturer_Part_Number LX3302AQPW-TR; Mouser Part Number 494-LX3302AQPW-TR
IC2: MCP6541T-I_OT; SOT95P270X145-5N; Manufacturer_Part_Number MCP6541T-I/OT; Mouser Part Number 579-MCP6541T-I/OT
J1, J2, J3, J4, J5, J6, J7, J8, J9: Conn_01x01_Pin; SolderWirePad_1x01_SMD_1x2mm
R1, R2, R3: 10k; R_0402_1005Metric_Pad0.72x0.64mm_HandSolder; not fitted
R4, R5: 10k; R_0402_1005Metric_Pad0.72x0.64mm_HandSolder
R6: 56k; R_0402_1005Metric_Pad0.72x0.64mm_HandSolder
U1: LMT01DQX; Texas_DQX002A

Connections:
/CL11: IC1.8 (CL1)
/CL12: IC1.10 (CL2)
/IO1-PWM: IC1.7 (MUXPIN1), J8.1 (Pin_1_1), R2.2
/IO2-SENT: IC1.6 (MUXPIN2), J4.1 (Pin_1_1), J7.1 (Pin_1_1), R1.2
/IO3-Aout: IC1.3 (MUXPIN3), J6.1 (Pin_1_1), R3.2
/OSC12: C4.1, IC1.12 (OSC2)
/OSC13: C5.1, IC1.13 (OSC1)
/SUB: C6.2, IC1.11 (SUB)
/TemperaruraOut: IC2.1 (OUT), J5.1 (Pin_1_1)
/VDD: C3.1, C6.1, IC1.5 (VDD)
/VIN: C1.1, C2.1, C7.1, IC1.4 (VIN), IC2.5 (VDD), J1.1 (Pin_1_1), J3.1 (Pin_1_1), R1.1, R2.1, R3.1, R6.1, U1.1 (VP)
GND: C1.2, C2.2, C3.2, C4.2, C5.2, C7.2, IC1.2 (AGND), IC1.9 (AGND_CL), IC2.2 (VSS), J2.1 (Pin_1_1), J9.1 (Pin_1_1), R4.2, R5.2
unnamed: IC2.3 (VIN+), R4.1, U1.2 (VN)
unnamed: IC2.4 (VIN-), R5.1, R6.2

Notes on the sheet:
Vicino VIN
soglia fissata a 0.76V
Cavo
Alim esterna
Alim interna
Programmazione

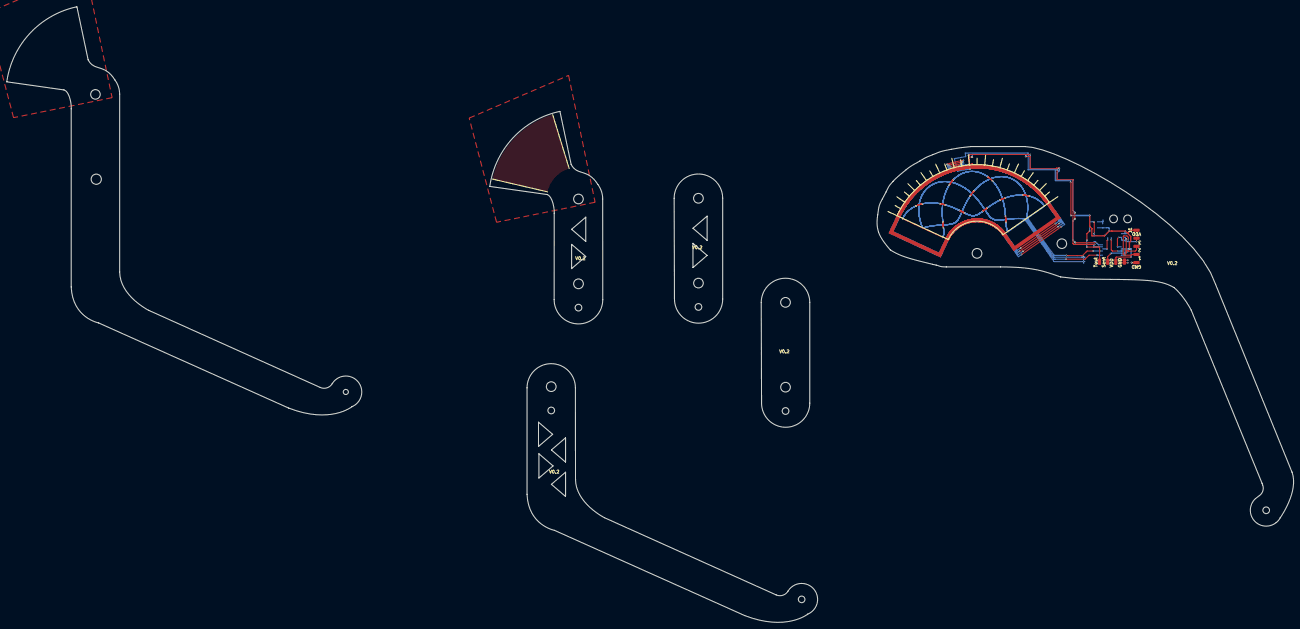
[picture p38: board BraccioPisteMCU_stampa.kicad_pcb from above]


Board: 2 copper layers, 130.8 x 119.2 mm, 25 parts (16 on the bottom side), 12 nets.

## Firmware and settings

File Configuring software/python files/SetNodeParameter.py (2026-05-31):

import sys

import serial.tools.list_ports

import serial

import time

import re

from datetime import datetime, timezone

from Battery_Widget import BatteryWidget

from PyQt6.QtWidgets import (QApplication, QDialog, QMainWindow, QMessageBox, QVBoxLayout)

import struct

# permette di lavorare sui campi vari
from PyQt6.QtCore import QRegularExpression, QLocale, QTimer
from PyQt6.QtGui import QRegularExpressionValidator, QDoubleValidator

from Battery_Widget import BatteryWidget

from PyQt6.uic import loadUi

# per interfacce batteria
from PyQt6.QtWidgets import QWidget
from PyQt6.QtGui import QPainter, QPen, QColor
from PyQt6.QtCore import Qt, QRect, QSize
# ------------

from main_window import Ui_MainWindow

import immaginiLoghi
import risorse

# COSTANTI
NUM_ANALOG_SENSORS = 4
NUM_PINZE = 8
DIMENSIONE_DATI_SENSORI = 104

class Window(QMainWindow, Ui_MainWindow):
    def __init__(self, parent=None):
        super().__init__(parent)
        self.ser = None
        self.min_voltageBatt = 3.2
        self.max_voltageBatt = 4.25
        self.min_voltageBattBackup = 2
        self.max_voltageBattBackup = 3.3
        self.segments = 10

        self.setupUi(self)
        self.connectSignalsSlots()
        self.findSerialPorts()


        self.graphicBattery = BatteryWidget(self, segments=self.segments, min_voltage=self.min_voltageBatt, max_voltage=self.max_voltageBatt, orientation=Qt.Orientation.Horizontal)
        self.graphicBattery.setFixedSize(150, 100)
        self.graphicBatteryBackup = BatteryWidget(self, segments=self.segments, min_voltage=self.min_voltageBattBackup, max_voltage=self.max_voltageBattBackup, orientation=Qt.Orientation.Horizontal)
        self.graphicBatteryBackup.setFixedSize(150, 100)
#        if self.frameGraficaBatterie.layout() is None:
#            layout = QVBoxLayout(self.frameGraficaBatterie)
#            self.frameGraficaBatterie.setLayout(layout)
        self.frameVBatt.layout().addWidget(self.graphicBattery)
        self.frameVBackup.layout().addWidget(self.graphicBatteryBackup)
        self.pushConfigLetture.setEnabled(False)



   
# qui collego i bottoni alle varie funzioni
    def SetLoRaParam(self):
        LoRaSetWin = SetLoRaParam(self)
        LoRaSetWin.exec()

    def SensorsData(self):
        LoRaSetWin = SensorsData(self)
        LoRaSetWin.show()
        

# qui definisco le azioni quando si preme qualcosa
    def connectSignalsSlots(self):
        self.action_Exit.triggered.connect(self.close)
        self.pushModificaLoRaConfig.clicked.connect(self.SetLoRaParam)
        self.push_SerialFind.clicked.connect(self.findSerialPorts)
        self.push_serialConnect.clicked.connect(self.serialButtonControl)
        self.pushLeggiDati.clicked.connect(self.LeggiConfigLoRa)
        self.push_SetOrario.clicked.connect(self.scriviOrario)
        self.pushConfigLetture.clicked.connect(self.SensorsData)


    def findSerialPorts(self):
#        if ports:
#            del ports
        # Ottiene la lista delle porte seriali disponibili
        ports = None
        port_list = None
        ports = serial.tools.list_ports.comports()
        port_list = [port.device for port in ports]

 #       # Aggiorna la ComboBox
        self.comboBox_comNumber.clear()
#        self.comboBox_comNumber.addItems(port_list)
        for port in ports:
            display_text = f"{port.device} - {port.description}"
            self.comboBox_comNumber.addItem(display_text, port.device)  # port.device come "data"
 
        # Se ci sono porte, seleziona la prima
        if port_list:
            self.comboBox_comNumber.setCurrentIndex(0)
            self.push_serialConnect.setEnabled(True)

    def getACK(self):
        ack = None
        self.ser.reset_input_buffer()
        ack = self.ser.read(1)
        if (len(ack) != 1):
            errore = 1
        else:
            errore = 0    
        if (ack == b'\xaf'):
            errore = 0
        else:
            print(f"0x{ack[0]:02x}")
#            print(ack)
            errore = 2
        return errore

    def scriviOrario(self):
        times = int(datetime.now(timezone.utc).timestamp())
        timeBytes = times.to_bytes(4, byteorder='little')
        size = len(timeBytes)
        errore = self.Scrividati(timeBytes, [0x06])
        if (errore == 0):
            #time.sleep(0.05)
            #self.ser.write(bytes(timeBytes))
            self.ser.reset_input_buffer()
            statoACK = self.getACK()
            if (statoACK == 0):
                errore = 0
                time.sleep(0.1)
                self.leggiOrario()
            else:
                errore = 1    
        else:
            errore = 1

        #if errore == 0:
        #    time.sleep(0.5)


    def serialDisconnect(self):
        try:
            # lavoro sul pin RTS
            self.ser.rts = True 
            time.sleep(0.5)
            self.ser.close()
            self.push_serialConnect.setText("Serial Connect")
#           del self.ser
            self.groupBox_LoRaConfiguration.setEnabled(False)
            self.comboBox_serialSpeed.setEnabled(True)
            self.comboBox_comNumber.setEnabled(True)
            self.push_SerialFind.setEnabled(True)
            self.pushConfigLetture.setEnabled(False)
#           self.push.setEnabled(False)
            return
        except serial.SerialException as e:
            QMessageBox.critical(self, "Errore", str(e))
            return        

    def serialConnect(self):
        try:
            port = self.comboBox_comNumber.currentData()
            baudRate = self.comboBox_serialSpeed.currentText()
            if not port:
                QMessageBox.warning(self, "Errore", "Nessuna porta selezionata")
                return
            self.ser = serial.Serial(port=port, baudrate=baudRate, timeout=5)
            self.groupBox_LoRaConfiguration.setEnabled(True)
            self.push_serialConnect.setText("Serial Disconnect")
            self.comboBox_serialSpeed.setEnabled(False)
            self.comboBox_comNumber.setEnabled(False)
            self.push_SerialFind.setEnabled(False)
            self.label_3.setText('<html><head/><body><p><img src=":/immaginiBottone/img/green.png"/></p></body></html>')
            self.pushModificaLoRaConfig.setEnabled(False)
            self.pushConfigLetture.setEnabled(True)
            self.comboBox_DRSelection.showPopup = lambda: None
            #alzo il pin RTSn
            self.ser.rts = False
            time.sleep(0.5)
            self.ser.rts = True
            time.sleep(0.5)
            self.ser.rts = False    
            QMessageBox.information(self, "OK", f"Connesso a {port}")
        except serial.SerialException as e:
            QMessageBox.critical(self, "Errore", str(e)) 

    def serialButtonControl(self):
        if self.ser is not None:
            if self.ser.is_open:
                self.serialDisconnect()
            else:
                self.serialConnect()
        else:
            self.serialConnect()
 

    # def LeggiDati(self):
    #     #self.ser.setRTS(True)
    #     hex_list = [0x00]
    #     self.ser.write(bytes(hex_list))
    #     ID = self.ser.read(1)
    #     if (ID == 0xAB)
    #         hex_list = [0x01]
    #         self.ser.write(bytes(hex_list))

    def bytes_to_hex_string(self, data: bytes) -> str:
        return data.hex(":").upper()  

    def LeggiConfigLoRa(self):
        time.sleep(0.5)
        # leggo il campo GetSWVersio
        errore, SWVersion = self.LeggiDati(4, [0x01])
        if errore != 0:
            QMessageBox.critical(self, "Errore", "Errore su porta seriale")
            return
        #leggo il campo LoRaDati
        #  spacchetto i dati di versione
        dimensioniSW = [1,1,1,1]
        SW4, SW3, SW2, SW1 = self.split_bytes(SWVersion, dimensioniSW)
        self.lineEdit_SWVersion.setText(f"{str(int.from_bytes(SW1, 'big'))}.{str(int.from_bytes(SW2, 'big'))}.{str(int.from_bytes(SW3, 'big'))}.{str(int.from_bytes(SW4, 'big'))}")
        errore, LoRaDati = self.LeggiDati(56, [0x02])
        size = len(LoRaDati)
        if errore != 0:
            return
        # spacchetto i valori delle varie variabili LoRa
        dimensioniLoRa = [4, 4, 8, 16, 16, 4, 4]
        DR, DevAddr, AppEUI, NSK, ASK, TXT, ADREnab = self.split_bytes(LoRaDati, dimensioniLoRa)
        self.line_devADDR.setText(self.bytes_to_hex_string(DevAddr))
        self.line_NSK.setText(self.bytes_to_hex_string(NSK))
        self.line_ASK.setText(self.bytes_to_hex_string(ASK))
        self.lineEdit_appEui.setText(self.bytes_to_hex_string(AppEUI))
        #print("La variabile 'basi' è di tipo:", type(ADREnab))
        if (ADREnab == b'\x00\x00\x00\x00'):
            self.checkBoxADR.setChecked(False)
        else:
            self.checkBoxADR.setChecked(True)
        self.lineEdit_TXInterva.setText(str(round(int.from_bytes(TXT, byteorder='big', signed=False)/1000)))
        self.comboBox_DRSelection.setCurrentIndex(int.from_bytes(DR, byteorder = 'big'))
        self.pushModificaLoRaConfig.setEnabled(True)
        self.leggiOrario()
        self.leggiTensioni()
        #QMessageBox.information(self, "Lettura corretta", "Letti tutti i campi LoRa")
        # poi leggiamo anche il tmestamp
#        errore, datiTimestamp = self.LeggiDati(4, [0x05])
#        size = len(datiTimestamp)
#        if errore != 0:
#            return
#        timestamp = int.from_bytes(datiTimestamp, byteorder='little')
#        dt = datetime.fromtimestamp(timestamp)
#        data_str = dt.strftime("%Y-%m-%d %H:%M:%S")
#        self.lineEdit_OrarioLetto.setText(data_str)
    def leggiTensioni(self):
        errore, tensioni = self.LeggiDati(4, [0x04])
        size = len(tensioni)
        if errore != 0:
            return
        valori = struct.unpack('<2H', tensioni)   # > = big endian, H = unsigned short (2 byte)
        valori = [x / 1000 for x in valori]
        if errore != 0:
            return
        # definisco i valore dei display
        self.lcdNumberVBatt.display(valori[0])
        self.lcdNumberVBackup.display(valori[1])
        # imposto i valori sul simbolo batteria
        self.graphicBattery.voltage = valori[0]
        self.graphicBatteryBackup.voltage = valori[1]

    def leggiOrario(self):
        errore, datiTimestamp = self.LeggiDati(4, [0x05])
        size = len(datiTimestamp)
        if errore != 0:
            return
        timestamp = int.from_bytes(datiTimestamp, byteorder='little')
        dt = datetime.fromtimestamp(timestamp)
        data_str = dt.strftime("%Y-%m-%d %H:%M:%S")
        self.lineEdit_OrarioLetto.setText(data_str)            

    def Scrividati(self, dato, CMD):
            errore = 0
            data = 0
            hex_list = [0x00]
            self.ser.write(bytes(hex_list))
            self.ser.reset_input_buffer()
            ID = self.ser.read(1)
            if not ID:
                errore = 1
                return errore
            if ID and ID[0] == 0xAB:
                self.ser.write(bytes(CMD))
                statoACK = self.getACK()
                if statoACK == 0:
                    time.sleep(0.05)
                    self.ser.write(bytes(dato))
                    errore = 0
                    return errore
                else: 
                    errore = 4
                    return errore
            else:
                errore = 3
                return errore
                #self.ser.write(bytes(CMD))
                #ack = None
                #ack = self.ser.read(1)
                #if (len(ack) != 1):
                #    errore = 1
                #    return errore
                #if (ack == b'\xaf'):
                #    time.sleep(0.05)
                #    self.ser.write(bytes(dato))
                #    errore = 0
                #    return errore

    def LeggiDati(self, dimensioneAttesa, CMD):
        # controlliamo di essere collegati al nostro nodo
        self.ser.reset_input_buffer()
        errore = 0
        data = 0
        hex_list = [0x00]
        self.ser.write(bytes(hex_list))
        ID = self.ser.read(1)
        if not ID:
            errore = 1
            return errore, data
        if ID and ID[0] == 0xAB:
            self.ser.write(bytes(CMD))
            data = self.ser.read(dimensioneAttesa)
            if (len(data) != dimensioneAttesa):
                errore = 1
            #print("La variabile 'basi' è di tipo:", type(data))    
            return errore, data
        else:
            errore = 1
        return errore, data
    
    def invert_endianess(self, data):
        # Se è lista di interi, converte in bytes
        if isinstance(dato, list):
            dato = bytes(dato)
        elif not isinstance(dato, (bytes, bytearray)):
            raise TypeError("dato deve essere bytes, bytearray o lista di interi")
        # Inverte i byte
        inverted = dato[::-1]
        # Restituisce come bytes
        return bytes(inverted)

    #invertiamo l'endianess
    def split_bytes(self, data, sizes):
        parts = []
        offset = 0

        # inverto anche l'endianess di ogni chunk
        for size in sizes:
            chunk = data[offset:offset+size]
            parts.append(chunk[::-1])   # inversione endianess
            offset += size
        return parts

# qui carico le altre finestre che si possono aprire
class SetLoRaParam(QDialog):
    def __init__(self, parent):
    #def __init__(self, window):
    #    self.window = window 
        super().__init__(parent)
        self.main = parent
        loadUi("ui/setLoRaWindow.ui", self)
        self.connectSignalsSlots()

        rx = QRegularExpression("^[0-9A-Fa-f:]*$")
        validator = QRegularExpressionValidator(rx)
        
        num = QRegularExpression("^[0-9]*$")
        numberValidator = QRegularExpressionValidator(num)
        
        # carico i dati dalla schermata principale e copio le impostazioni, oltre a inserire le regole di scrittura
        self.line_devADDR.setText(self.main.line_devADDR.text())
        self.line_devADDR.setValidator(validator)  
        self.line_devADDR.setMaxLength(23)   #16 caratteri + 7 due punti
        self.line_devADDR.textEdited.connect(lambda t: self.format_hex_field(self.line_devADDR, t, bytes_len=4)) 

        self.line_NSK.setText(self.main.line_NSK.text())
        self.line_NSK.setValidator(validator)  
        self.line_NSK.setMaxLength(47)
        self.line_NSK.textEdited.connect(lambda t: self.format_hex_field(self.line_NSK, t, bytes_len=16))

        self.line_ASK.setText(self.main.line_ASK.text())
        self.line_ASK.setValidator(validator)  
        self.line_ASK.setMaxLength(47)
        self.line_ASK.textEdited.connect(lambda t: self.format_hex_field(self.line_ASK, t, bytes_len=16))

        self.lineEdit_appEui.setText(self.main.lineEdit_appEui.text())
        self.lineEdit_appEui.setValidator(validator)  
        self.lineEdit_appEui.setMaxLength(23)
        self.lineEdit_appEui.textEdited.connect(lambda t: self.format_hex_field(self.lineEdit_appEui, t, bytes_len=8))

        self.lineEdit_TXInterva.setText(self.main.lineEdit_TXInterva.text())
        self.lineEdit_TXInterva.setValidator(numberValidator)
        
        self.checkBoxADR.setChecked(self.main.checkBoxADR.isChecked())

        self.comboBox_DRSelection.setCurrentIndex(self.main.comboBox_DRSelection.currentIndex())


    def format_hex_field(self, line_edit, text, bytes_len, sep=":"):
        """
        Formatta un QLineEdit in esadecimale con separatore automatico.
        :param line_edit: QLineEdit da formattare
        :param text: testo corrente
        :param bytes_len: numero di byte (es. 8 → DevEUI)
        :param sep: separatore (default :)
        """
        # rimuove tutto ciò che non è hex
        clean = "".join(c for c in text if c in "0123456789ABCDEFabcdef")
        # limita alla lunghezza massima
        max_hex = bytes_len * 2
        clean = clean[:max_hex]
        # spezza in coppie
        pairs = [clean[i:i+2] for i in range(0, len(clean), 2)]
        # ricompone
        formatted = sep.join(pairs).upper()
        # evita loop
        if formatted != line_edit.text():
            line_edit.blockSignals(True)
            line_edit.setText(formatted)
            line_edit.blockSignals(False)

# qui definisco le azioni quando si preme qualcosa
    def connectSignalsSlots(self):
        self.pushSendLoRaConfig.clicked.connect(self.packAndSendLoRaData)

    def append_bytes_to_buffer(self, buf: bytearray, value: bytes, length_counter: list):
        if not isinstance(value, (bytes, bytearray)):
            raise TypeError("value deve essere di tipo bytes o bytearray")
        buf.extend(value)
        length_counter[0] += len(value)

    def packAndSendLoRaData(self):
        dimensioniLoRa = [4, 4, 8, 16, 16, 4, 4]
        buffer = bytearray()
        counter = [0]
        tempCounter = [0]
        #DR, DevAddr, AppEUI, NSK, ASK, TXT, ADREnab = self.split_bytes(LoRaDati, dimensioniLoRa)
        #attacco tre zeri per fare 4 byte per il DR

        #tempVV = self.comboBox_DRSelection.currentText()
        #self.main.comboBox_DRSelection.currentIndex()
        #num_str = int("".join(re.findall(r"\d+", tempVV))).to_bytes(1, 'little')
        num_str = self.comboBox_DRSelection.currentIndex().to_bytes(1, 'little')
        self.append_bytes_to_buffer(buffer, num_str, tempCounter)
        self.append_bytes_to_buffer(buffer, b'\x00\x00\x00', tempCounter)
        self.append_bytes_to_buffer(buffer, bytes.fromhex(self.line_devADDR.text().replace(":", ""))[::-1], tempCounter)
        self.append_bytes_to_buffer(buffer, bytes.fromhex(self.lineEdit_appEui.text().replace(":", ""))[::-1], tempCounter)
        self.append_bytes_to_buffer(buffer, bytes.fromhex(self.line_NSK.text().replace(":", ""))[::-1], tempCounter)
        self.append_bytes_to_buffer(buffer, bytes.fromhex(self.line_ASK.text().replace(":", ""))[::-1], tempCounter)
        tempValue = int(self.lineEdit_TXInterva.text())*1000
        self.append_bytes_to_buffer(buffer, tempValue.to_bytes(4, 'little'), tempCounter)
        #attacco tre zeri per fare 4 byte legate al bool
        if self.checkBoxADR.isChecked() == True:
            self.append_bytes_to_buffer(buffer, b'\x01', tempCounter)
        else:
            self.append_bytes_to_buffer(buffer, b'\x00', tempCounter)
        self.append_bytes_to_buffer(buffer, b'\x00\x00\x00', tempCounter)
    
        # ora posso inviare i dati
        errore = self.main.Scrividati(buffer, [0x03])
        statoACK = self.main.getACK()

        if (errore == 0 and statoACK == 0):
            QMessageBox.information(self, "invio corretto", "Inviati tutti i campi LoRa")
            self.close()
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

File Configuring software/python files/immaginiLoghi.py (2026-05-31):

# Resource object code (Python 3)
# Created by: object code
# Created by: The Resource Compiler for Qt version 6.11.1
# WARNING! All changes made in this file will be lost!

# from PySide6 import QtCore <-- replace this line
from PyQt6 import QtCore

qt_resource_data = b"\
\x00\x00\x80W\
\x89\
PNG\x0d\x0a\x1a\x0a\x00\x00\x00\x0dIHDR\x00\
\x00\x01\xe4\x00\x00\x00\x8e\x08\x06\x00\x00\x00\xe0\xb6{q\
\x00\x00\x00\x09pHYs\x00\x00\x0b\x13\x00\x00\x0b\x13\
\x01\x00\x9a\x9c\x18\x00\x00\x05\xd1iTXtXML\
:com.adobe.xmp\x00\x00\
\x00\x00\x00<?xpacket beg\
in=\x22\xef\xbb\xbf\x22 id=\x22W5M\
0MpCehiHzreSzNTc\
zkc9d\x22?> <x:xmpm\
eta xmlns:x=\x22ado\
be:ns:meta/\x22 x:x\
mptk=\x22Adobe XMP \
Core 5.6-c145 79\
.163499, 2018/08\
/13-16:40:22    \
    \x22> <rdf:RDF \
xmlns:rdf=\x22http:\
//www.w3.org/199\
9/02/22-rdf-synt\
ax-ns#\x22> <rdf:De\
scription rdf:ab\
out=\x22\x22 xmlns:xmp\
=\x22http://ns.adob\
e.com/xap/1.0/\x22 \
xmlns:xmpMM=\x22htt\
p://ns.adobe.com\
/xap/1.0/mm/\x22 xm\
lns:stEvt=\x22http:\
//ns.adobe.com/x\
ap/1.0/sType/Res\
ourceEvent#\x22 xml\
ns:dc=\x22http://pu\
rl.org/dc/elemen\
ts/1.1/\x22 xmlns:p\
hotoshop=\x22http:/\
/ns.adobe.com/ph\
otoshop/1.0/\x22 xm\
p:CreatorTool=\x22A\
dobe Photoshop C\
C 2019 (Windows)\
\x22 xmp:CreateDate\
=\x222025-10-17T17:\
16:15+02:00\x22 xmp\
:MetadataDate=\x222\
025-10-17T17:16:\
15+02:00\x22 xmp:Mo\
difyDate=\x222025-1\
0-17T17:16:15+02\
:00\x22 xmpMM:Insta\
nceID=\x22xmp.iid:3\
5f33471-12a3-b34\
c-a9bb-808ff4a0a\
c5b\x22 xmpMM:Docum\
entID=\x22adobe:doc\
id:photoshop:4c3\
76cbd-c2a0-c649-\
a72a-6121b0ee446\
7\x22 xmpMM:Origina\
lDocumentID=\x22xmp\
.did:219cbe64-16\
e0-764f-8e9d-cfc\
53ef0d143\x22 dc:fo\
rmat=\x22image/png\x22\
 photoshop:Color\
Mode=\x223\x22> <xmpMM\
:History> <rdf:S\
eq> <rdf:li stEv\
t:action=\x22create\
d\x22 stEvt:instanc\
eID=\x22xmp.iid:219\
cbe64-16e0-764f-\
8e9d-cfc53ef0d14\
3\x22 stEvt:when=\x222\
025-10-17T17:16:\
15+02:00\x22 stEvt:\
softwareAgent=\x22A\
dobe Photoshop C\
C 2019 (Windows)\
\x22/> <rdf:li stEv\
t:action=\x22saved\x22\
 stEvt:instanceI\
D=\x22xmp.iid:35f33\
471-12a3-b34c-a9\
bb-808ff4a0ac5b\x22\
 stEvt:when=\x22202\
5-10-17T17:16:15\
+02:00\x22 stEvt:so\
ftwareAgent=\x22Ado\
be Photoshop CC \
2019 (Windows)\x22 \
stEvt:changed=\x22/\
\x22/> </rdf:Seq> <\
/xmpMM:History> \
</rdf:Descriptio\
n> </rdf:RDF> </\
x:xmpmeta> <?xpa\
cket end=\x22r\x22?>!\xf3\
\xc9R\x00\x00z,IDATx\xda\xed]\x07|\
\x14\xd5\xf6>3\xb35\xbb\xd9M\xef\x95\x84\x84\x14\x08\
\x04\x02\xa1\xf7^\x1f\x8a\x0f\x1f\xa2\xa2\xa0\xe2\x13\xc5\xfa\
T\x14\x04\xc1\xfal\x7f\xbb\x22\xa8OTD\x10\xa4I\
\xef%\x09\x01\x02!!!!\xbd'\x9bl\xda\xd6\x99\
\xf9\xdf;\xbb\x1b6\x8d\x9e\x80p?\x7f#\xd9\xdd\xd9\
\xd9\xb9wf\xeew\xbes\xcf=\x87\xe2y\x1e\x08\x08\
\x08\x08\x08\x08\x08n-h\xd2\x05\x04\x04\x04\x04\x04\x04\
\x84\x90\x09\x08\x08\x08\x08\x08\x08\x08!\x13\x10\x10\x10\x10\
\x10\x10B&       \x84L@@@\
@@@\x08\x99\x80\x80\x80\x80\x80\x80\x80\x102\x01\x01\
\x01\x01\x01\x01!d\x02\x02\x02\x02\x02\x02\x02B\xc8\x04\
\x04\x04\x04\x04\x04\x84\x90\x09\x08\x08\x08\x08\x08\x08\x08!\
\x13\x10\x10\x10\x10\x10\x10B&       \
\x84L@@@@@@\x08\x99\x80\x80\x80\x80\x80\x80\
\x80\x102\x01\x01\x01\x01\x01\x01!d\x02\x02\x02\x02\x02\
\x02\x82\xdb\x81\x90\xb9\x9aj9W\xad\x91\x93\xee& \
    h\x1b\x14\xcf\xf3\x1d\xfe#)\xcf=\x99\
HKe\x0d\xdd\xdf\xfep8\xe9r\x02\x02\x02\x02\x02\
\x82\xd6\x10u\xf4\x0f\xe8\x0a\xf2\xfc\xb5gS\xe2\x18\x99\
\x1c\x0c\xe5e.R\x0fO\xcd\xdf\xa9\x83\x1ar/\x06\
\x19kj\xbc\xcc5\xd5>\xa6\xeaj/\xd6hP\x00\
\xf0@1\x0c+vT\x97\x89\x9d]\x8a\xc4NNe\
\x12W\xd7b\xa9\xab\xbb\xf6N\xbbA\x1ar\xb2\x19\xa3\
\xb6&\x1e\xb5\xdd\xd3\x84\xfa\x81\x13\xda\x0f\xb8\xfdF\xb1\
J])vq)\x92\xa8\xd5e\x12\x17\xb7\x02\x89\xab\
[\xfd\xed\xde\x9e\xcc\xcc\xcc0d\x842\xf8oOO\
\xcfl'''#\x19\x06\x08\xeeFT7j\xe4\xce\
\x0e.:\xd2\x13w\x11!\x9bj\xb5\xee<\xc7\x01g\
6\x83\xa9\xae\xd6\xedv'd]I\x91gm\xea\x99\
Q\xda3)#\x1b.f\xc7\xea\x8a\xf2\xa3\xd1y3\
\x9c^\x0f,\xdax\x9e\xb3\xb8\x16\xd0\x7f\xb4D\x02\x8c\
L\x06\x8c\xdc\x01\xa4^\xde\x05\x0e\x81\xc1)\xaa\x88\xa8\
\x83N1=w:v\x8bJ\xf9;\xde\x10\x8d\x85\x05\
>\xb5\xa9)\xa3\xb4\xa9gJ\x1a/f\xf7n,*\
\x883\xd7\xd5N\xc7m\xe7\x0c\x06d\x8bp\x80}*\
\x14\x85\xda/\xb6\xb6\xdfA\x012\xdc\xfe\xa0\xe0\x14u\
T\xf7\xdd\xaa\xe8\x98=\x8e\xe1\x11\xa9\xb7[\xdbv\xec\
\xd81\xf3\xb9\xe7\x9e\xfb\xc5\xe6\x15z\xf1\xc5\x17\x97\xcc\
\x993g\x19\x19\x06\x08\xee6d\x94\x9e\x8f\xd8\x9d\xbd\
g\xaeH$2F\xb8E\x1e\x0cp\xf2K\x0fr\x0d\
\xce%=s\x87\x13\xb2Y\xd7\xa8\xe2\x8cF4\x8e\xb3\
\xc066\xaao\xd7\x8e\xa8J8:\xb2|\xcf\xce\xc7\
kN%M\xd2\x17\x17\xc9\xcd\x0d\x8d\x98u\x80f\x90\
\x98\x12\xd1@\xd1\x0c\x22^\x99@\xc56`C\xc3\x8c\
\x88\xca\xdc\xd0\x00\xfa\xf2R\xff\x9a\x93'\xfcK\xb7n\
\x9a$qs{O\xd5-2\xc9m\xe8\xa8\xef\xdd\x06\
\x0f\xfbQ\xea\xeaz\xdb+\xc7\xca\xa3\x87\xc7\x94\xef\xf9\
\xeb\xc9\x9aS'\xc7\xebK\x8a$\xac\x1e\xb5\x1fh\xa0\
E\xa8\xfd\xa8\xedH\x11\xb7n?\x8f\xdb\xaf\xb3\xb4\xbf\
\xb4\xd8\xbf\x1a\xb5\xbfd\xf3\xc6IRw\x0fp\x8c\x88\
:\xee1|\xd4w\xae\x03\x87\xac\x918\xdf\x1eVx\
]]\x9dKZZ\xda\xa5k^U\xe5C\x86\x00\x82\
\xbb\x11h\x5c\xbb\xb0\xef\xe2~\x97\xfd\xb9\xfb\x1f\xf6S\
\xf9\xbd\xdc\xc3\xabGv\x0f\xef\xee\xbbC\xddBO\x04\
\xa8\xfd\xd3=\x15\x1e9\xbeN\xfe\xc5\xa4\xa7\xee0B\
\xe6\xf4\x06%o2\x09\xca\x8a3\xe8\x15\xb7\x1d\x11\x1d\
\xde?\xa9p\xdd\xafK\xabO%\xc5\xb2uu@\x89\
D@\x89\xc5 rt\x14T \xe6\x1f\xfbivL\
G\xb6\x97\x14M\x0b\xaf\xa9K\x0c\x05\x1c\x22i\x93\xa6\
\x0a*\x0e\xec\x8d\xab<r(N\xd1%\xf4-\x9f\xc9\
\xffx\xdfs\xec\xc4O\xa4n\xb7\x9fK\xb7\xe2\xe0\xde\
\xa9\x85\xeb~YZs*9\xc6\xdcP\x8f\x08Xl\
i\xbfRei\xbf\xb5\xbd\xb66\xdaG\x1c s\x05\
\x11\xb5\xa8Y\x9f\xf0,\x0b\xc6\xaaJ\xa8\xd8\xbb+\x1e\
\xf5m\xbc24\xfc-\x9f)\xd3\xdf\xf7\x1c=\xeeK\
\x89\xcb\xad5L\x18<\xcd\x80\xdaf\xc2\xf7#\x82D\
\x22\xd1\x93!\x80\xe0nDW\xf7\xae\xe6(\xaf\xe8\x8d\
\x7feo{8\xa5\xf84\xa4V\xa5\x86l\xbe\xa0\x0c\
q\x91;?\xee\xaf\xf2\x83P\x97\x90\xf4\x08\xf7\xc8#\
\xdd\xbdcv\x86\xba\x86&uq\xe9B\xd4\xf3\x9d@\
\xc8\xbc\xd1(\xc7\xea\x98\xe2i\xe0L\xc6\xdb&\xd2\xba\
6#=:\xff\xc7\xef>\xae\xd8\xbf{\xa4\xb9\xb1Q\
p;3\x8e\xaaK\xc4\x83\xc8\x15o\x94\x95\x91m\xe4\
\x04\xcd4\xa2e?\xac\xa4mnP\x9a\xa1\xd1\xc8/\
\x03J\x8a\xd4$\x22\xe7\xfa\x0b\xe7\xd5\x99\x1f\xbc\xb5\xbc\
\xec\xaf\xad\x0b\x02\x1ex\xf8y\xcf\xb1\x13\xd6\xdc\x16\xed\
O;\x1b\x9b\xfb\xc3\xaa\x0f*\x0f\xee\x1d\xc6\xeat \
rp@FH\x1b\xed\xa7\xec,\x12\x8aj\xd6v\xfc\
>\xdf\xda\xf2\xc6\xcc\x87\xda/\x15\xda_w\xfe\x9c{\
F\xfa\xb9\xf7J\xb7oY\x10\xf8\xe0\x9c\xe7=F\x8c\
YG\x1e;\x02\x82[\x8f\xd1\xa1#\xf6\xfd\x95\xb5\x0d\
\x12\xf3\x13\x81\xe5\xcdP\xa3\xaf\x81\x1a]\x0d\x5c\xac\xc9\
\x81c\x05\xc7\x22\x1c%\xaa\x08w\xa5\xe7\xdc(\x8f\xa8\
\x8a\x11]\x86\x7f?*d\xd4\xca0\xf7\xb0L\xd2s\
\x7fcBfM&\x890\xb8sH=\x1an\x0fB\
.\xfc\xfd\x97\xe7rW\xaf\xfc@W\x90\x07\x8cR\x01\
b\x95\x93en\xd4\x9ex\xec\x09\x98\xa2\xda=\x96\xed\
\xb3f\xfb\x08D\x8e\xfe\xa1)\xa44\x1d\x05b\xaa9\
{\xda\xb3\xee\x8dW\x7f\xd2$'L\x0fzx\xde\x93\
r\x1f\xbf\xb2[\xd5\xfe\xfc_~|9\xef\xc7\xef\xde\
\xd6\x17\x15\x02\xa3P\x82X\xad\xb6\x90\xeb\xb5\xb6\xdf\x8e\
\xa0[\x12\xb50\xcbN\xd3\x97\xda\x7f:\xd9\x1f\x19'\
\xbfiN$\xae\x09zh\xee\xd32O/\x0dy\xfc\
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

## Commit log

2026-05-31 python interface, exe file and 3D cad files
    [All_outline.step, BOM-Braccio.csv, BOM-Piste.csv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]
2026-06-01 Added schematics and KiCad files
    [AlimentazionePinze.kicad_sch, Avoir.kicad_sch, BOM-LoRa Pinze Sent.csv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]
2026-06-02 Added Chirpstack decoder, updated battery reading
2026-06-08 updated 3d models folder
    [Rendering.FCStd, Spessore_braccio.stl, Spessore_centrale.stl]
2026-06-08 LX3320A FW added
    [lx3302a_config.txt]
2026-06-15 .nc teflon disks files addes
    [Rendering.FCStd]
